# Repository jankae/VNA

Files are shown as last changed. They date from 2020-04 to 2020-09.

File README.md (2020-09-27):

# 1MHz - 6GHz VNA

**There is a [new and improved version](https://github.com/jankae/VNA2) of this project under development**

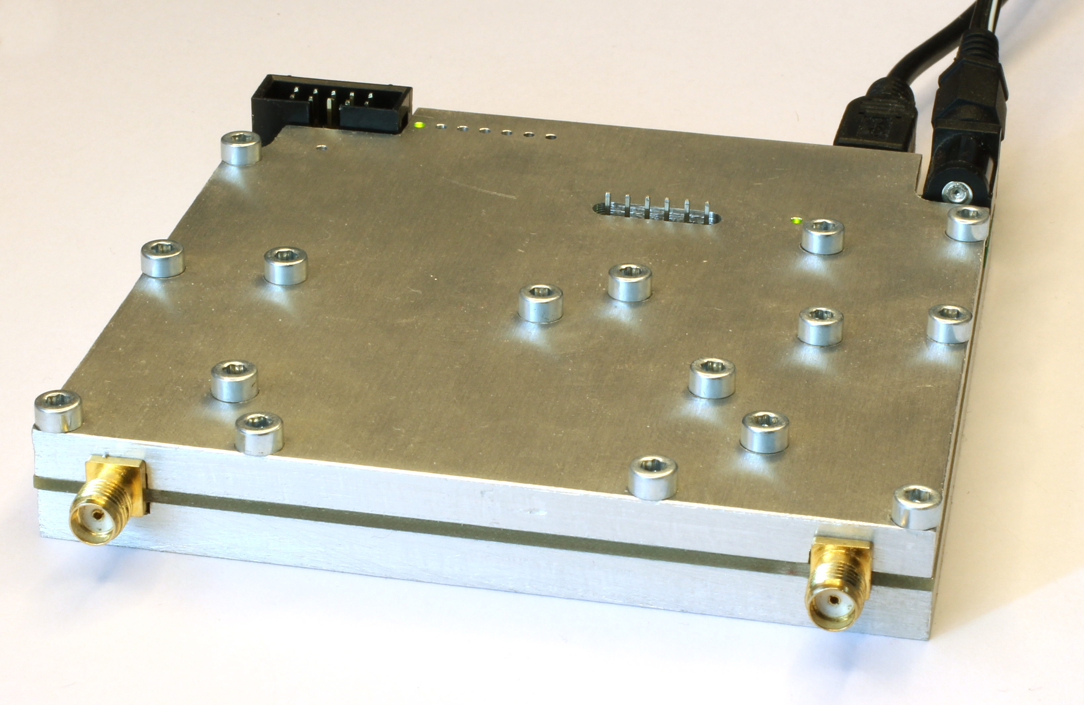
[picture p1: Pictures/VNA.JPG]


## Motivation
A VNA can be very helpful for RF experiments so I decided to build one for my next project. I already own a [pocketVNA](https://pocketvna.com/), however I found some issues with it and didn't use it very often:
* High thermal drift: you have to leave it running for 30-45 minutes before using it
* Low sweep speed: Especially with averaging enabled, a sweep can take a few minutes
* Ports are not 50 Ohm terminated, see also discussion [here](https://www.eevblog.com/forum/rf-microwave/pocketvna-any-idea-what-its-like/msg1220143/#msg1220143)

There already are some other DIY VNA projects online, especially [these](https://hforsten.com/cheap-homemade-30-mhz-6-ghz-vector-network-analyzer.html) [two](http://www.yl3akb.lv/content/vna_v2/vna_v2.php) served as inspiration. Especially the first link also explains some general concepts of a VNA, what it is used for, how it works and some compromises when choosing a hardware architecture.

## Design goals
* 1MHz to 6GHz usable frequency range. Both limits are essentially set by the specs of affordable RF ICs.
* Reasonable fast sweep speed
* No display, instead the data is send via USB to a PC. Generally, I prefer standalone devices but it seemed not worth the effort here. To be usable, the display would need to be reasonable large and high resolution, also GUI development is faster/easier on a PC than on a µC.
* BOM cost reduction is *not* the primary goal. A project like this takes several month and its a one-off device, slightly higher than absolutely necessary part costs are not an issue.
* Learn more about the challenges in RF designs.

## How does it work?


* The main clock source is an Si5351C, providing all the required clocks for the different blocks. It also serves as the stimulus source for frequencies below 25MHz. Its own reference clock is either a 26MHz crystal or an external 10MHz signal.
* The stimulus source for frequencies above 25MHz is a MAX2871. Its output signal is slightly filtered to reduce the amount of harmonics.
* The stimulus signal power can be adjusted between approximately -42 and -10dbm with a digital attenuator (F1958).
* After the amplifier(TRF37A73) the signal is split and the weaker part of it fed into the reference receiver.
* The stronger part of the signal can be routed to either port. In each signal path, two RF switches are used in series to achieve higher isolation between the ports.
* Instead of directional couplers, resistive return-loss-bridges are used (easier to implement for wide bandwidth).
* Both ports have completely separated receive paths. This increases BOM cost but allows measuring two parameters at once (S11 and S21 or S22 and S12). It also avoid potential isolation issues that could arise if the receive paths would merge into a single mixer/ADC.
* Each receiver consists of two down-convert mixers. The 1.IF sits at 60MHz, the 2.IF 250kHz.
* The ADCs are sampling the final IF with 16bit@1MHz.
* The acquisition and control of the PLLs, switches, attenuator etc. is handled by a Spartan 6 FPGA. This allows for nearly instant switching of the measurement frequency, only limited by the settling time of the PLLs.

## PCB Layout
The signal path can also be followed on the PCB (the attuator is replaced by a wire bridge in this picture because I damaged the IC during soldering):
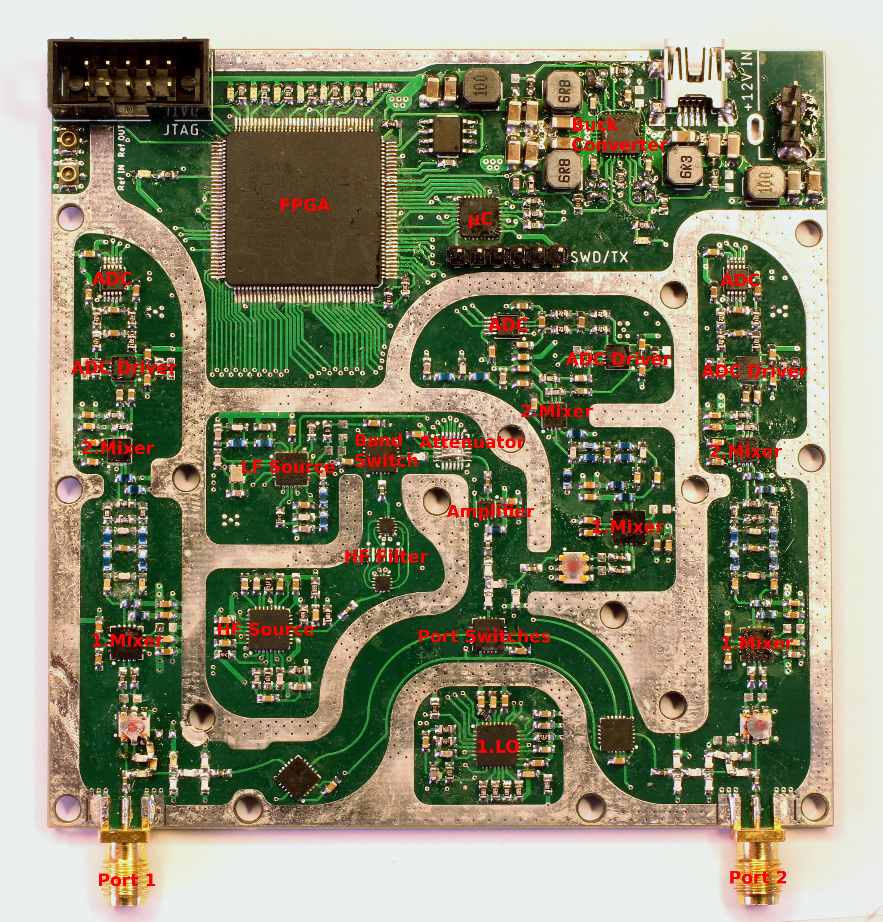
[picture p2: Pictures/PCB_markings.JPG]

* I limited myself to 10x10cm, because larger 4-Layer PCBs are getting a bit more expensive at the typical manufacturers. This was a mistake because it meant that certain sections had to move closer together. Especially the distance between the HF Source and the 1.Mixer of Port 1 is not sufficient, resulting in less than optimal isolation.
* The individual sections are divided by strips of exposed GND. The aluminium case touches all the exposed copper and further improves shielding. I expected the shielding to be better than it turned out, this is another reason why I put sections close to each other that really should be some distance apart.
* For some reason I didn't check the final design carefully enough before ordering and didn't have enough GND vias in quite a few areas. This probably degrades overall performance but I am not going to reorder (and solder!) a new PCB.

### Some hardware-related points worth noting
* There is a lot of local voltage regulation to prevent coupling of supply noise between the sections. In total there are 14 different supply rails (although most of them are at 3.3V or 5V).
* The triple Buck converter for stepping down the main 12V input rail to 6V/3V3 and 1V8 has a synchronisation feature. The synchronization pin was connected to the FPGA in order to sync the converter to the ADC sampling rate and prevent switching noise from being measured. I ended up having to cut that trace because the Spartan 6 switches its pins to pullups while being configured from the ISE IDE. This caused the buck converter to stop and the board to lose power. Note that the HSWAPEN pin only affects the pullups when configuring from the *Flash* not from the IDE. See also [this](https://forums.xilinx.com/t5/Spartan-Family-FPGAs-Archived/Spartan-6-pull-ups-during-SPI-indirect-programming-using/td-p/201743) issue. The missing synchronisation ended up not being a problem as the buck converter frequency is far enough away from the final IF.
* Due to 16bit resolution at 1MSPS, the ADCs need a fast SPI interface. Initially I used a 100MHz SPI clock and this worked well for the port 1 and the reference ADC but didn't work with the port 2 ADC (it is farther away from the FPGA thus the traces were longer). Decreasing the SPI clock to about 70MHz solved the issue while still being fast enough for the ADCs.
* The LTC5510 mixers and MAX2871 PLLs get warm (overall power consumption is about 6W, most of it dissipated in these ICs), they reached up to 70°C with an ambient temperature of 25°C. I changed the aluminium shielding design to extend down to these ICs and also serve as a heatsink. This reduced the maximum temperature by about 20°C.

## The shielding
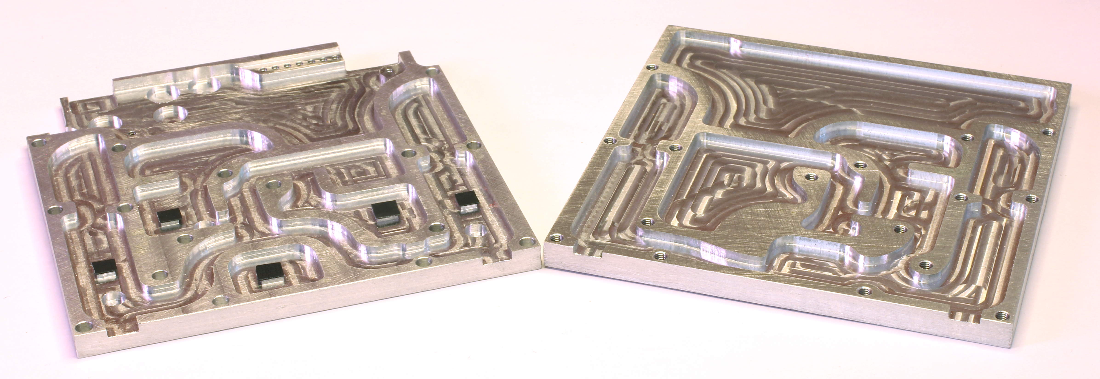
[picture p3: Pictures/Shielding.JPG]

The shielding serves multiple purposes:
* Providing RF isolation between different sections
* Improving EMI/EMC
* Serving as a case for the device, preventing shorts on the PCB when used on the bench
* Cooling (the black rectangles on the left aluminium part are adhesive cooling pads and touch the top of some ICs)
* It was CNC-machined out of 6mm aluminium. Being able to use a CNC mill, I wasn't restricted to right angles and optimised the shielding to allow for a smaller board.
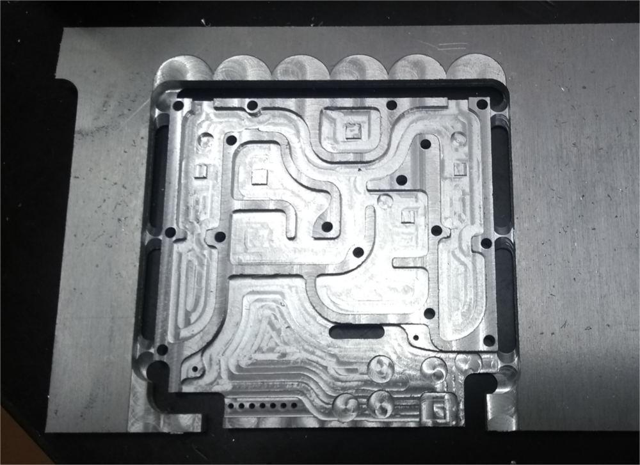
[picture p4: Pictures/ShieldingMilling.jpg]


## PC Software
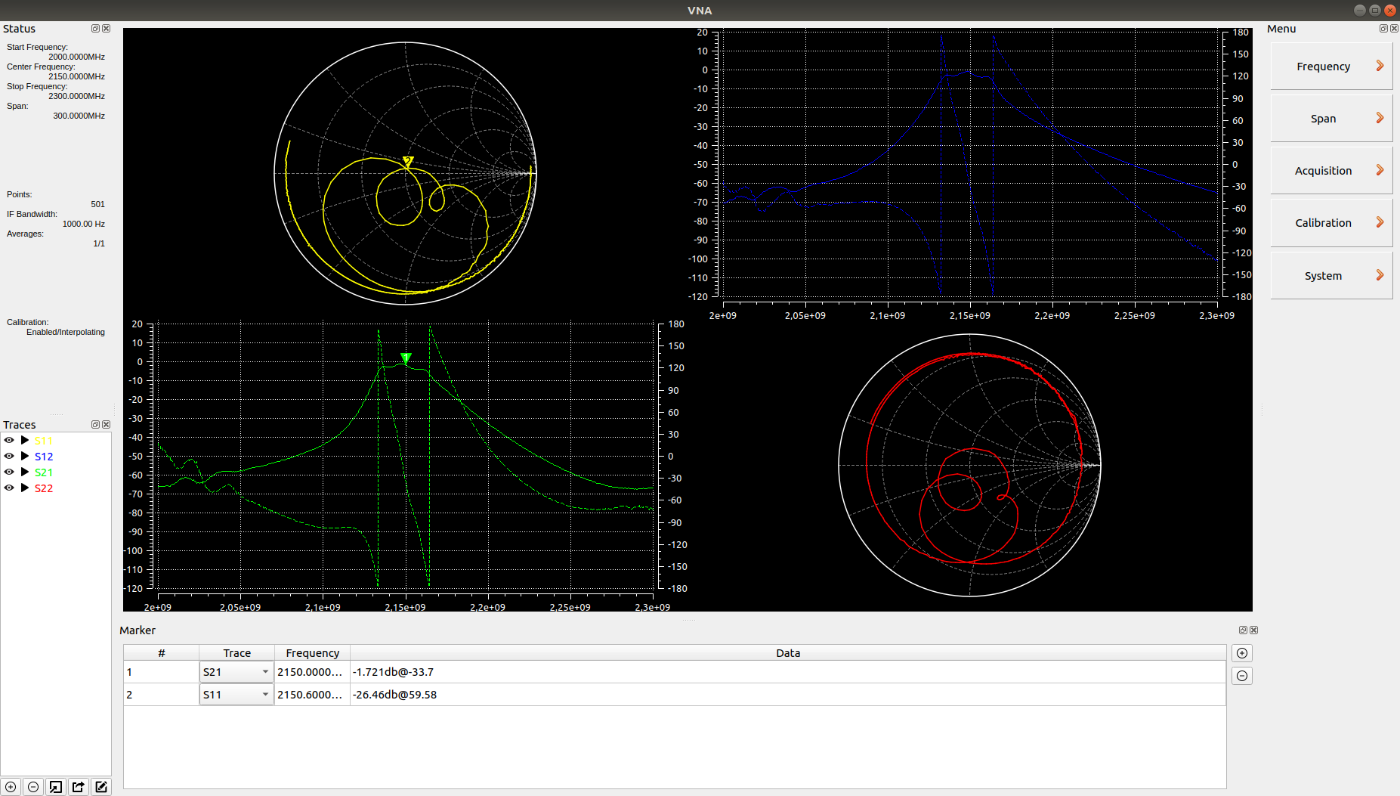
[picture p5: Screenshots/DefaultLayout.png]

* Written in Qt. This was my first PC software with a GUI and it took a while (and many lines of code that were rewritten a lot) to understand the concepts. While certainly not optimal, the result is absolutely usable for me.
* Flexible display of measurements in charts (Smithchart/Bodeplot). Each chart can be assigned a number of traces (e.i. plot S22 and S11 in one smithchart). The charts can be resized, moved, deleted or split into more charts.
* Import/export of touchstone files up to 4 ports. This allows saving measurements and also comparing the current measurement with others.
* Rudimentary marker system to read S-parameters at any frequency.
* Full control over start/center/stop frequencies, span, IF bandwidth, number of points, stimulus power level, ...
* SOLT calibration with fully customizable calibration kit (either from coefficients or touchstone measurements):
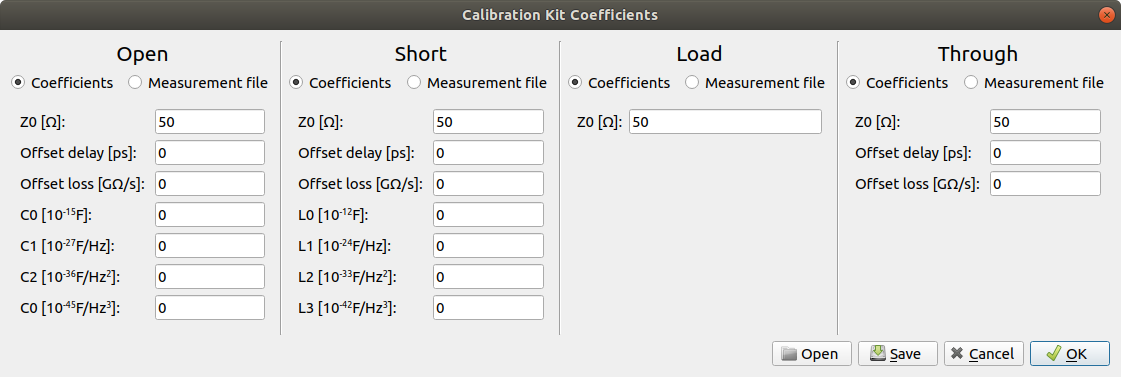
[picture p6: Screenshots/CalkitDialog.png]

* Manually control of the hardware components (helpful for hardware debugging or using the device as a simple signal source):
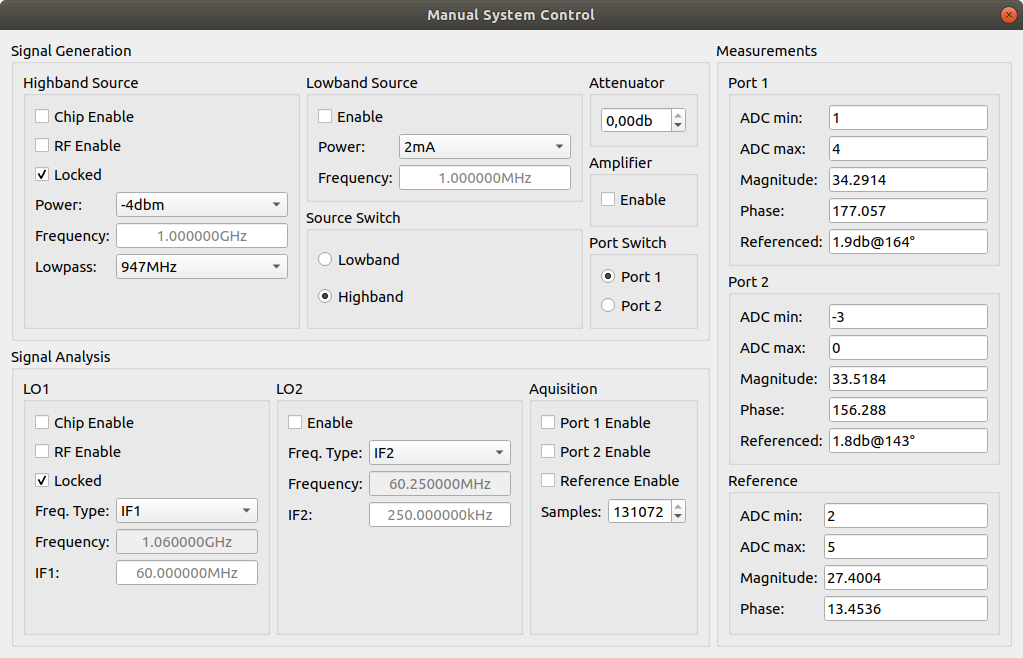
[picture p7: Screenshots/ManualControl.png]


## How well does it work?
I am really not that sure, as I have no RF equipment to compare it to. A VNA can only be as good as the calibration kit and the only calibration kit I have is the on that came with the pocketVNA, which does not have any calibration coefficients. Why is that a problem? No calibration kit is perfect and the coefficients allow the VNA to take the imperfections into account. Without the coefficients these imperfections will be propagated to the measurements. As calibration kits with coefficients easily cost more than this whole project (at least the ones I could find) this situation will probably not change soon.

That being said, here are a few measurements:
* Isolation between ports with (green) and without (red) shielding (1MHz to 6GHz, 501 points, 100Hz IF bandwidth, both ports terminated into 50 Ohm):
  * S12:
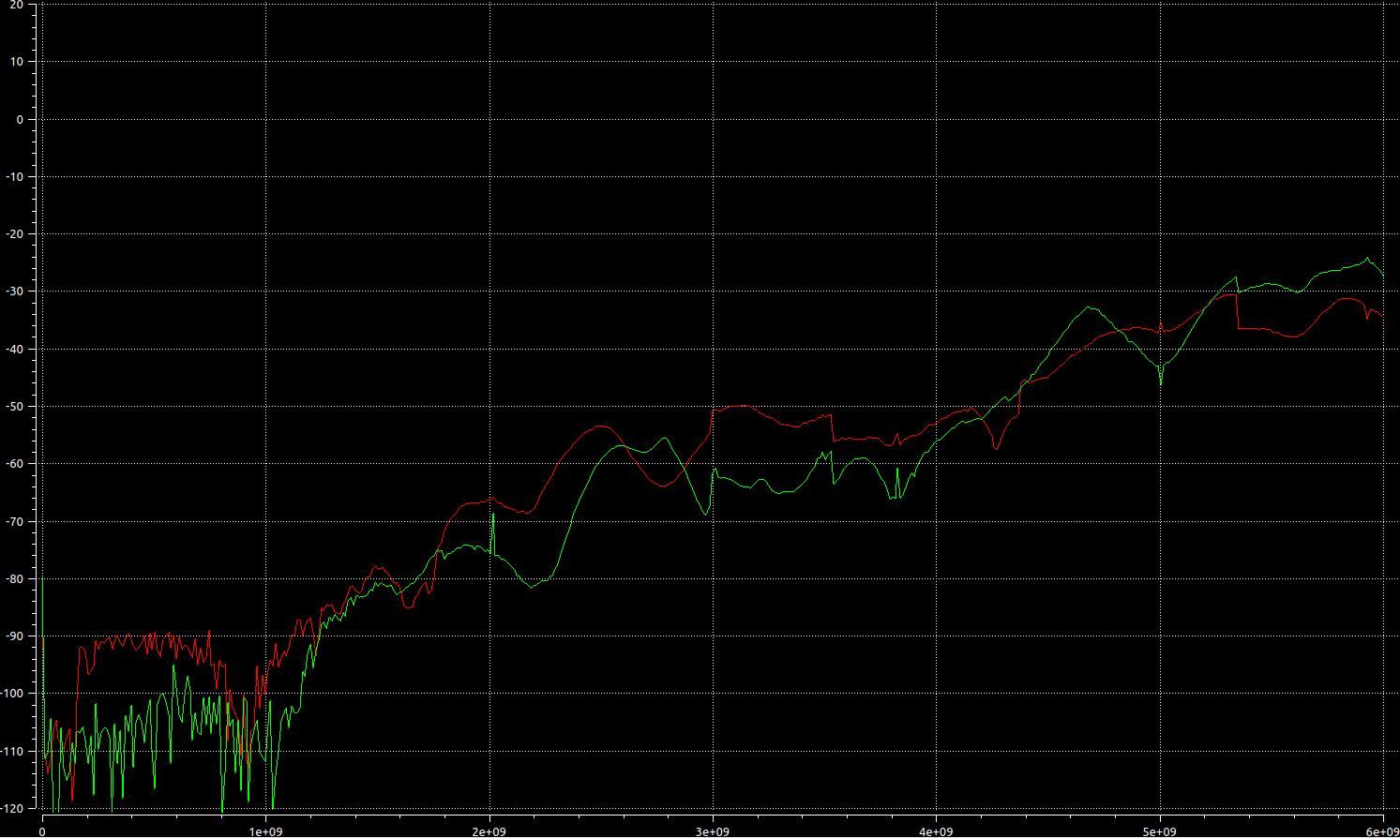
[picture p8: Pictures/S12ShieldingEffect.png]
  
  * S21:
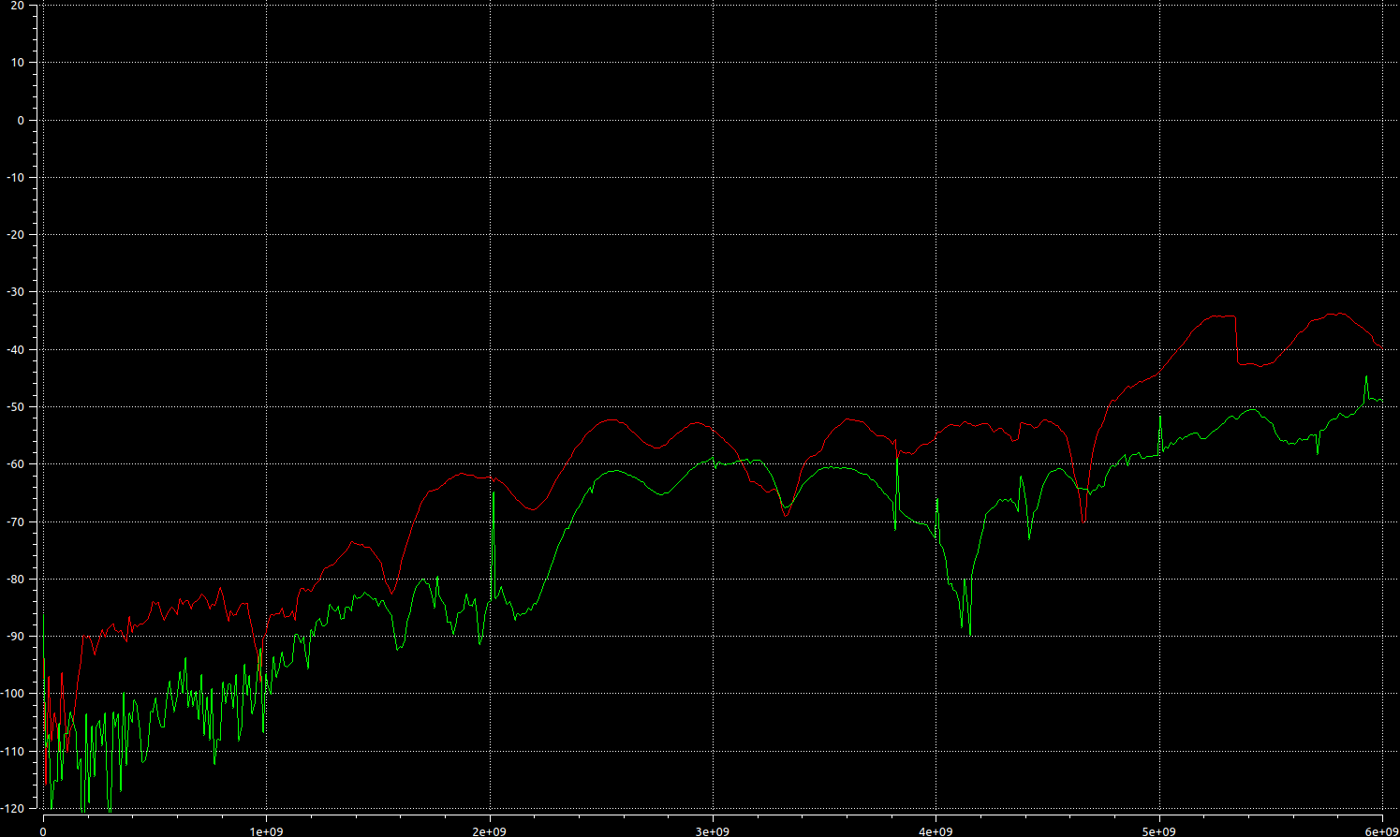
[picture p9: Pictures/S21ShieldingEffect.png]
  
  * Below about 1GHz the noise floor is the actual noise floor of the ADC. Above 1GHz more and more signal leaks into the other port. This leakage is a bit worse at port 1 (S12) because the HF source is placed close to the port 1 mixers. The shielding improves the isolation somewhat but not to the extend I had hoped. Interestingly there are some peaks in the isolation sweep when the shielding is used. My best guess is that they are caused by the cavities in the shielding acting as waveguides. I am hoping to improve the shielding by adding RF absorbers to some parts of the aluminium.
* The cavity bandpass filter from [this](https://github.com/jankae/SpectrumAnalyzer) project (1.9GHz to 2.3GHz, 501 points, 1kHz IF bandwidth):
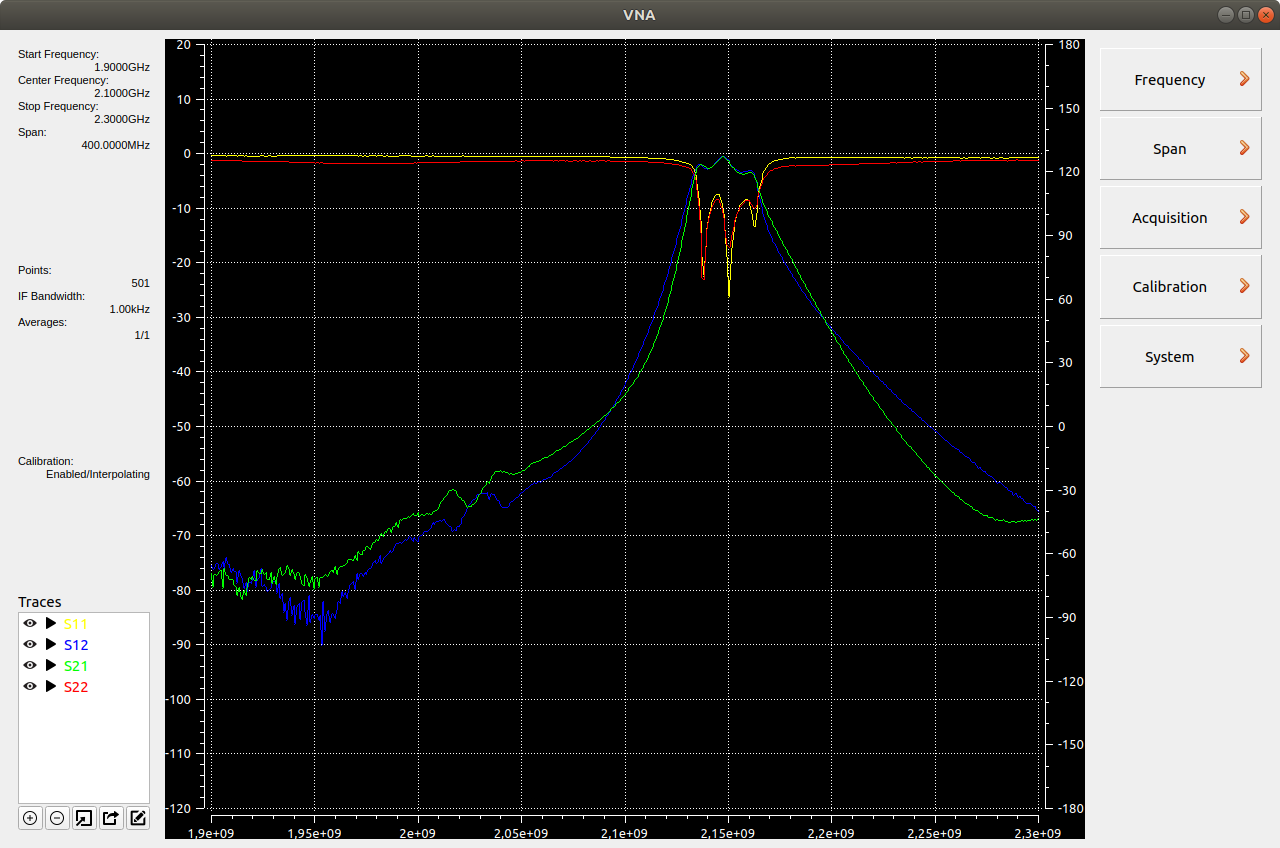
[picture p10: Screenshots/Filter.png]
 
* A WLAN antenna that seems to be somewhat reasonable matched between 2.3GHz and 2.6GHz:
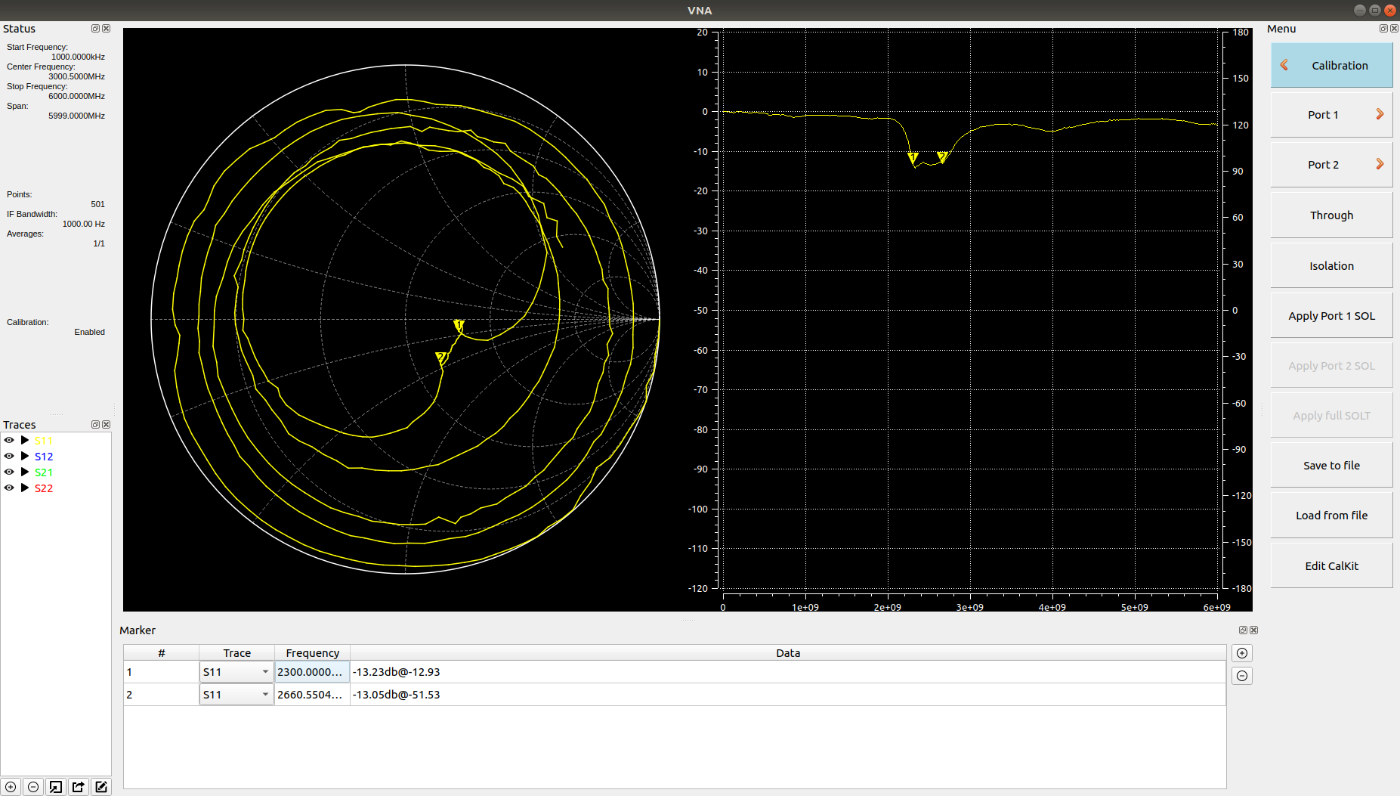
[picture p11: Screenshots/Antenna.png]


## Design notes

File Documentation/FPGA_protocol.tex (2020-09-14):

\documentclass{article}
\usepackage
[
        a4paper,% other options: a3paper, a5paper, etc
        left=2cm,
        right=2cm,
        top=2cm,
        bottom=2cm,
        % use vmargin=2cm to make vertical margins equal to 2cm.
        % us  hmargin=3cm to make horizontal margins equal to 3cm.
        % use margin=3cm to make all margins  equal to 3cm.
]
{geometry}
\usepackage{tikz}
\usepackage{siunitx} 

\pgfdeclarelayer{background}
\pgfdeclarelayer{foreground}
\pgfsetlayers{background,main,foreground}

\newcommand{\bitrect}[2]{
  \begin{pgfonlayer}{foreground}
    \draw [thick] (0,0) rectangle (#1,1);
    \pgfmathsetmacro\result{#1-1}
    \foreach \x in {1,...,\result}
      \draw [thick] (\x,1) -- (\x, 0.8);
  \end{pgfonlayer}
%  \node [below left, align=right] at (0,0) {Type \\ Reset};
  \bitlabels{#1}{#2}
}
\newcommand{\rwbits}[3]{
  \draw [thick] (#1,0) rectangle ++(#2,1) node[pos=0.5]{#3};
  \pgfmathsetmacro\start{#1+0.5}
  \pgfmathsetmacro\finish{#1+#2-0.5}
%  \foreach \x in {\start,...,\finish}
%    \node [below, align=center] at (\x, 0) {R/W \\ 0};
}
\newcommand{\robits}[3]{
  \begin{pgfonlayer}{background}
    \draw [thick, fill=lightgray] (#1,0) rectangle ++(#2,1) node[pos=0.5]{#3};
  \end{pgfonlayer}
  \pgfmathsetmacro\start{#1+0.5}
  \pgfmathsetmacro\finish{#1+#2-0.5}
%  \foreach \x in {\start,...,\finish}
%    \node [below, align=center] at (\x, 0) {RO \\ 0};
}
\newcommand{\bitlabels}[2]{
  \foreach \bit in {1,...,#1}{
     \pgfmathsetmacro\result{#2}
     \node [above] at (\bit-0.5, 1) {\pgfmathprintnumber{\result}};
   }
}

\begin{document}

\section{Digital Interface}
\begin{center}
\begin{tabular}{ c|c|c }
Pin & Direction & Function\\
 \hline
SCK & in & SCK for SPI communication/SCK for PLL communication\\
MOSI & in & MOSI for SPI communication/MOSI for PLL communication\\
MISO & out & MISO for SPI communication/MUX for PLL communication\\
NSS & in & Chip Select for SPI communication/LE for PLL communication\\
INTR & out & Active high interrupt indicator\\
RESET & in & FPGA reset\\
AUX1 & in & Selector for direct communication with Source PLL\\
AUX2 & in & Selector for direct communication with LO PLL\\
AUX3 & in & Active low sweep enable. Has to be high when changing settings\\
\end{tabular}
\end{center}
Depending on the voltage on AUX1/AUX2 the SPI port controls either the FPGA or one of the MAX2871 PLLs:
\begin{center}
\begin{tabular}{ c|c|c }
AUX1 & AUX2 & Function\\
 \hline
low & low & SPI communication with FPGA\\
high & low & Direct feedthrough of SCK, MOSI, MISO and NSS to Source PLL\\
low & high & Direct feedthrough of SCK, MOSI, MISO and NSS to LO PLL\\
high & high & Invalid\\
\end{tabular}
\end{center}
When communicating with a PLL, the MUX output of the MAX2871 is forwarded to MISO and the NSS signal is forwarded to the LE pin. As the LE pin should stay low until after a valid register has been shifted in (see MAX2871 datasheet), set NSS low before switching to PLL communication mode.

\section{SPI Protocol}
Each SPI transfer starts with pulling NSS low and ends with NSS returning to high level. SPI communication is done in words of 16\,bits. The first word after NSS is pulled low is the command word and determines the amount and meaning of the following words.
The word received while transmitting the command word is the interrupt status register:
\begin{center}
\begin{tikzpicture}
\bitrect{16}{16-\bit}
\robits{0}{11}{reserved}
\rwbits{11}{1}{SH}
\rwbits{12}{1}{OR}
\rwbits{13}{1}{ND}
\rwbits{14}{1}{SU}
\rwbits{15}{1}{LU}
\end{tikzpicture}
\end{center}
\begin{itemize}
\item \textbf{SH:} Sweep halted due to halt bit set. Sweep will be resumed once the resume command is issued.
\item \textbf{OR:} Data overrun occured (only cleared by resetting the FPGA)
\item \textbf{ND:} New data available
\item \textbf{SU:} Source unlocked
\item \textbf{LU:} LO unlocked
\end{itemize}
\subsection{Writing a register}
Writing a register requires the transfer of two words: First the control word selecting the destination address and a second word containing the new register value:
\begin{center}
\begin{tikzpicture}
\bitrect{16}{16-\bit}
\rwbits{0}{1}{1}
\rwbits{1}{1}{0}
\rwbits{2}{1}{0}
\robits{3}{9}{reserved}
\rwbits{12}{4}{Register Address}
\end{tikzpicture}
\begin{tikzpicture}
\bitrect{16}{16-\bit}
\rwbits{0}{16}{Register Value}
\end{tikzpicture}
\end{center}
\subsection{Writing SweepConfig}
Initiate the sweep config transfer by sending the command word:
\begin{center}
\begin{tikzpicture}
\bitrect{16}{16-\bit}
\rwbits{0}{1}{0}
\rwbits{1}{1}{0}
\rwbits{2}{1}{0}
\rwbits{3}{13}{Sweep point}
\end{tikzpicture}
\end{center}
The maximum number of points per sweep is 4501, thus the highest valid value for "Sweep point" is 4500. After the control word, send the six words of the sweep config (see section~\ref{sweepconfig}) while keeping NSS low. The sweep config is transmitted MSB first.

\subsection{Reading a sampling result}
Whenever the ND bit in the interrupt status register is set, new sampling data is available and can be read via SPI. It has to be read before the next sampling data arrives otherwise the old data will be overwritten.

Initiate the reading of sampling data by sending the command word:
\begin{center}
\begin{tikzpicture}
\bitrect{16}{16-\bit}
\rwbits{0}{1}{1}
\rwbits{1}{1}{1}
\rwbits{2}{1}{0}
\robits{3}{13}{reserved}
\end{tikzpicture}
\end{center}
Afterwards, read 18 words before setting NSS high. These 18 words will contain the sampling result (see section~\ref{result}), transmitted with the least significant word first.

\subsection{Resuming a halted sweep}
When the halt bit is set in the SweepConfig, the FPGA will configure the Source and LO as requested but will not start the settling timer (and subsequently the sampling process) until this resume command is issued. The halted sweep is indicated by the sweep halted bit in the status register.
\begin{center}
\begin{tikzpicture}
\bitrect{16}{16-\bit}
\rwbits{0}{1}{0}
\rwbits{1}{1}{0}
\rwbits{2}{1}{1}
\robits{3}{13}{reserved}
\end{tikzpicture}
\end{center}

\subsection{Reading ADC limits}
The FPGA keeps track of the highest and lowest sample of each ADC to detect saturation and verify signal levels.

Initiate the reading of ADC limit data by sending the command word:
\begin{center}
\begin{tikzpicture}
\bitrect{16}{16-\bit}
\rwbits{0}{1}{1}
\rwbits{1}{1}{1}
\rwbits{2}{1}{1}
\robits{3}{13}{reserved}
\end{tikzpicture}
\end{center}
Afterwards, read 6 words before setting NSS high. These 6 words will contain the sampling result:

\begin{center}
\begin{tikzpicture}
\bitrect{16}{96-\bit}
\rwbits{0}{16}{Port 1 minimum}
\end{tikzpicture}
\begin{tikzpicture}
\bitrect{16}{80-\bit}
\rwbits{0}{16}{Port 1 maximum}
\end{tikzpicture}
\begin{tikzpicture}
\bitrect{16}{64-\bit}
\rwbits{0}{16}{Port 2 minimum}
\end{tikzpicture}
\begin{tikzpicture}
\bitrect{16}{48-\bit}
\rwbits{0}{16}{Port 2 maximum}
\end{tikzpicture}
\begin{tikzpicture}
\bitrect{16}{32-\bit}
\rwbits{0}{16}{Reference minimum}
\end{tikzpicture}
\begin{tikzpicture}
\bitrect{16}{16-\bit}
\rwbits{0}{16}{Reference maximum}
\end{tikzpicture}
\end{center}

\subsection{Resetting the ADC limit}
Issuing this command result in all minimum values set to 32767 and all maximum values set to -32768.
\begin{center}
\begin{tikzpicture}
\bitrect{16}{16-\bit}
\rwbits{0}{1}{0}
\rwbits{1}{1}{1}
\rwbits{2}{1}{1}
\robits{3}{13}{reserved}
\end{tikzpicture}
\end{center}

\section{Registers}
\subsection{Interrupt Mask Register: 0x00}
\begin{center}
\begin{tikzpicture}
\bitrect{16}{16-\bit}
\robits{0}{11}{reserved}
\rwbits{11}{1}{SHIE}
\rwbits{12}{1}{ORIE}
\rwbits{13}{1}{NDIE}
\rwbits{14}{1}{SUIE}
\rwbits{15}{1}{LUIE}
\end{tikzpicture}
\end{center}
\begin{itemize}
\item \textbf{SHIE:} Sweep halted interrupt enable
\item \textbf{ORIE:} Data overrun interrupt enable 
\item \textbf{NDIE:} New data interrupt enable
\item \textbf{SUIE:} Source unlocked interrupt enable
\item \textbf{LUIE:} LO unlocked interrupt enable 
\end{itemize}

\subsection{Sweep Points Register: 0x01}
\begin{center}
\begin{tikzpicture}
\bitrect{16}{16-\bit}
\rwbits{0}{16}{Number of points per sweep - 1}
\end{tikzpicture}
\end{center}
The register contains the number of points per sweep negative one, e.g. set to 11b if the sweep contains four points.

\subsection{Samples Per Point Register: 0x02}
\begin{center}
\begin{tikzpicture}
\bitrect{16}{16-\bit}
\robits{0}{6}{reserved}
\rwbits{6}{10}{SPP[9:0]}
\end{tikzpicture}
\end{center}
\begin{itemize}
\item \textbf{SPP[9:0]:} The register contains the number of samples per point in increments of 128 samples (e.g. SPP=0b0000001000=0x08 uses 1024 samples per point). The value of this register is only used if SweepConfig[92:90] is set to 000. Otherwise it is overwritten for the sweep point with one of seven preselected values.
\end{itemize}

\subsection{System Control Register: 0x03}
\begin{center}
\begin{tikzpicture}
\footnotesize
\bitrect{16}{16-\bit}
\rwbits{0}{1}{P1EN}
\rwbits{1}{1}{P2EN}
\rwbits{2}{1}{REN}
\rwbits{3}{1}{AMEN}
\rwbits{4}{1}{SOEN}
\rwbits{5}{1}{LOEN}
\rwbits{6}{1}{RLED}
\rwbits{7}{1}{LED6}
\rwbits{8}{1}{LED7}
\rwbits{9}{2}{Window[1:0]}
\rwbits{11}{1}{SCEN}
\rwbits{12}{1}{LCEN}
\rwbits{13}{1}{EXP2}
\rwbits{14}{1}{EXP1}
\robits{15}{1}{rsvd}
\end{tikzpicture}
\end{center}
\begin{itemize}
\item \textbf{P1EN:} Port 1 Mixers/Amplifier enable
\item \textbf{P2EN:} Port 2 Mixers/Amplifier enable
\item \textbf{REN:} Reference Mixers/Amplifier enable
\item \textbf{AMEN:} Source amplifier enable
\item \textbf{SOEN:} Source enable
\item \textbf{LOEN:} LO enable
\item \textbf{RLED:} External frequency LED control
\item \textbf{LED6:}{User LED 6 control}
\item \textbf{LED7:}{User LED 7 control}
\item \textbf{Window[1:0]:}{Type of window to be used in calculation of real/imag of the sampling result}
\begin{center}
\begin{tabular}{ c|c }
Setting & Window type\\
 \hline
00 & Rectangular (no window)\\
01 & Kaiser\\
10 & Hann\\
11 & Flat Top\\
\end{tabular}
\end{center}
\item \textbf{EXP1:}{Excite Port1 during sweep}
\item \textbf{EXP2:}{Excite Port2 during sweep}
\item \textbf{SCEN:}{Source chip enable}
\item \textbf{LCEN:}{LO chip enable}
\end{itemize}

\subsection{MAX2871 Default Values Registers: 0x08-0x0F}
See datasheet of MAX2871 for bit descriptions. Bits for the fields N, FRAC, M, VCO and DIV\_A are "don't care" as they will be overwritten by the SweepConfig setting.
\begin{center}
\begin{tikzpicture}
\bitrect{16}{16-\bit}
\rwbits{0}{16}{MAX2871 Register 0[15:0]}
\end{tikzpicture}
\begin{tikzpicture}
\bitrect{16}{16-\bit}
\rwbits{0}{16}{MAX2871 Register 0[31:16]}
\end{tikzpicture}
\begin{tikzpicture}
\bitrect{16}{16-\bit}
\rwbits{0}{16}{MAX2871 Register 1[15:0]}
\end{tikzpicture}
\begin{tikzpicture}
\bitrect{16}{16-\bit}
\rwbits{0}{16}{MAX2871 Register 1[31:16]}
\end{tikzpicture}
\begin{tikzpicture}
\bitrect{16}{16-\bit}
\rwbits{0}{16}{MAX2871 Register 3[15:0]}
\end{tikzpicture}
\begin{tikzpicture}
\bitrect{16}{16-\bit}
\rwbits{0}{16}{MAX2871 Register 3[31:16]}
\end{tikzpicture}
\begin{tikzpicture}
\bitrect{16}{16-\bit}
\rwbits{0}{16}{MAX2871 Register 4[15:0]}
\end{tikzpicture}
\begin{tikzpicture}
\bitrect{16}{16-\bit}
\rwbits{0}{16}{MAX2871 Register 4[31:16]}
\end{tikzpicture}
\end{center}

\section{SweepConfig}
\label{sweepconfig}
The SweepConfig contains data for the source and LO1 PLL as well as the attenuator and source filter. Each point in the sweep, needs a valid SweepConfig before the sweep is started.

\begin{center}
\begin{tikzpicture}
\bitrect{16}{96-\bit}
\rwbits{0}{1}{HS}
\rwbits{1}{2}{SettlingTime}
\rwbits{3}{3}{Samples}
\rwbits{6}{2}{SourceFilter}
\rwbits{8}{8}{LO M[11:4]}
\end{tikzpicture}
\begin{tikzpicture}
\bitrect{16}{80-\bit}
\rwbits{0}{4}{LO M[3:0]}
\rwbits{4}{12}{LO FRAC[11:0]}
\end{tikzpicture}
\begin{tikzpicture}
\bitrect{16}{64-\bit}
\rwbits{0}{3}{LO DIV\_A[2:0]}
\rwbits{3}{6}{LO VCO[5:0]}
\rwbits{9}{7}{LO N[6:0]}
\end{tikzpicture}
\begin{tikzpicture}
\bitrect{16}{48-\bit}
\rwbits{0}{1}{BS}
\rwbits{1}{7}{Attenuator[6:0]}
\rwbits{8}{8}{Source M[11:4]}
\end{tikzpicture}
\begin{tikzpicture}
\bitrect{16}{32-\bit}
\rwbits{0}{4}{Source M[3:0]}
\rwbits{4}{12}{Source FRAC[11:0]}
\end{tikzpicture}
\begin{tikzpicture}
\bitrect{16}{16-\bit}
\rwbits{0}{3}{Source DIV\_A[2:0]}
\rwbits{3}{6}{Source VCO[5:0]}
\rwbits{9}{7}{Source N[6:0]}
\end{tikzpicture}
\end{center}
\begin{itemize}
\item \textbf{HS: Halt sweep.} If set, settling and sampling of this sweep point will be postponed until the sweep resume command is issued.
\item \textbf{SettlingTime:} Amount of time between locking of PLLs and beginning of ADC sampling
\begin{center}
\begin{tabular}{ c|c }
Setting & Time\\
 \hline
00 & \SI{20}{\micro\second}\\
01 & \SI{60}{\micro\second}\\
10 & \SI{180}{\micro\second}\\
11 & \SI{540}{\micro\second}\\
\end{tabular}
\end{center}
\item \textbf{Samples:} Number of ADC samples to take
\begin{center}
\begin{tabular}{ c|c|c }
Setting & Samples & Equivalent IF bandwidth\\
 \hline
000 & Defined by SPP register & \SI{914}{\kilo\hertz}/SPP\\
001 & 128 & \SI{10}{\kilo\hertz}\\
010 & 384 & \SI{3}{\kilo\hertz}\\
011 & 896 & \SI{1}{\kilo\hertz}\\
100 & 3072 & \SI{300}{\hertz}\\
101 & 9088 & \SI{100}{\hertz}\\
110 & 30464 & \SI{30}{\hertz}\\
111 & 91392 & \SI{10}{\hertz}\\
\end{tabular}
\end{center}
\item \textbf{SourceFilter:} Low pass filter selection for source signal
\begin{center}
\begin{tabular}{ c|c }
Setting & Selected Band\\
 \hline
00 & \SIrange{0}{900}{\mega\hertz}\\
01 & \SIrange{900}{1800}{\mega\hertz}\\
10 & \SIrange{1800}{3500}{\mega\hertz}\\
11 & \SIrange{3500}{6000}{\mega\hertz}\\
\end{tabular}
\end{center}
\item \textbf{BS: Band select.} Set to 0 for highband, set to 1 for lowband.
\item \textbf{Attenuator:} Attenuation of source signal in \SI{0.25}{\decibel}.
\end{itemize}

\section{Sampling Result}
\label{result}
Each point in the sweep generates two sampling results. The first one contains the measurement when the source was routed to Port 1, the second sampling result was taken when the source was routed to Port 2. The sampling result does not indicate which point in the sweep it belongs to, that information is implicitly given by the order of transmitted sampling results.
\begin{center}
\begin{tikzpicture}
\bitrect{16}{288-\bit}
\rwbits{0}{16}{Port 1 I[47:32]}
\end{tikzpicture}
\begin{tikzpicture}
\bitrect{16}{272-\bit}
\rwbits{0}{16}{Port 1 I[31:16]}
\end{tikzpicture}
\begin{tikzpicture}
\bitrect{16}{256-\bit}
\rwbits{0}{16}{Port 1 I[15:0]}
\end{tikzpicture}

\begin{tikzpicture}
\bitrect{16}{240-\bit}
\rwbits{0}{16}{Port 1 Q[47:32]}
\end{tikzpicture}
\begin{tikzpicture}
\bitrect{16}{224-\bit}
\rwbits{0}{16}{Port 1 Q[31:16]}
\end{tikzpicture}
\begin{tikzpicture}
\bitrect{16}{208-\bit}
\rwbits{0}{16}{Port 1 Q[15:0]}
\end{tikzpicture}

\begin{tikzpicture}
\bitrect{16}{192-\bit}
\rwbits{0}{16}{Port 2 I[47:32]}
\end{tikzpicture}
\begin{tikzpicture}
\bitrect{16}{176-\bit}
\rwbits{0}{16}{Port 2 I[31:16]}
\end{tikzpicture}
\begin{tikzpicture}
\bitrect{16}{160-\bit}
\rwbits{0}{16}{Port 2 I[15:0]}
\end{tikzpicture}

\begin{tikzpicture}
\bitrect{16}{144-\bit}
\rwbits{0}{16}{Port 2 Q[47:32]}
\end{tikzpicture}
\begin{tikzpicture}
\bitrect{16}{128-\bit}
\rwbits{0}{16}{Port 2 Q[31:16]}
\end{tikzpicture}
\begin{tikzpicture}
\bitrect{16}{112-\bit}
\rwbits{0}{16}{Port 2 Q[15:0]}
\end{tikzpicture}

\begin{tikzpicture}
\bitrect{16}{96-\bit}
\rwbits{0}{16}{Reference Signal I[47:32]}
\end{tikzpicture}
\begin{tikzpicture}
\bitrect{16}{80-\bit}
\rwbits{0}{16}{Reference Signal I[31:16]}
\end{tikzpicture}
\begin{tikzpicture}
\bitrect{16}{64-\bit}
\rwbits{0}{16}{Reference Signal I[15:0]}
\end{tikzpicture}

\begin{tikzpicture}
\bitrect{16}{48-\bit}
\rwbits{0}{16}{Reference Signal Q[47:32]}
\end{tikzpicture}
\begin{tikzpicture}
\bitrect{16}{32-\bit}
\rwbits{0}{16}{Reference Signal Q[31:16]}
\end{tikzpicture}
\begin{tikzpicture}
\bitrect{16}{16-\bit}
\rwbits{0}{16}{Reference Signal Q[15:0]}
\end{tikzpicture}
\end{center}

\end{document}

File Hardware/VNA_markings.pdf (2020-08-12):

## JTAG

# 1MHz-6GHz VNA

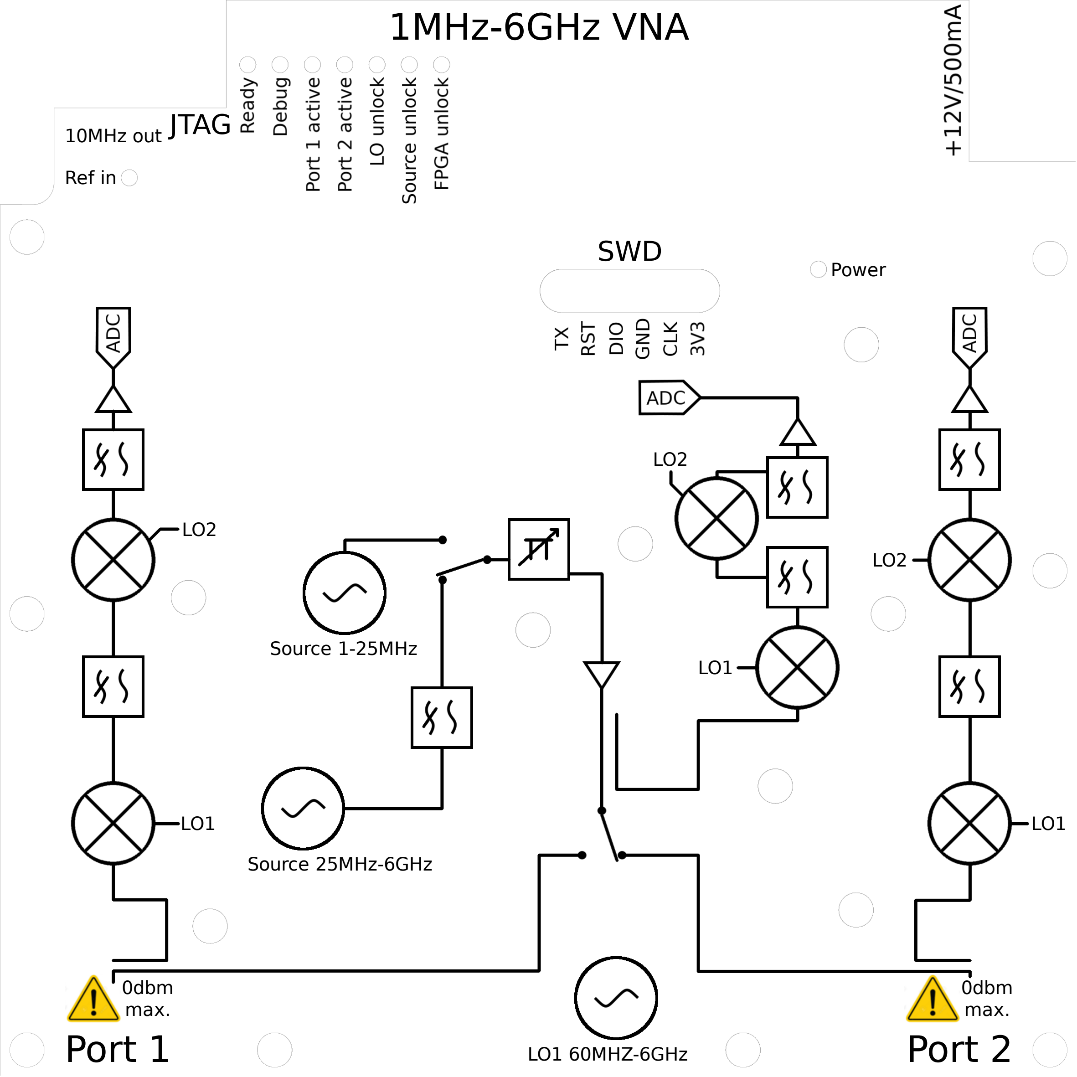
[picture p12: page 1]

0dbm
max.

0dbm
max.

10MHz out

Ref in

Power

Port 1 | Port 2

1

## SWD

LO1 60MHZ-6GHz

Source 25MHz-6GHz

Source 1-25MHz

LO1

LO2

LO1

LO1

LO2

LO2

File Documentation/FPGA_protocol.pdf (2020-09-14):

## 1 Digital Interface

Pin | Direction | Function
SCK | in | SCK for SPI communication/SCK for PLL communication
MOSI | in | MOSI for SPI communication/MOSI for PLL communication
MISO | out | MISO for SPI communication/MUX for PLL communication
NSS | in | Chip Select for SPI communication/LE for PLL communication
INTR | out | Active high interrupt indicator
RESET | in | FPGA reset
AUX1 | in | Selector for direct communication with Source PLL
AUX2 | in | Selector for direct communication with LO PLL
AUX3 | in | Active low sweep enable. Has to be high when changing settings

Depending on the voltage on AUX1/AUX2 the SPI port controls either the FPGA or one of the MAX2871 PLLs:

AUX1 | AUX2 | Function
low | low | SPI communication with FPGA
high | low | Direct feedthrough of SCK, MOSI, MISO and NSS to Source PLL
low | high | Direct feedthrough of SCK, MOSI, MISO and NSS to LO PLL
high | high | Invalid

When communicating with a PLL, the MUX output of the MAX2871 is forwarded to MISO and the NSS signal is forwarded to the LE pin. As the LE pin should stay low until after a valid register has been shifted in (see MAX2871 datasheet), set NSS low before switching to PLL communication mode.

## 2 SPI Protocol

Each SPI transfer starts with pulling NSS low and ends with NSS returning to high level. SPI communication is done in words of 16 bits. The first word after NSS is pulled low is the command word and determines the amount and meaning of the following words. The word received while transmitting the command word is the interrupt status register:

reserved

15 | 14 | 13 | 12 | 11 | 10 | 9 | 8 | 7 | 6 | 5 | 4 | 3 | 2 | 1 | 0
| | | | | | | | | | | SH | OR | ND | SU | LU
- SH: Sweep halted due to halt bit set. Sweep will be resumed once the resume command is issued.
- OR: Data overrun occured (only cleared by resetting the FPGA)
- ND: New data available
- SU: Source unlocked
- LU: LO unlocked

### 2.1 Writing a register

Writing a register requires the transfer of two words: First the control word selecting the destination address and a second word containing the new register value:

reserved

15 | 14 | 13 | 12 | 11 | 10 | 9 | 8 | 7 | 6 | 5 | 4 | 3 | 2 | 1 | 0
1 | 0 | 0 | Register Address
15 | 14 | 13 | 12 | 11 | 10 | 9 | 8 | 7 | 6 | 5 | 4 | 3 | 2 | 1 | 0

Register Value

### 2.2 Writing SweepConfig

Initiate the sweep config transfer by sending the command word:

15 | 14 | 13 | 12 | 11 | 10 | 9 | 8 | 7 | 6 | 5 | 4 | 3 | 2 | 1 | 0
0 | 0 | 0 | Sweep point

The maximum number of points per sweep is 4501, thus the highest valid value for ”Sweep point” is 4500. After the control word, send the six words of the sweep config (see section 4) while keeping NSS low. The sweep config is transmitted MSB first.

### 2.3 Reading a sampling result

Whenever the ND bit in the interrupt status register is set, new sampling data is available and can be read via SPI. It has to be read before the next sampling data arrives otherwise the old data will be overwritten. Initiate the reading of sampling data by sending the command word:

reserved

15 | 14 | 13 | 12 | 11 | 10 | 9 | 8 | 7 | 6 | 5 | 4 | 3 | 2 | 1 | 0
1 | 1 | 0

Afterwards, read 18 words before setting NSS high. These 18 words will contain the sampling result (see section 5), transmitted with the least significant word first.

### 2.4 Resuming a halted sweep

When the halt bit is set in the SweepConfig, the FPGA will configure the Source and LO as requested but will not start the settling timer (and subsequently the sampling process) until this resume command is issued. The halted sweep is indicated by the sweep halted bit in the status register.

reserved

15 | 14 | 13 | 12 | 11 | 10 | 9 | 8 | 7 | 6 | 5 | 4 | 3 | 2 | 1 | 0
0 | 0 | 1

### 2.5 Reading ADC limits

The FPGA keeps track of the highest and lowest sample of each ADC to detect saturation and verify signal levels.
Initiate the reading of ADC limit data by sending the command word:

reserved

15 | 14 | 13 | 12 | 11 | 10 | 9 | 8 | 7 | 6 | 5 | 4 | 3 | 2 | 1 | 0
1 | 1 | 1

Afterwards, read 6 words before setting NSS high. These 6 words will contain the sampling result:

95 | 94 | 93 | 92 | 91 | 90 | 89 | 88 | 87 | 86 | 85 | 84 | 83 | 82 | 81 | 80

Port 1 minimum

79 | 78 | 77 | 76 | 75 | 74 | 73 | 72 | 71 | 70 | 69 | 68 | 67 | 66 | 65 | 64

Port 1 maximum

63 | 62 | 61 | 60 | 59 | 58 | 57 | 56 | 55 | 54 | 53 | 52 | 51 | 50 | 49 | 48

Port 2 minimum

47 | 46 | 45 | 44 | 43 | 42 | 41 | 40 | 39 | 38 | 37 | 36 | 35 | 34 | 33 | 32

Port 2 maximum

31 | 30 | 29 | 28 | 27 | 26 | 25 | 24 | 23 | 22 | 21 | 20 | 19 | 18 | 17 | 16

Reference minimum

15 | 14 | 13 | 12 | 11 | 10 | 9 | 8 | 7 | 6 | 5 | 4 | 3 | 2 | 1 | 0

Reference maximum

### 2.6 Resetting the ADC limit

Issuing this command result in all minimum values set to 32767 and all maximum values set to -32768.

reserved

15 | 14 | 13 | 12 | 11 | 10 | 9 | 8 | 7 | 6 | 5 | 4 | 3 | 2 | 1 | 0
0 | 1 | 1

## 3 Registers

### 3.1 Interrupt Mask Register: 0x00

reserved

15 | 14 | 13 | 12 | 11 | 10 | 9 | 8 | 7 | 6 | 5 | 4 | 3 | 2 | 1 | 0
| | | | | | | | | | | SHIE | ORIE | NDIE | SUIE | LUIE
- SHIE: Sweep halted interrupt enable
- ORIE: Data overrun interrupt enable
- NDIE: New data interrupt enable
- SUIE: Source unlocked interrupt enable
- LUIE: LO unlocked interrupt enable

### 3.2 Sweep Points Register: 0x01

15 | 14 | 13 | 12 | 11 | 10 | 9 | 8 | 7 | 6 | 5 | 4 | 3 | 2 | 1 | 0

Number of points per sweep - 1

The register contains the number of points per sweep negative one, e.g. set to 11b if the sweep contains four points.

### 3.3 Samples Per Point Register: 0x02

reserved

15 | 14 | 13 | 12 | 11 | 10 | 9 | 8 | 7 | 6 | 5 | 4 | 3 | 2 | 1 | 0

SPP[9:0]

- SPP[9:0]: The register contains the number of samples per point in increments of 128 samples (e.g. SPP=0b0000001000=0x08 uses 1024 samples per point). The value of this register is only used if Sweep-Config[92:90] is set to 000. Otherwise it is overwritten for the sweep point with one of seven preselected values.

### 3.4 System Control Register: 0x03

rsvd

15 | 14 | 13 | 12 | 11 | 10 | 9 | 8 | 7 | 6 | 5 | 4 | 3 | 2 | 1 | 0
P1EN | P2EN | REN | AMEN | SOEN | LOEN | RLED | LED6 | LED7 | Window[1:0] | SCEN | LCEN | EXP2 | EXP1

- P1EN: Port 1 Mixers/Amplifier enable
- P2EN: Port 2 Mixers/Amplifier enable
- REN: Reference Mixers/Amplifier enable
- AMEN: Source amplifier enable
- SOEN: Source enable
- LOEN: LO enable
- RLED: External frequency LED control
- LED6:User LED 6 control
- LED7:User LED 7 control
- Window[1:0]:Type of window to be used in calculation of real/imag of the sampling result
Setting | Window type
00 | Rectangular (no window)
| | | | | | 01 | | | Kaiser
| | | | | | 10 | | | Hann
11 | Flat Top
- EXP1:Excite Port1 during sweep
- EXP2:Excite Port2 during sweep
- SCEN:Source chip enable
- LCEN:LO chip enable

### 3.5 MAX2871 Default Values Registers: 0x08-0x0F

See datasheet of MAX2871 for bit descriptions. Bits for the fields N, FRAC, M, VCO and DIV A are ”don’t care” as they will be overwritten by the SweepConfig setting.

15 | 14 | 13 | 12 | 11 | 10 | 9 | 8 | 7 | 6 | 5 | 4 | 3 | 2 | 1 | 0

MAX2871 Register 0[15:0]

15 | 14 | 13 | 12 | 11 | 10 | 9 | 8 | 7 | 6 | 5 | 4 | 3 | 2 | 1 | 0

MAX2871 Register 0[31:16]

15 | 14 | 13 | 12 | 11 | 10 | 9 | 8 | 7 | 6 | 5 | 4 | 3 | 2 | 1 | 0

MAX2871 Register 1[15:0]

15 | 14 | 13 | 12 | 11 | 10 | 9 | 8 | 7 | 6 | 5 | 4 | 3 | 2 | 1 | 0

MAX2871 Register 1[31:16]

15 | 14 | 13 | 12 | 11 | 10 | 9 | 8 | 7 | 6 | 5 | 4 | 3 | 2 | 1 | 0

MAX2871 Register 3[15:0]

15 | 14 | 13 | 12 | 11 | 10 | 9 | 8 | 7 | 6 | 5 | 4 | 3 | 2 | 1 | 0

MAX2871 Register 3[31:16]

15 | 14 | 13 | 12 | 11 | 10 | 9 | 8 | 7 | 6 | 5 | 4 | 3 | 2 | 1 | 0

MAX2871 Register 4[15:0]

15 | 14 | 13 | 12 | 11 | 10 | 9 | 8 | 7 | 6 | 5 | 4 | 3 | 2 | 1 | 0

MAX2871 Register 4[31:16]

## 4 SweepConfig

The SweepConfig contains data for the source and LO1 PLL as well as the attenuator and source filter. Each point in the sweep, needs a valid SweepConfig before the sweep is started.

95 | 94 | 93 | 92 | 91 | 90 | 89 | 88 | 87 | 86 | 85 | 84 | 83 | 82 | 81 | 80
HS SettlingTime | Samples | SourceFilter | LO M[11:4]
79 | 78 | 77 | 76 | 75 | 74 | 73 | 72 | 71 | 70 | 69 | 68 | 67 | 66 | 65 | 64
LO M[3:0] | LO FRAC[11:0]
63 | 62 | 61 | 60 | 59 | 58 | 57 | 56 | 55 | 54 | 53 | 52 | 51 | 50 | 49 | 48
LO DIV A[2:0] | LO VCO[5:0] | LO N[6:0]
47 | 46 | 45 | 44 | 43 | 42 | 41 | 40 | 39 | 38 | 37 | 36 | 35 | 34 | 33 | 32
BS | Attenuator[6:0] | Source M[11:4]
31 | 30 | 29 | 28 | 27 | 26 | 25 | 24 | 23 | 22 | 21 | 20 | 19 | 18 | 17 | 16
Source M[3:0] | Source FRAC[11:0]
15 | 14 | 13 | 12 | 11 | 10 | 9 | 8 | 7 | 6 | 5 | 4 | 3 | 2 | 1 | 0
Source DIV A[2:0] | Source VCO[5:0] | Source N[6:0]
- HS: Halt sweep. If set, settling and sampling of this sweep point will be postponed until the sweep resume command is issued.
- SettlingTime: Amount of time between locking of PLLs and beginning of ADC sampling
Setting | Time
00 | 20 µs
01 | 60 µs
10 | 180 µs
11 | 540 µs
- Samples: Number of ADC samples to take
Setting | Samples | Equivalent IF bandwidth
000 | Defined by SPP register | 914 kHz/SPP
001 | 128 | 10 kHz
010 | 384 | 3 kHz
011 | 896 | 1 kHz
100 | 3072 | 300 Hz
101 | 9088 | 100 Hz
110 | 30464 | 30 Hz
111 | 91392 | 10 Hz
- SourceFilter: Low pass filter selection for source signal
Setting | Selected Band
00 | 0 MHz to 900 MHz
01 | 900 MHz to 1800 MHz
10 | 1800 MHz to 3500 MHz
11 | 3500 MHz to 6000 MHz
- BS: Band select. Set to 0 for highband, set to 1 for lowband.
- Attenuator: Attenuation of source signal in 0.25 dB.

## 5 Sampling Result

Each point in the sweep generates two sampling results. The first one contains the measurement when the source was routed to Port 1, the second sampling result was taken when the source was routed to Port 2. The sampling result does not indicate which point in the sweep it belongs to, that information is implicitly given by the order of transmitted sampling results.

287 | 286 | 285 | 284 | 283 | 282 | 281 | 280 | 279 | 278 | 277 | 276 | 275 | 274 | 273 | 272

Port 1 I[47:32]

271 | 270 | 269 | 268 | 267 | 266 | 265 | 264 | 263 | 262 | 261 | 260 | 259 | 258 | 257 | 256

Port 1 I[31:16]

255 | 254 | 253 | 252 | 251 | 250 | 249 | 248 | 247 | 246 | 245 | 244 | 243 | 242 | 241 | 240

Port 1 I[15:0]

239 | 238 | 237 | 236 | 235 | 234 | 233 | 232 | 231 | 230 | 229 | 228 | 227 | 226 | 225 | 224

Port 1 Q[47:32]

223 | 222 | 221 | 220 | 219 | 218 | 217 | 216 | 215 | 214 | 213 | 212 | 211 | 210 | 209 | 208

Port 1 Q[31:16]

207 | 206 | 205 | 204 | 203 | 202 | 201 | 200 | 199 | 198 | 197 | 196 | 195 | 194 | 193 | 192

Port 1 Q[15:0]

191 | 190 | 189 | 188 | 187 | 186 | 185 | 184 | 183 | 182 | 181 | 180 | 179 | 178 | 177 | 176

Port 2 I[47:32]

175 | 174 | 173 | 172 | 171 | 170 | 169 | 168 | 167 | 166 | 165 | 164 | 163 | 162 | 161 | 160

Port 2 I[31:16]

159 | 158 | 157 | 156 | 155 | 154 | 153 | 152 | 151 | 150 | 149 | 148 | 147 | 146 | 145 | 144

Port 2 I[15:0]

143 | 142 | 141 | 140 | 139 | 138 | 137 | 136 | 135 | 134 | 133 | 132 | 131 | 130 | 129 | 128

Port 2 Q[47:32]

127 | 126 | 125 | 124 | 123 | 122 | 121 | 120 | 119 | 118 | 117 | 116 | 115 | 114 | 113 | 112

Port 2 Q[31:16]

111 | 110 | 109 | 108 | 107 | 106 | 105 | 104 | 103 | 102 | 101 | 100 | 99 | 98 | 97 | 96

Port 2 Q[15:0]

95 | 94 | 93 | 92 | 91 | 90 | 89 | 88 | 87 | 86 | 85 | 84 | 83 | 82 | 81 | 80

Reference Signal I[47:32]

79 | 78 | 77 | 76 | 75 | 74 | 73 | 72 | 71 | 70 | 69 | 68 | 67 | 66 | 65 | 64

Reference Signal I[31:16]

63 | 62 | 61 | 60 | 59 | 58 | 57 | 56 | 55 | 54 | 53 | 52 | 51 | 50 | 49 | 48

Reference Signal I[15:0]

47 | 46 | 45 | 44 | 43 | 42 | 41 | 40 | 39 | 38 | 37 | 36 | 35 | 34 | 33 | 32

Reference Signal Q[47:32]

31 | 30 | 29 | 28 | 27 | 26 | 25 | 24 | 23 | 22 | 21 | 20 | 19 | 18 | 17 | 16

Reference Signal Q[31:16]

15 | 14 | 13 | 12 | 11 | 10 | 9 | 8 | 7 | 6 | 5 | 4 | 3 | 2 | 1 | 0

Reference Signal Q[15:0]

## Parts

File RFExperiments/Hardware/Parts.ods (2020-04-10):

LT5560-Board
Qty | Value | Device | Package | Parts
1 |  | PINHD-1X10/90 | 1X10/90 | JP1 | 61304011021 (https://www.mouser.de/ProductDetail/Wurth-Elektronik/61304011021)
1 | 0 | R-EU_R0603 | R0603 | R2
6 | 100n | C-EUC0603 | C0603 | C3, C4, C5, C8, C9, C19
2 | 10k | R-EU_R0603 | R0603 | R11, R12
2 | 10u | C-EUC1206 | C1206 | C16, C17 | EMK316BJ106MD-T (https://www.mouser.de/ProductDetail/Taiyo-Yuden/EMK316BJ106MD-T)
2 | 120n | INDUCTOR0603 | R0603 | L1, L3 | LQW18ASR12J00D (https://www.mouser.de/ProductDetail/Murata-Electronics/LQW18ASR12J00D)
3 | 1u | C-EUC0603 | C0603 | C6, C7, C18
4 | 200 | R-EU_R0603 | R0603 | R5, R6, R7, R8
2 | 33 | R-EU_R0603 | R0603 | R9, R10
2 | 470 | R-EU_R0603 | R0603 | R13, R14
3 | 4n7 | C-EUC0603 | C0603 | C13, C14, C15
1 | 650n | INDUCTOR0603 | R0603 | L2 | LQW18CNR65J00D (https://www.mouser.de/ProductDetail/Murata-Electronics/LQW18CNR65J00D)
2 | 82p | C-EUC0603 | C0603 | C1, C2 | C0603C820J5GAC (https://www.mouser.de/ProductDetail/KEMET/C0603C820J5GAC?qs=sGAEpiMZZMs0AnBnWHyRQAOlcDrFW2iEvCjGM3GVib0%3D)
2 | BSS123 | BSS123 | SOT23 | Q1, Q2 | BSS123LT1G (https://www.mouser.de/ProductDetail/ON-Semiconductor/BSS123LT1G)
3 | DNP | C-EUC0603 | C0603 | C10, C11, C12
3 | DNP | R-EU_R0603 | R0603 | R1, R3, R4
1 | Ferrite | INDUCTOR0603 | R0603 | L4
2 | Green | LED_ESML0603 | LED_SML0603 | LED1, LED2
1 | IN | SMA_CONNECTOR | J502-ND-142-0711-821/826 | X1
1 | LO | SMA_CONNECTOR | J502-ND-142-0711-821/826 | X2
1 | LT5560 | LT5560 | SON50P300X300X80-9T165X238 | IC1 | LT5560EDD#PBF (https://www.mouser.de/ProductDetail/Analog-Devices-Linear-Technology/LT5560EDDPBF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)
1 | LTC6362 | LTC6362 | SON50P300X300X80-9T165X238 | IC2 | LTC6362IDD#PBF (https://www.mouser.de/ProductDetail/Analog-Devices-Linear-Technology/LTC6362IDDPBF)
1 | VREG-TS1117CW-5V | VREG-TS1117CW-5V | SOT223 | IC3 | LD1117S50TR (https://www.mouser.de/ProductDetail/STMicroelectronics/LD1117S50TR)
MAX2871-Board
Qty | Value | Device | Package | Parts
1 |  | PINHD-1X10/90 | 1X10/90 | JP1 | 61304011021 (https://www.mouser.de/ProductDetail/Wurth-Elektronik/61304011021)
1 | 100 | R-EU_R0603 | R0603 | R2
5 | 100n | C-EUC0603 | C0603 | C7, C14, C15, C18, C19
1 | 10k | R-EU_R0603 | R0603 | R16
4 | 10n | C-EUC0603 | C0603 | C17, C20, C21, C22
2 | 10u | C-EUC1206 | C1206 | C12, C13 | EMK316BJ106MD-T (https://www.mouser.de/ProductDetail/Taiyo-Yuden/EMK316BJ106MD-T)
1 | 120 | R-EU_R0603 | R0603 | R3
1 | 180p | C-EUC0603 | C0603 | C5
1 | 1k | R-EU_R0603 | R0603 | R1
7 | 1u | C-EUC0603 | C0603 | C1, C2, C3, C8, C9, C10, C11
2 | 220 | R-EU_R0603 | R0603 | R9, R10
1 | 2n | C-EUC0603 | C0603 | C4
1 | 33n | C-EUC0603 | C0603 | C6
1 | 470 | R-EU_R0603 | R0603 | R11
5 | 49R9 | R-EU_R0603 | R0603 | R5, R6, R7, R8, R12
1 | 5k1 | R-EU_R0603 | R0603 | R4
1 | AP2114H | AP2114H | SOT230P700X180-4 | IC1 | AP2114H-3.3TRG1 (https://www.mouser.de/ProductDetail/Diodes-Incorporated/AP2114H-33TRG1)
2 | Ferrite | INDUCTOR0603 | R0603 | L1, L2
2 | Green | LED_ESML0603 | LED_SML0603 | LED1, LED3
1 | MAX2871 | MAX2871 | QFN50P500X500X80-33T310 | IC2 | MAX2871ETJ+ (https://www.mouser.de/ProductDetail/Maxim-Integrated/MAX2871ETJ%2B)
2 | NCP702-3.3 | NCP702 | SOT95P240X110-5 | IC4, IC5 | NCP702SN33T1G (https://www.mouser.de/ProductDetail/ON-Semiconductor/NCP702SN33T1G?qs=sGAEpiMZZMvrYgwxMvI%2FG%2FOkQPXxkto%2F)
1 | Red | LED_ESML0603 | LED_SML0603 | LED2
5 | SMA_CONNECTOR | SMA_CONNECTOR | J502-ND-142-0711-821/826 | X1, X2, X3, X4, X5
LTC5510-Board
Qty | Value | Device | Package | Parts
1 |  | C-EUC0603 | C0603 | C5
1 |  | PINHD-1X6/90 | 1X06/90 | JP1 | 61304011021 (https://www.mouser.de/ProductDetail/Wurth-Elektronik/61304011021)
5 | 100n | C-EUC0603 | C0603 | C6, C7, C12, C13, C14
2 | 10k | R-EU_R0603 | R0603 | R9, R10
1 | 10n | C-EUC0603 | C0603 | C8
2 | 10u | C-EUC1206 | C1206 | C15, C16 | EMK316BJ106MD-T (https://www.mouser.de/ProductDetail/Taiyo-Yuden/EMK316BJ106MD-T)
1 | 18 | R-EU_R0603 | R0603 | R3 | CR0603-FX-18R0ELF (https://www.mouser.de/ProductDetail/Bourns/CR0603-FX-18R0ELF)
6 | 1u | C-EUC0603 | C0603 | C1, C2, C3, C4, C9, C17
3 | 330n | INDUCTOR0603 | R0603 | L1, L2, L3 | LQW18ASR33G00D (https://www.mouser.de/ProductDetail/Murata-Electronics/LQW18ASR33G00D)
2 | 39p | C-EUC0603 | C0603 | C10, C11 | C0603C390J5GAC (https://www.mouser.de/ProductDetail/KEMET/C0603C390J5GAC)
2 | 470 | R-EU_R0603 | R0603 | R12, R13
3 | 49R9 | R-EU_R0603 | R0603 | R6, R7, R8
1 | 51k | R-EU_R0603 | R0603 | R14
4 | 620 | R-EU_R0603 | R0603 | R1, R2, R4, R5 | RC0603FR-07620RL (https://www.mouser.de/ProductDetail/Yageo/RC0603FR-07620RL)
2 | BSS123 | BSS123 | SOT23 | Q1, Q2 | BSS123LT1G (https://www.mouser.de/ProductDetail/ON-Semiconductor/BSS123LT1G)
1 | DNP | R-EU_R0603 | R0603 | R11
1 | Ferrite | INDUCTOR0603 | R0603 | L4
2 | Green | LED_ESML0603 | LED_SML0603 | LED1, LED2
1 | IF OUT | SMA_CONNECTOR | J502-ND-142-0711-821/826 | X4
1 | LO | SMA_CONNECTOR | J502-ND-142-0711-821/826 | X3
1 | LTC5510 | LTC5510 | QFN65P400X400X75-17T215N | IC1 | LTC5510IUF#PBF (https://www.mouser.de/ProductDetail/Analog-Devices-Linear-Technology/LTC5510IUFPBF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)
1 | MABA011082 | MABA011082 | MACOM_BALUN | T1 | MABA-011082 (https://www.mouser.de/ProductDetail/MACOM/MABA-011082)
1 | RLB DUT/RF IN | SMA_CONNECTOR | J502-ND-142-0711-821/826 | X2
1 | RLB Feed | SMA_CONNECTOR | J502-ND-142-0711-821/826 | X1
1 | VREG-TS1117CW-5V | VREG-TS1117CW-5V | SOT223 | IC2 | LD1117S50TR (https://www.mouser.de/ProductDetail/STMicroelectronics/LD1117S50TR)
Si5351-Board
Qty | Value | Device | Package | Parts
9 |  | C-EUC0603 | C0603 | C1, C2, C3, C4, C5, C6, C7, C8, C13
1 |  | PINHD-1X6/90 | 1X06/90 | JP1 | 61304011021 (https://www.mouser.de/ProductDetail/Wurth-Elektronik/61304011021)
4 | 100n | C-EUC0603 | C0603 | C9, C10, C11, C12
4 | 10k | R-EU_R0603 | R0603 | R1, R2, R3, R4
3 | 1u | C-EUC0603 | C0603 | C16, C17, C18
2 | 4p | C-EUC0603 | C0603 | C14, C15
1 | CLK0 | SMA_CONNECTOR | J502-ND-142-0711-821/826 | X1
1 | CLK1 | SMA_CONNECTOR | J502-ND-142-0711-821/826 | X2
1 | CLK2 | SMA_CONNECTOR | J502-ND-142-0711-821/826 | X3
1 | CLK3 | SMA_CONNECTOR | J502-ND-142-0711-821/826 | X4
1 | CLK4 | SMA_CONNECTOR | J502-ND-142-0711-821/826 | X5
1 | CLK5 | SMA_CONNECTOR | J502-ND-142-0711-821/826 | X6
1 | CLK6 | SMA_CONNECTOR | J502-ND-142-0711-821/826 | X7
1 | CLK7 | SMA_CONNECTOR | J502-ND-142-0711-821/826 | X8
1 | FA-128 26MHz | FA-128 | FA-128 | Q1 | FA-128 26.0000MF10Z-W5 (https://www.mouser.de/ProductDetail/Epson-Timing/FA-128-260000MF10Z-W5)
1 | Ferrite | INDUCTOR0603 | R0603 | L1
1 | NCP702-3.3 | NCP702 | SOT95P240X110-5 | IC4 | NCP702SN33T1G (https://www.mouser.de/ProductDetail/ON-Semiconductor/NCP702SN33T1G?qs=sGAEpiMZZMvrYgwxMvI%2FG%2FOkQPXxkto%2F)
1 | REF IN | SMA_CONNECTOR | J502-ND-142-0711-821/826 | X9
1 | SI5351C | SI5351C | QFN50P400X400X90-21T270N | IC1 | SI5351C-B-GM (https://www.mouser.de/ProductDetail/Silicon-Labs/SI5351C-B-GM)

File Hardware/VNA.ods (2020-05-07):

Qty | Value | Device | Package | Parts | Description | Mouser Link | Comment
9 |  | LEDCHIPLED_0603 | CHIPLED_0603 | LED1, LED2, LED3, LED4, LED5, LED6, LED7, LED8, LED9 | LED | 150060VS75000 (https://www.mouser.de/ProductDetail/Wurth-Elektronik/150060VS75000)
1 |  | ML10 | ML10 | JTAG | HARTING
1 |  | PINHD-1X6 | 1X06 | JP1 | PIN HEADER
1 | 0 | R-EU_R0603 | R0603 | R68 | RESISTOR, European symbol
76 | 100n | C-EUC0603 | C0603 | C1, C2, C3, C4, C6, C7, C12, C13, C15, C18, C22, C23, C26, C29, C30, C33, C34, C35, C36, C38, C39, C43, C44, C45, C48, C49, C52, C54, C59, C64, C66, C67, C68, C70, C71, C75, C76, C77, C80, C81, C84, C86, C91, C96, C104, C105, C110, C120, C127, C128, C129, C138, C143, C144, C145, C148, C149, C150, C151, C152, C153, C154, C155, C156, C157, C191, C192, C203, C204, C205, C206, C207, C208, C209, C210, C211 | CAPACITOR, European symbol |  | Broadband: | 530L104KT16T (https://www.mouser.de/ProductDetail/American-Technical-Ceramics-ATC/530L104KT16T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)
22 | 10k | R-EU_R0603 | R0603 | R49, R56, R64, R80, R83, R86, R90, R92, R93, R94, R95, R97, R98, R99, R100, R101, R102, R103, R104, R111, R112, R113 | RESISTOR, European symbol | CR0603-FX-1002ELF (https://www.mouser.de/ProductDetail/Bourns/CR0603-FX-1002ELF)
17 | 10n | C-EUC0603 | C0603 | C8, C10, C11, C40, C42, C55, C65, C72, C74, C87, C107, C121, C130, C131, C132, C146, C147 | CAPACITOR, European symbol
4 | 10u | C-EUC1206 | C1206 | C125, C126, C141, C142 | CAPACITOR, European symbol
2 | 10u | SRN5040 | SRN5040 | L51, L55 |  | SRN5040TA-100M (https://www.mouser.de/ProductDetail/Bourns/SRN5040TA-100M)
3 | 10u/25V | C-EUC1206 | C1206 | C173, C177, C185 | CAPACITOR, European symbol | C1206C106M3PAC (https://www.mouser.de/ProductDetail/KEMET/C1206C106M3PAC)
6 | 120n | INDUCTOR0603 | R0603 | L32, L33, L34, L35, L36, L37 |  | LQW18ASR12G00D (https://www.mouser.de/ProductDetail/Murata-Electronics/LQW18ASR12G00D) | 4 vorhanden
4 | 120p | C-EUC0603 | C0603 | C14, C56, C88, C182 | CAPACITOR, European symbol | C0603C121J5GAC (https://www.mouser.de/ProductDetail/KEMET/C0603C121J5GAC?qs=sGAEpiMZZMs0AnBnWHyRQFqPnX0Olvco907YLWID1oI%3D)
3 | 150p | C-EUC0603 | C0603 | C31, C57, C89 | CAPACITOR, European symbol | CC0603KRX7R8BB151 (https://www.mouser.de/ProductDetail/Yageo/CC0603KRX7R8BB151)
1 | 16k | R-EU_R0603 | R0603 | R85 | RESISTOR, European symbol | RC0603FR-1016KL (https://www.mouser.de/ProductDetail/Yageo/RC0603FR-1016KL)
2 | 18 | R-EU_R0603 | R0603 | R3, R12 | RESISTOR, European symbol
2 | 180p | C-EUC0603 | C0603 | C117, C135 | CAPACITOR, European symbol
8 | 18p | C-EUC0603 | C0603 | C97, C99, C100, C102, C103, C112, C118, C136 | CAPACITOR, European symbol
1 | 1k5 | R-EU_R0603 | R0603 | R89 | RESISTOR, European symbol
2 | 1k8 | R-EU_R0603 | R0603 | R50, R58 | RESISTOR, European symbol | RC0603FR-101K8L (https://www.mouser.de/ProductDetail/Yageo/RC0603FR-101K8L)
1 | 1n | C-EUC0603 | C0603 | C187 | CAPACITOR, European symbol
34 | 1u | C-EUC0603 | C0603 | C9, C20, C21, C28, C41, C46, C47, C63, C73, C78, C79, C95, C106, C114, C115, C116, C122, C123, C124, C133, C134, C139, C140, C158, C160, C162, C164, C165, C166, C167, C168, C193, C194, C195 | CAPACITOR, European symbol
4 | 20 | R-EU_R0603 | R0603 | R34, R35, R38, R39 | RESISTOR, European symbol | RC0603FR-1020RL (https://www.mouser.de/ProductDetail/Yageo/RC0603FR-1020RL)
8 | 200 | R-EU_R0603 | R0603 | R15, R16, R27, R28, R43, R44, R45, R46 | RESISTOR, European symbol
1 | 20k | R-EU_R0603 | R0603 | R87 | RESISTOR, European symbol | RC0603FR-1020KL (https://www.mouser.de/ProductDetail/Yageo/RC0603FR-1020KL)
4 | 22 | R-EU_R0603 | R0603 | R76, R88, R91, R96 | RESISTOR, European symbol
9 | 22n | C-EUC0603 | C0603 | C16, C17, C19, C60, C61, C62, C92, C93, C94 | CAPACITOR, European symbol
10 | 22u | C-EUC1206 | C1206 | C169, C170, C171, C172, C174, C180, C181, C184, C189, C190 | CAPACITOR, European symbol | C1206C226M9PACTU (https://www.mouser.de/ProductDetail/KEMET/C1206C226M9PACTU?qs=sGAEpiMZZMs0AnBnWHyRQI9zuYIiQALCndQHkMf8vck%3D)
2 | 2R7 | R-EU_R0603 | R0603 | R69, R70 | RESISTOR, European symbol | RK73H1JTTD2R70F (https://www.mouser.de/ProductDetail/KOA-Speer/RK73H1JTTD2R70F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)
1 | 30k | R-EU_R0603 | R0603 | R82 | RESISTOR, European symbol | RC0603FR-0730KL (https://www.mouser.de/ProductDetail/Yageo/RC0603FR-0730KL)
6 | 33 | R-EU_R0603 | R0603 | R19, R20, R31, R32, R47, R48 | RESISTOR, European symbol
11 | 330 | R-EU_R0603 | R0603 | R14, R26, R42, R52, R60, R105, R106, R107, R108, R109, R110 | RESISTOR, European symbol
13 | 330n | INDUCTOR0603 | R0603 | L1, L2, L3, L6, L11, L12, L17, L18, L21, L22, L27, L28, L44 |  | LQW18ASR33G00D (https://www.mouser.de/ProductDetail/Murata-Electronics/LQW18ASR33G00D)
6 | 33n | INDUCTOR0603 | R0603 | L9, L10, L15, L16, L25, L26
3 | 33p | C-EUC0603 | C0603 | C32, C58, C90 | CAPACITOR, European symbol
2 | 3n3 | C-EUC0603 | C0603 | C119, C137 | CAPACITOR, European symbol | CC0603KRX7R8BB332 (https://www.mouser.de/ProductDetail/Yageo/CC0603KRX7R8BB332)
1 | 406 | R-EU_R0603 | R0603 | R71 | RESISTOR, European symbol | RC0603FR-07402RL (https://www.mouser.de/ProductDetail/Yageo/RC0603FR-07402RL) | 402 Ohm
1 | 45k3 | R-EU_R0603 | R0603 | R84 | RESISTOR, European symbol | CR0603-FX-4532ELF (https://www.mouser.de/ProductDetail/Bourns/CR0603-FX-4532ELF)
3 | 47n | C-EUC0603 | C0603 | C175, C178, C186 | CAPACITOR, European symbol | CC0603KRX7R8BB473 (https://www.mouser.de/ProductDetail/Yageo/CC0603KRX7R8BB473?qs=sGAEpiMZZMs0AnBnWHyRQMMzfhmH8IQXruTxom8pgKg%3D)
14 | 49R9 | R-EU_R0603 | R0603 | R6, R7, R8, R22, R23, R24, R54, R55, R57, R62, R63, R65, R66, R67 | RESISTOR, European symbol
3 | 4n7 | C-EUC0603 | C0603 | C27, C53, C85 | CAPACITOR, European symbol
2 | 4p | C-EUC0603 | C0603 | C108, C109 | CAPACITOR, European symbol
4 | 4u7 | C-EUC0603 | C0603 | C113, C159, C161, C163 | CAPACITOR, European symbol | JMK107C6475KA-T (https://www.mouser.de/ProductDetail/Taiyo-Yuden/JMK107C6475KA-T)
6 | 4u7 | INDUCTOR0603 | R0603 | L4, L5, L19, L20, L29, L30 |  | AIML-0603-4R7K-T (https://www.mouser.de/ProductDetail/ABRACON/AIML-0603-4R7K-T)
1 | 510p | C-EUC0603 | C0603 | C176 | CAPACITOR, European symbol |  | replace by similar value (330pF?)
1 | 51k | R-EU_R0603 | R0603 | R78 | RESISTOR, European symbol
5 | 56 | R-EU_R0603 | R0603 | R33, R36, R37, R40, R72 | RESISTOR, European symbol | RC0603FR-1356RL (https://www.mouser.de/ProductDetail/Yageo/RC0603FR-1356RL?qs=sGAEpiMZZMvdGkrng054t8AJgcdMkx7xh8NAcCicktw%3D)
3 | 56p | C-EUC0603 | C0603 | C98, C101, C111 | CAPACITOR, European symbol | C0603C560J5GAC (https://www.mouser.de/ProductDetail/KEMET/C0603C560J5GAC)
2 | 5k1 | R-EU_R0603 | R0603 | R53, R61 | RESISTOR, European symbol
12 | 620 | R-EU_R0603 | R0603 | R1, R2, R4, R5, R9, R10, R13, R17, R18, R21, R29, R30 | RESISTOR, European symbol
6 | 68n | INDUCTOR0603 | R0603 | L7, L8, L13, L14, L23, L24
1 | 6SLX9TQG144 | 6SLX9TQG144 | TQ144 | U2 | Xilinx FPGA: 6SLX9TQG144
3 | 6u8 | SRN5040 | SRN5040 | L52, L53, L54 |  | SRN5040-6R8M (https://www.mouser.de/ProductDetail/Bourns/SRN5040-6R8M)
2 | 82 | R-EU_R0603 | R0603 | R51, R59 | RESISTOR, European symbol
1 | 82k | R-EU_R0603 | R0603 | R79 | RESISTOR, European symbol | RC0603FR-1382KL (https://www.mouser.de/ProductDetail/Yageo/RC0603FR-1382KL)
1 | 8p2 | C-EUC0603 | C0603 | C188 | CAPACITOR, European symbol
1 | 91k | R-EU_R0603 | R0603 | R81 | RESISTOR, European symbol | AC0603FR-1091KL (https://www.mouser.de/ProductDetail/Yageo/AC0603FR-1091KL)
2 | AP2114H | AP2114H | SOT230P700X180-4 | IC17, IC21 |  | AP2114H-3.3TRG1 (https://www.mouser.de/ProductDetail/Diodes-Incorporated/AP2114H-33TRG1)
1 | DCJ0202 | DCJ0202 | DCJ0202 | J3 | DC POWER JACK
11 | DNP | C-EUC0603 | C0603 | C5, C24, C25, C37, C50, C51, C69, C82, C83, C179, C183 | CAPACITOR, European symbol
4 | DNP | R-EU_R0603 | R0603 | R11, R25, R41, R77 | RESISTOR, European symbol
1 | F1958 | F1958 | QFN50P400X400X75-25T270 | IC23 |  | F1958NBGK (https://www.mouser.de/ProductDetail/Renesas-IDT/F1958NBGK)
4 | F2912 | F2912 | QFN50P400X400X75-21T206 | IC22, IC25, IC26, IC27 |  | F2912NCGI8 (https://www.mouser.de/ProductDetail/Renesas-IDT/F2912NCGI8?qs=sGAEpiMZZMvfFCidbTccA4a6tdrxnMZCV3OYjVyfpkA%3D)
1 | FA-128 26MHz | FA-128 | FA-128 | Q1 | MHz RANGE CRYSTAL UNIT | FA-128 26.0000MF10Z-W5 (https://www.mouser.de/ProductDetail/Epson-Timing/FA-128-260000MF10Z-W5)
13 | Ferrite | INDUCTOR0603 | R0603 | L31, L38, L39, L40, L41, L42, L43, L45, L46, L47, L48, L49, L50
4 | LDL212PU50R | LDL212PU50R | SON95P300X300X100-7T170X240N | IC28, IC29, IC30, IC31 |  | LDL212PU50R (https://www.mouser.de/ProductDetail/STMicroelectronics/LDL212PU50R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)
1 | LP0603A0947ANTR | LP0603A | FILTRDFN160X84X70-4N | LP1 |  | LP0603A0947ANTR (https://www.mouser.de/ProductDetail/AVX/LP0603A0947ANTR)
1 | LP0603A1880ANTR | LP0603A | FILTRDFN160X84X70-4N | LP2 |  | LP0603A1880ANTR (https://www.mouser.de/ProductDetail/AVX/LP0603A1880ANTR)
1 | LP0603N3500ANTR | LP0603A | FILTRDFN160X84X70-4N | LP3 |  | 581-LP0603N3500ANTR (https://www.mouser.de/ProductDetail/581-LP0603N3500ANTR)
3 | LT5560 | LT5560 | SON50P300X300X80-9T165X238 | IC2, IC6, IC10 |  | LT5560EDD#PBF (https://www.mouser.de/ProductDetail/Analog-Devices-Linear-Technology/LT5560EDDPBF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)
3 | LTC5510 | LTC5510 | QFN65P400X400X75-17T215N | IC1, IC5, IC9 |  | LTC5510IUF#PBF (https://www.mouser.de/ProductDetail/Analog-Devices-Linear-Technology/LTC5510IUFPBF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)
3 | LTC6362 | LTC6362 | SON50P300X300X80-9T165X238 | IC3, IC7, IC11 |  | LTC6362IDD#PBF (https://www.mouser.de/ProductDetail/Analog-Devices-Linear-Technology/LTC6362IDDPBF)
3 | MABA011082 | MABA011082 | MACOM_BALUN | T1, T2, T3 |  | 937-MABA-011082 (https://www.mouser.de/ProductDetail/937-MABA-011082)
2 | MAX2871 | MAX2871 | QFN50P500X500X80-33T310 | IC14, IC19 |  | MAX2871ETJ+ (https://www.mouser.de/ProductDetail/Maxim-Integrated/MAX2871ETJ%2B)
3 | MCP33131D-10-E/MS | MCP33131D-10-E/MS | SOP50P490X110-10N | IC4, IC8, IC12 |  | MCP33131D-10-E/MS (https://www.mouser.de/ProductDetail/Microchip-Technology/MCP33131D-10-E-MS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)
1 | MINI-USB-SCHIELD-32005-301 | MINI-USB-SCHIELD-32005-301 | 32005-301 | X4 | MINI USB-B Conector | UX60-MB-5ST (https://www.mouser.de/ProductDetail/Hirose-Connector/UX60-MB-5ST)
3 | NCP702-1.8 | NCP702 | SOT95P240X110-5 | IC34, IC35, IC36 |  | NCP702SN18T1G (https://www.mouser.de/ProductDetail/ON-Semiconductor/NCP702SN18T1G?qs=sGAEpiMZZMvrYgwxMvI%2FG8elVbATwr5l) | 1 vorhanden
2 | NCP702-3.3 | NCP702 | SOT95P240X110-5 | IC15, IC20
2 | RFSW6042 | RFSW6042 | QFN40P180X180X55-13T76N | IC16, IC18 |  | RFSW6042TR7 (https://www.mouser.de/ProductDetail/Qorvo/RFSW6042TR7)
2 | RLB DUT/RF IN | SMA_CONNECTOR | J502-ND-142-0711-821/826 | X1, X2
1 | SI5351C | SI5351C | QFN50P400X400X90-21T270N | IC13 |  | SI5351C-B-GM (https://www.mouser.de/ProductDetail/Silicon-Labs/SI5351C-B-GM)
1 | STM32L432KC | STM32L432KC | QFN50P500X500X100-33T345N | IC33 |  | STM32L432KCU6 (https://www.mouser.de/ProductDetail/STMicroelectronics/STM32L432KCU6)
3 | TBD | R-EU_R0603 | R0603 | R73, R74, R75 | RESISTOR, European symbol
19 | TPB1,27 | TPB1,27 | B1,27 | TP1, TP2, TP3, TP4, TP5, TP6, TP7, TP8, TP9, TP10, TP11, TP12, TP13, TP14, TP15, TP16, TP17, TP18, TP19 | Test pad
1 | TPS65265 | TPS65265 | QFN50P500X500X100-33T345N | IC32 |  | TPS65265RHBR (https://www.mouser.de/ProductDetail/Texas-Instruments/TPS65265RHBR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)
1 | TRF37A73 | TRF37A73 | SON50P200X200X80-9T90X160N | IC24 |  | TRF37A73IDSGR (https://www.mouser.de/ProductDetail/Texas-Instruments/TRF37A73IDSGR)
2 | U.FL-R-SMT | U.FL-R-SMT | U.FL_SMT | J1, J2 | U.FL-R-SMT Antenna Connector
1 | W25Q16BVSN | W25Q16BVSN | SO08 | U4 | EEPROM | W25Q16JVSNIQ (https://www.mouser.de/ProductDetail/Winbond/W25Q16JVSNIQ)

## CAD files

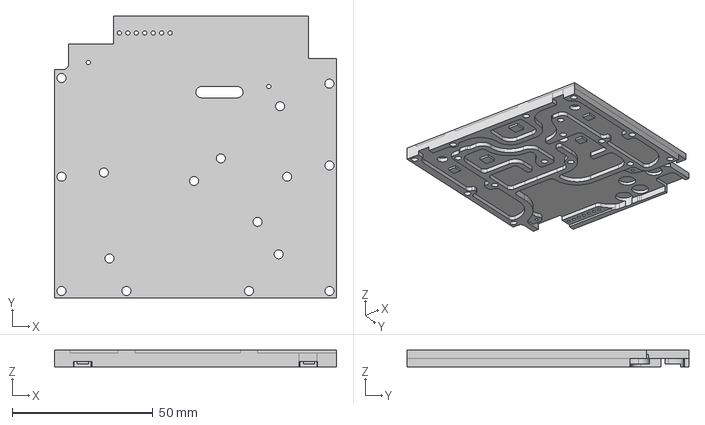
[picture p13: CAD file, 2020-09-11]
Hardware/TopCover.step
100.0 x 100.0 x 6.00 mm

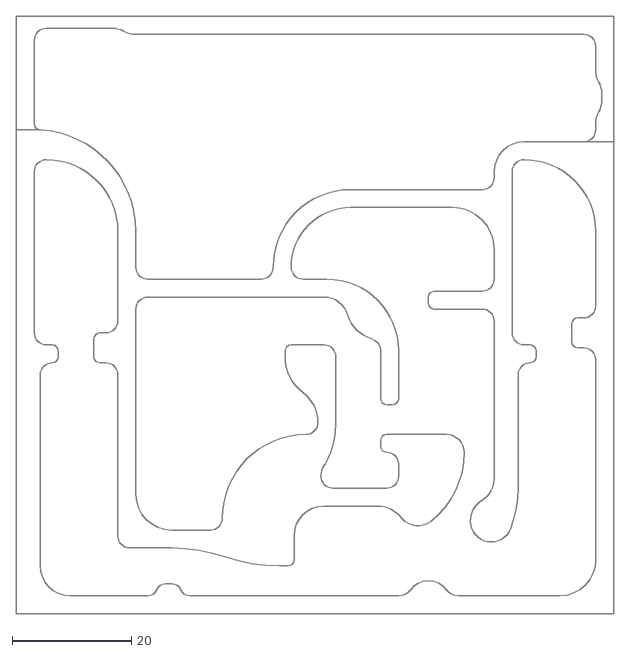
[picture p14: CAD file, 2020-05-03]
Hardware/VNA_bottom.dxf
100.0 x 100.0

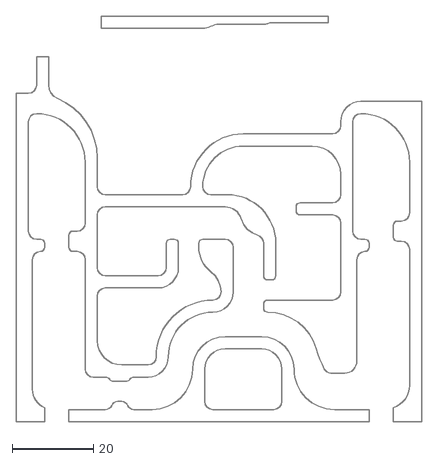
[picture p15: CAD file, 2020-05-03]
Hardware/VNA_top.dxf
100.0 x 100.0

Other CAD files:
Hardware/BottomCover.step

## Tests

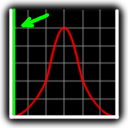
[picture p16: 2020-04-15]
RFExperiments/Software/Application/.png

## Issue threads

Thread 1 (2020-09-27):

VNA build

nbgsmk, 2020-09-27:
Hello my friend!
I just stumbled onto your VNA project. It is great!
After investigating various cheap VNAs on aliexpress and sucn places, I am thinking of building a VNA for myself, from your repository. I hope that would be ok for you? :-)

Among many designs I found online, this is the one I believe to deliver the most. It exceeds anything I may need, by a great degree. And I see from the documents that you really know what you are speaking about. Great work!
So, if you have the time, I would like to ask for some details:
- Somehow I missed the exact Spartan fpga used. Which is it?
- How much did the final build cost you, approximately, without the shielding and milling?
- Because of high frequencies, are there special requests for the pcb material?
- The STM32 part is developed in StmCubeIDE?

Finally, do you have any suggestions or improvements in mind?

PS. I may get access to some RF measurement equipment so, if I am able to finish the build, I would be glad to try and do some tests or comparisons, and share my findings.

Thanks!
Zoran Kostic

jankae, 2020-09-27:
Thanks for taking an interest in the project. First of all: I am working on a new version which you can find [here](https://github.com/jankae/VNA2)
* The FPGA is a Spartan6 (6SLX9TQG144)
* Total BOM cost was about 250€ (new version is slightly cheaper)
* Special pcb material would be better but I couldn't find an affordable manufacturer. The prototype PCB is normal FR4 (JLC7628 stackup)
* I used CubeMX + SW4STM32 for development but I believe the StmCubeIDE is essentially these two tools bundled in one IDE

nbgsmk, 2020-09-28:
Great, let's close this question and continue in the other project.

Closed 2020-09-28.

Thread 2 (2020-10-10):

KiCad

Franck78, 2020-10-10:
Hello,

not an issue.

I just wanted to let you know that I use your Eagle design to test some of KiCad function (someday you will probably find links).

It is 'github' that suggested me your project. Clicked on it, red it, remembered a little vhdl, notted Eagle

If you are a dev (of course you are) with RF skills, I think KiCad can use some gears from you ;)

Franck

jankae, 2020-10-19:
Hi, sorry for the late reply, somehow I missed the notification. There is actually a second [improved version](https://github.com/jankae/VNA2) of this project and someone is already attempting to [migrate it to KiCad](https://github.com/jankae/VNA2/issues/1).
Personally, I have never given KiCad a serious try, maybe it is time for that now :)

Franck78, 2020-10-19:
This version is complicated enough to test the Eagle->Kicad converter.
It does a decent job
* schematics ok
* pcb looks ok but some work  to do I think

I you try KiCad v5, it has the eagle converter. But now they are full on debugging v6, so no backports fix. As I said, they probably better appreciate a RF developer able to add some functionality ;)

v5.1.7 is stable and OK for prod. You must accept that when you put a resistor on the schematic, you will choose latter the footprint for it ( eg smd, tht, big 15 watts etc etc. Same for all components. It's the "footprint association" step.

you already got some image of converted board/schematic. Here VNA-1
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

bvernoux, 2020-10-21:
If you are interested I'm not far to release the schematic/board files for KiCad 5.1.7-1 especially with hint how to extract the KiCad Mask from STEP file for the shielding

Franck78, 2020-10-21:
Just FYI

VNA-1 have some graphics lines that are stacked 3 times. An example is R94, with the courtyard defined thee times. Perhaps all this is corrected in v2. I thought it was a bug in the KiCad converter ;)

If interested
https://gitlab.com/kicad/code/kicad/-/issues/6094

jankae, 2020-10-22:
Hm, Eagle seems to behave weird with the stacked courtyard. When I open the footprint I can only see one. As mentioned on the KiCad issue this could actually be a bug/workaround in Eagle. I didn't create the resistor footprints myself, I believe they are from a default Eagle library, so this problem is most likely also present in v2

Closed 2020-10-19.

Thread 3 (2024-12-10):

Noise reduction in the VNA output signal

amosepehr, 2024-12-10:
Hello
Thanks for your design, I wanted a guide. I would appreciate it if you could help me.
I need a VNA that has minimal noise effects on the output signal. Is it possible to increase the input signal amplitude to +10 dBm in your design instead of -25 dBm? And measure this +25 dBm at the output? If you have a solution to this challenge, please help me.
With best regards.

jankae, 2024-12-10:
Hi, I am a bit lost here. When you say output, do you mean the output of the VNA or the output of the DUT (which would be the input of the VNA)?
I also can not follow your dBm numbers:

>  increase the input signal amplitude to +10 dBm

Do you mean the signal level as generated by the VNA? No, you can not go as high as +10 dBm.

>  instead of -25 dBm?

No clue what you mean. My design has no power level which is limited to -25 dBm.

> And measure this +25 dBm at the output?

And now it is +25 dBm instead of -25 dBm? Where is that coming from? And no, you can not measure +25 dBm with the LibreVNA. Linear measurements are possible up to about 0 dBm, if you go above that, you will no longer be able to make accurate measurements. And if you go way above that, you will damage the input stage of the LibreVNA. Do not apply +25 dBm directly to either port!

I think you will need to explain a bit more about your measurement setup here, otherwise I can not help you. Unless you are talking about an actual redesign of the VNA, the answer will be most likely "use an external amplifier and de-embed it".

jankae, 2024-12-10:
Also: I just noticed that this is not the repository of the LibreVNA. This repository contains an old prototype of which only a single unit was ever assembled. See [here ](https://github.com/jankae/LibreVNA)for the LibreVNA repository.
I'll go ahead and close this because there will be no further development here. Feel free to open a new issue in the LibreVNA repository.

Closed 2024-12-10.

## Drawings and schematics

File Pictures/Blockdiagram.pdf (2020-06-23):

### Port 1

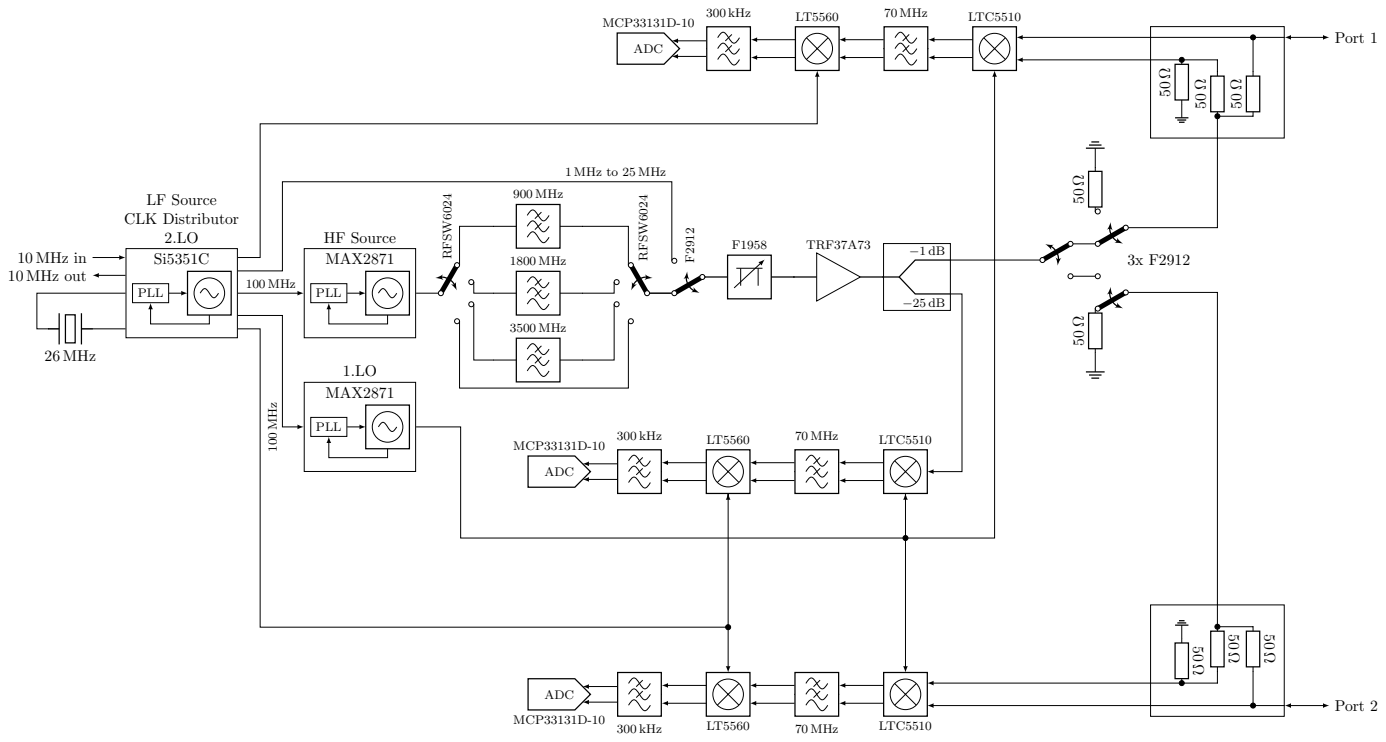
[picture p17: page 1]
PLL; LF Source CLK Distributor 2.LO; 10 MHz in 10 MHz out; 26 MHz; MAX2871; HF Source; 100 MHz; RFSW6024; 900 MHz; 1800 MHz; 3500 MHz; TRF37A73; LTC5510 70 MHz LT5560 300 kHz; ADC; MCP33131D-10; Port 2; 300 kHz; 70 MHz; LTC5510

1 MHz to 25 MHz

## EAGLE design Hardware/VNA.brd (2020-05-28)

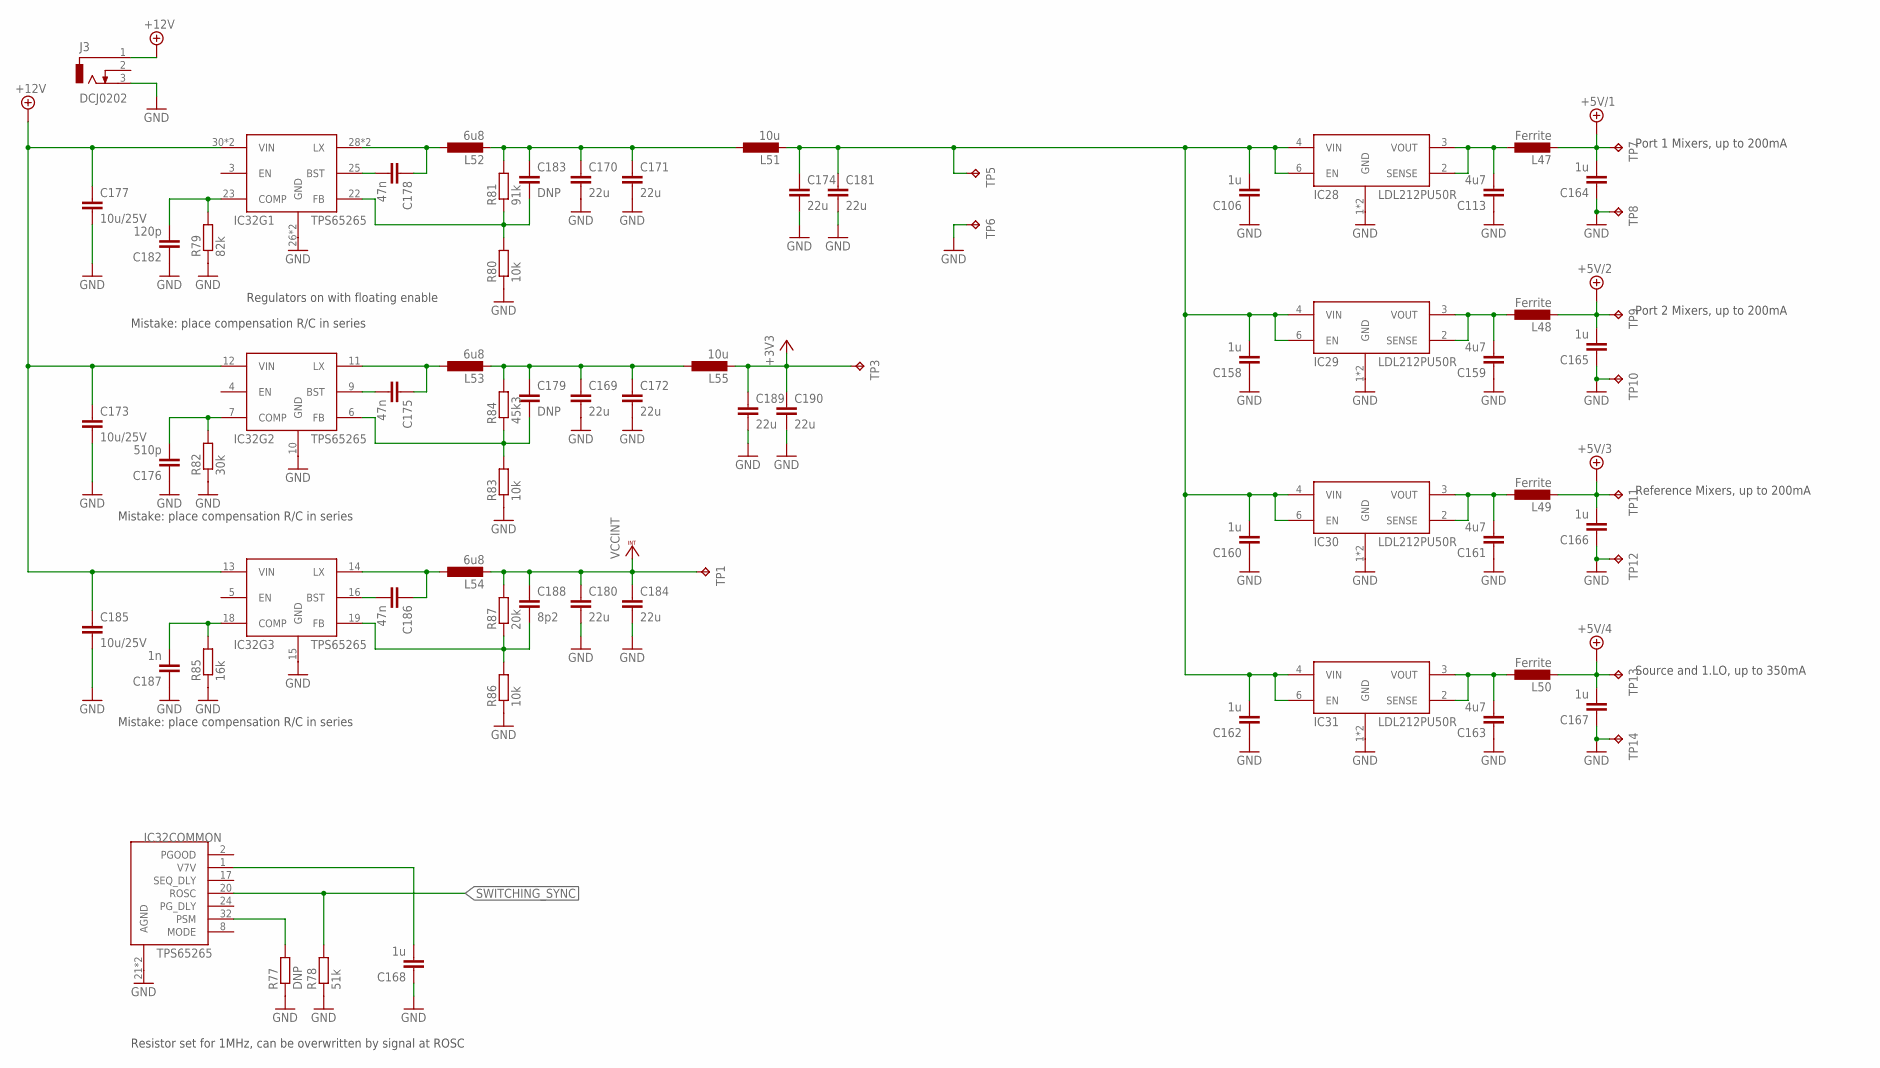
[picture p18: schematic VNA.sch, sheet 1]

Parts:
C106, C158, C160, C162, C164, C165, C166, C167, C168: 1u; C0603
C113, C159, C161, C163: 4u7; C0603
C169, C170, C171, C172, C174, C180, C181, C184, C189, C190: 22u; C1206
C173, C177, C185: 10u/25V; C1206
C175, C178, C186: 47n; C0603
C176: 510p; C0603
C179, C183: DNP; C0603
C182: 120p; C0603
C187: 1n; C0603
C188: 8p2; C0603
IC28, IC29, IC30, IC31: LDL212PU50R; SON95P300X300X100-7T170X240N
IC32: TPS65265; QFN50P500X500X100-33T345N
J3: DCJ0202
L47, L48, L49, L50: Ferrite; R0603
L51, L55: 10u; SRN5040
L52, L53, L54: 6u8; SRN5040
R77: DNP; R0603
R78: 51k; R0603
R79: 82k; R0603
R80, R83, R86: 10k; R0603
R81: 91k; R0603
R82: 30k; R0603
R84: 45k3; R0603
R85: 16k; R0603
R87: 20k; R0603
TP1, TP3, TP5, TP6, TP7, TP8, TP9, TP10, TP11, TP12, TP13, TP14: TPB1,27; B1,27

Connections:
+3V3: C189.1, C190.1, L55.P$2 (2), TP3.TP; also elsewhere on the board
+5V/1: C164.2, L47.2, TP7.TP; also elsewhere on the board
+5V/2: C165.2, L48.2, TP9.TP; also elsewhere on the board
+5V/3: C166.2, L49.2, TP11.TP; also elsewhere on the board
+5V/4: C167.2, L50.2, TP13.TP; also elsewhere on the board
+12V: C173.1, C177.1, C185.1, IC32.12 (VIN), IC32.13 (VIN), IC32.30 (VIN), IC32.31 (VIN), J3.1
GND: C106.1, C113.1, C158.1, C159.1, C160.1, C161.1, C162.1, C163.1, C164.1, C165.1, C166.1, C167.1, C168.1, C169.2, C170.2, C171.2, C172.2, C173.2, C174.2, C176.1, C177.2, C180.2, C181.2, C182.1, C184.2, C185.2, C187.1, C189.2, C190.2, IC28.1 (GND), IC28.7 (GND), IC29.1 (GND), IC29.7 (GND), IC30.1 (GND), IC30.7 (GND), IC31.1 (GND), IC31.7 (GND), IC32.10 (GND), IC32.15 (GND), IC32.21 (AGND), IC32.26 (GND), IC32.27 (GND), IC32.33 (AGND), J3.3, R77.1, R78.1, R79.1, R80.1, R82.1, R83.1, R85.1, R86.1, TP6.TP, TP8.TP, TP10.TP, TP12.TP, TP14.TP; also elsewhere on the board
unnamed: C113.2, IC28.2 (SENSE), IC28.3 (VOUT), L47.1
unnamed: C159.2, IC29.2 (SENSE), IC29.3 (VOUT), L48.1
unnamed: C168.2, IC32.1 (V7V)
unnamed: C106.2, C158.2, C160.2, C162.2, C174.1, C181.1, IC28.4 (VIN), IC28.6 (EN), IC29.4 (VIN), IC29.6 (EN), IC30.4 (VIN), IC30.6 (EN), IC31.4 (VIN), IC31.6 (EN), L51.P$2 (2), TP5.TP
unnamed: C161.2, IC30.2 (SENSE), IC30.3 (VOUT), L49.1
unnamed: C163.2, IC31.2 (SENSE), IC31.3 (VOUT), L50.1
unnamed: IC32.32 (PSM), R77.2
unnamed: C178.2, IC32.25 (BST)
unnamed: C178.1, IC32.28 (LX), IC32.29 (LX), L52.P$1 (1)
unnamed: C175.2, IC32.9 (BST)
unnamed: C175.1, IC32.11 (LX), L53.P$1 (1)
unnamed: C176.2, IC32.7 (COMP), R82.2
unnamed: C182.2, IC32.23 (COMP), R79.2
unnamed: C183.2, IC32.22 (FB), R80.2, R81.1
unnamed: C170.1, C171.1, C183.1, L51.P$1 (1), L52.P$2 (2), R81.2
unnamed: C179.2, IC32.6 (FB), R83.2, R84.1
unnamed: C169.1, C172.1, C179.1, L53.P$2 (2), L55.P$1 (1), R84.2
unnamed: C186.2, IC32.16 (BST)
unnamed: C186.1, IC32.14 (LX), L54.P$1 (1)
unnamed: C187.2, IC32.18 (COMP), R85.2
unnamed: C188.2, IC32.19 (FB), R86.2, R87.1
SWITCHING_SYNC: IC32.20 (ROSC), R78.2; also elsewhere on the board
VCCINT: C180.1, C184.1, C188.1, L54.P$2 (2), R87.2, TP1.TP; also elsewhere on the board

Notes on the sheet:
Port 1 Mixers, up to 200mA
Port 2 Mixers, up to 200mA
Reference Mixers, up to 200mA
Source and 1.LO, up to 350mA
Resistor set for 1MHz, can be overwritten by signal at ROSC
Regulators on with floating enable
Mistake: place compensation R/C in series

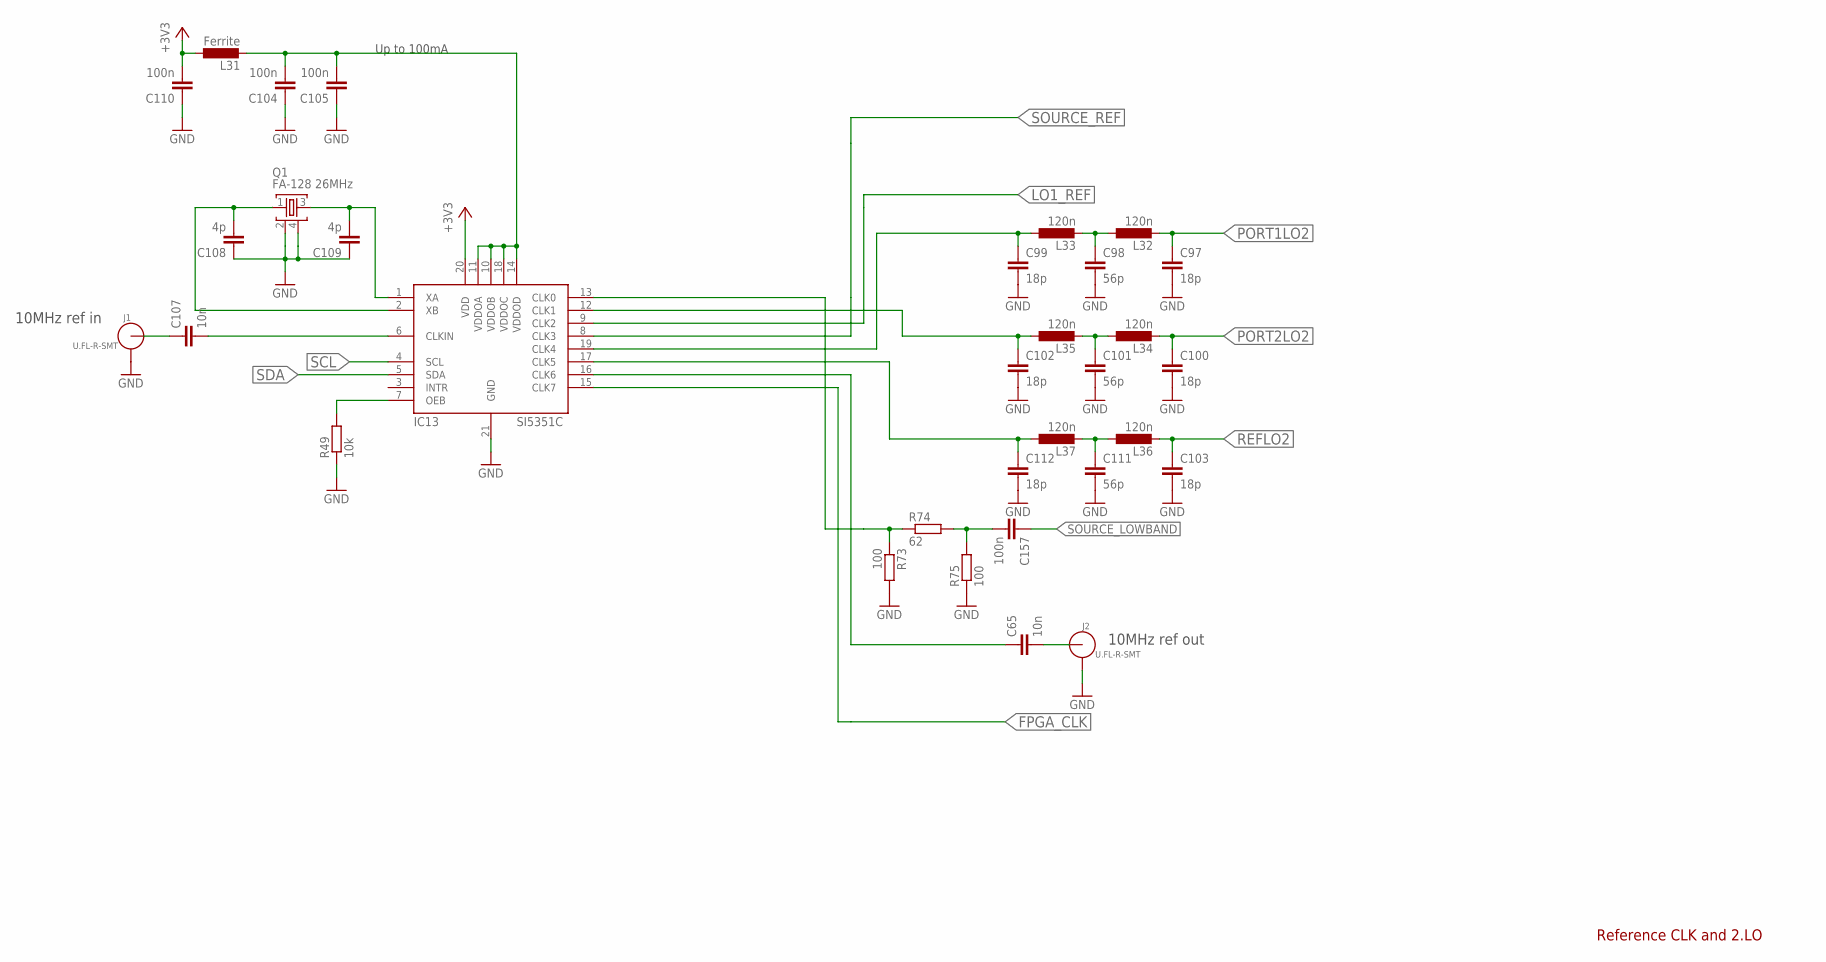
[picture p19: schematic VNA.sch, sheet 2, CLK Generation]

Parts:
C65, C107: 10n; C0603
C97, C99, C100, C102, C103, C112: 18p; C0603
C98, C101, C111: 56p; C0603
C104, C105, C110, C157: 100n; C0603
C108, C109: 4p; C0603
IC13: SI5351C; QFN50P400X400X90-21T270N
J1, J2: U.FL-R-SMT; U.FL_SMT
L31: Ferrite; R0603
L32, L33, L34, L35, L36, L37: 120n; R0603
Q1: FA-128 26MHz; FA-128
R49: 10k; R0603
R73, R75: 100; R0603
R74: 62; R0603

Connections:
+3V3: C110.2, IC13.20 (VDD), L31.1; also elsewhere on the board
FPGA_CLK: IC13.15 (CLK7); also elsewhere on the board
GND: C97.2, C98.2, C99.2, C100.2, C101.2, C102.2, C103.2, C104.1, C105.1, C108.1, C109.1, C110.1, C111.2, C112.2, IC13.21 (GND), J1.GND1, J1.GND2, J2.GND1, J2.GND2, Q1.2, Q1.4, R49.1, R73.2, R75.1; also elsewhere on the board
LO1_REF: IC13.9 (CLK2); also elsewhere on the board
unnamed: C65.2, J2.SIG (ANT)
unnamed: C98.1, L32.1, L33.2
unnamed: C101.1, L34.1, L35.2
unnamed: C102.1, IC13.12 (CLK1), L35.1
unnamed: C111.1, L36.1, L37.2
unnamed: C99.1, IC13.19 (CLK4), L33.1
unnamed: C65.1, IC13.16 (CLK6)
unnamed: C107.1, J1.SIG (ANT)
unnamed: C107.2, IC13.6 (CLKIN)
unnamed: C104.2, C105.2, IC13.10 (VDDOB), IC13.11 (VDDOA), IC13.14 (VDDOD), IC13.18 (VDDOC), L31.2
unnamed: IC13.7 (OEB), R49.2
unnamed: C109.2, IC13.1 (XA), Q1.3
unnamed: C108.2, IC13.2 (XB), Q1.1
unnamed: IC13.13 (CLK0), R73.1, R74.1
unnamed: C157.2, R74.2, R75.2
unnamed: C112.1, IC13.17 (CLK5), L37.1
PORT1LO2: C97.1, L32.2; also elsewhere on the board
PORT2LO2: C100.1, L34.2; also elsewhere on the board
REFLO2: C103.1, L36.2; also elsewhere on the board
SCL: IC13.4 (SCL); also elsewhere on the board
SDA: IC13.5 (SDA); also elsewhere on the board
SOURCE_LOWBAND: C157.1; also elsewhere on the board
SOURCE_REF: IC13.8 (CLK3); also elsewhere on the board

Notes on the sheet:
Reference CLK and 2.LO
10MHz ref in
10MHz ref out
Up to 100mA

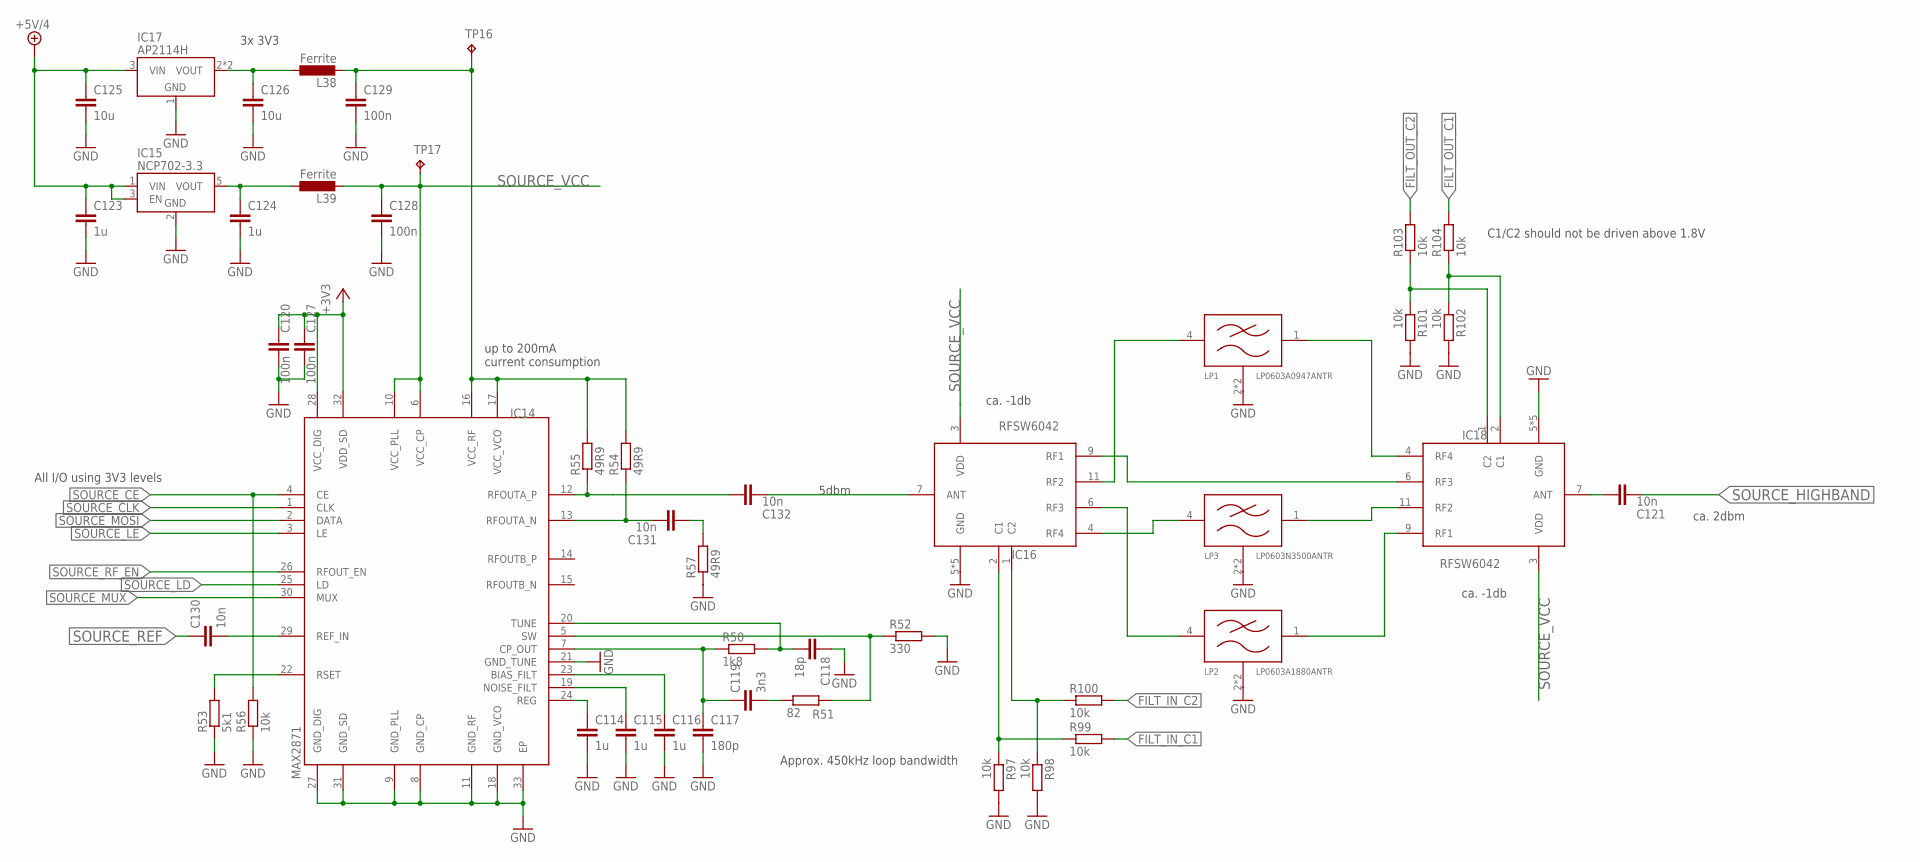
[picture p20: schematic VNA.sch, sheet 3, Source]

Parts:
C114, C115, C116, C123, C124: 1u; C0603
C117: 180p; C0603
C118: 18p; C0603
C119: 3n3; C0603
C120, C127, C128, C129: 100n; C0603
C121, C130, C131, C132: 10n; C0603
C125, C126: 10u; C1206
IC14: MAX2871; QFN50P500X500X80-33T310
IC15: NCP702-3.3; SOT95P240X110-5
IC16, IC18: RFSW6042; QFN40P180X180X55-13T76N
IC17: AP2114H; SOT230P700X180-4
L38, L39: Ferrite; R0603
LP1: LP0603A0947ANTR; FILTRDFN160X84X70-4N
LP2: LP0603A1880ANTR; FILTRDFN160X84X70-4N
LP3: LP0603N3500ANTR; FILTRDFN160X84X70-4N
R50: 1k8; R0603
R51: 82; R0603
R52: 330; R0603
R53: 5k1; R0603
R54, R55, R57: 49R9; R0603
R56, R97, R98, R99, R100, R101, R102, R103, R104: 10k; R0603
TP16, TP17: TPB1,27; B1,27

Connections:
+3V3: C120.1, C127.1, IC14.28 (VCC_DIG), IC14.32 (VDD_SD); also elsewhere on the board
+5V/4: C123.1, C125.1, IC15.1 (VIN), IC15.3 (EN), IC17.3 (VIN); also elsewhere on the board
FILT_IN_C1: R99.2; also elsewhere on the board
FILT_IN_C2: R100.2; also elsewhere on the board
FILT_OUT_C1: R104.2; also elsewhere on the board
FILT_OUT_C2: R103.2; also elsewhere on the board
GND: C114.2, C115.2, C116.2, C117.2, C118.1, C120.2, C123.2, C124.2, C125.2, C126.2, C127.2, C128.2, C129.2, IC14.8 (GND_CP), IC14.9 (GND_PLL), IC14.11 (GND_RF), IC14.18 (GND_VCO), IC14.21 (GND_TUNE), IC14.27 (GND_DIG), IC14.31 (GND_SD), IC14.33 (EP), IC15.2 (GND), IC16.5 (GND), IC16.8 (GND), IC16.10 (GND), IC16.12 (GND), IC16.13 (GND), IC17.1 (GND), IC18.5 (GND), IC18.8 (GND), IC18.10 (GND), IC18.12 (GND), IC18.13 (GND), LP1.2 (GND), LP1.3 (GND), LP2.2 (GND), LP2.3 (GND), LP3.2 (GND), LP3.3 (GND), R52.2, R53.1, R56.1, R57.1, R97.2, R98.2, R101.2, R102.2; also elsewhere on the board
unnamed: C118.2, IC14.20 (TUNE), R50.2
unnamed: C117.1, C119.1, IC14.7 (CP_OUT), R50.1
unnamed: C114.1, IC14.24 (REG)
unnamed: C115.1, IC14.19 (NOISE_FILT)
unnamed: C116.1, IC14.23 (BIAS_FILT)
unnamed: C119.2, R51.1
unnamed: IC14.5 (SW), R51.2, R52.1
unnamed: IC14.22 (RSET), R53.2
unnamed: C129.1, IC14.16 (VCC_RF), IC14.17 (VCC_VCO), L38.2, R54.2, R55.2, TP16.TP
unnamed: C130.2, IC14.29 (REF_IN)
unnamed: C132.1, IC14.12 (RFOUTA_P), R55.1
unnamed: C131.2, IC14.13 (RFOUTA_N), R54.1
unnamed: C131.1, R57.2
unnamed: C132.2, IC16.7 (ANT)
unnamed: IC16.9 (RF1), IC18.6 (RF3)
unnamed: IC16.11 (RF2), LP1.4 (IN)
unnamed: IC18.4 (RF4), LP1.1 (OUT)
unnamed: IC18.11 (RF2), LP3.1 (OUT)
unnamed: IC18.9 (RF1), LP2.1 (OUT)
unnamed: IC16.6 (RF3), LP2.4 (IN)
unnamed: IC16.4 (RF4), LP3.4 (IN)
unnamed: C126.1, IC17.2 (VOUT), IC17.4 (VOUT), L38.1
unnamed: C124.1, IC15.5 (VOUT), L39.1
unnamed: C121.1, IC18.7 (ANT)
unnamed: IC16.2 (C1), R97.1, R99.1
unnamed: IC16.1 (C2), R98.1, R100.1
unnamed: IC18.1 (C2), R101.1, R103.1
unnamed: IC18.2 (C1), R102.1, R104.1
SOURCE_CE: IC14.4 (CE), R56.2; also elsewhere on the board
SOURCE_CLK: IC14.1 (CLK); also elsewhere on the board
SOURCE_HIGHBAND: C121.2; also elsewhere on the board
SOURCE_LD: IC14.25 (LD); also elsewhere on the board
SOURCE_LE: IC14.3 (LE); also elsewhere on the board
SOURCE_MOSI: IC14.2 (DATA); also elsewhere on the board
SOURCE_MUX: IC14.30 (MUX); also elsewhere on the board
SOURCE_REF: C130.1; also elsewhere on the board
SOURCE_RF_EN: IC14.26 (RFOUT_EN); also elsewhere on the board
SOURCE_VCC: C128.1, IC14.6 (VCC_CP), IC14.10 (VCC_PLL), IC16.3 (VDD), IC18.3 (VDD), L39.2, TP17.TP

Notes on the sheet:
up to 200mA current consumption
All I/O using 3V3 levels
3x 3V3
Approx. 450kHz loop bandwidth
5dbm
ca. -1db
ca. 2dbm
C1/C2 should not be driven above 1.8V

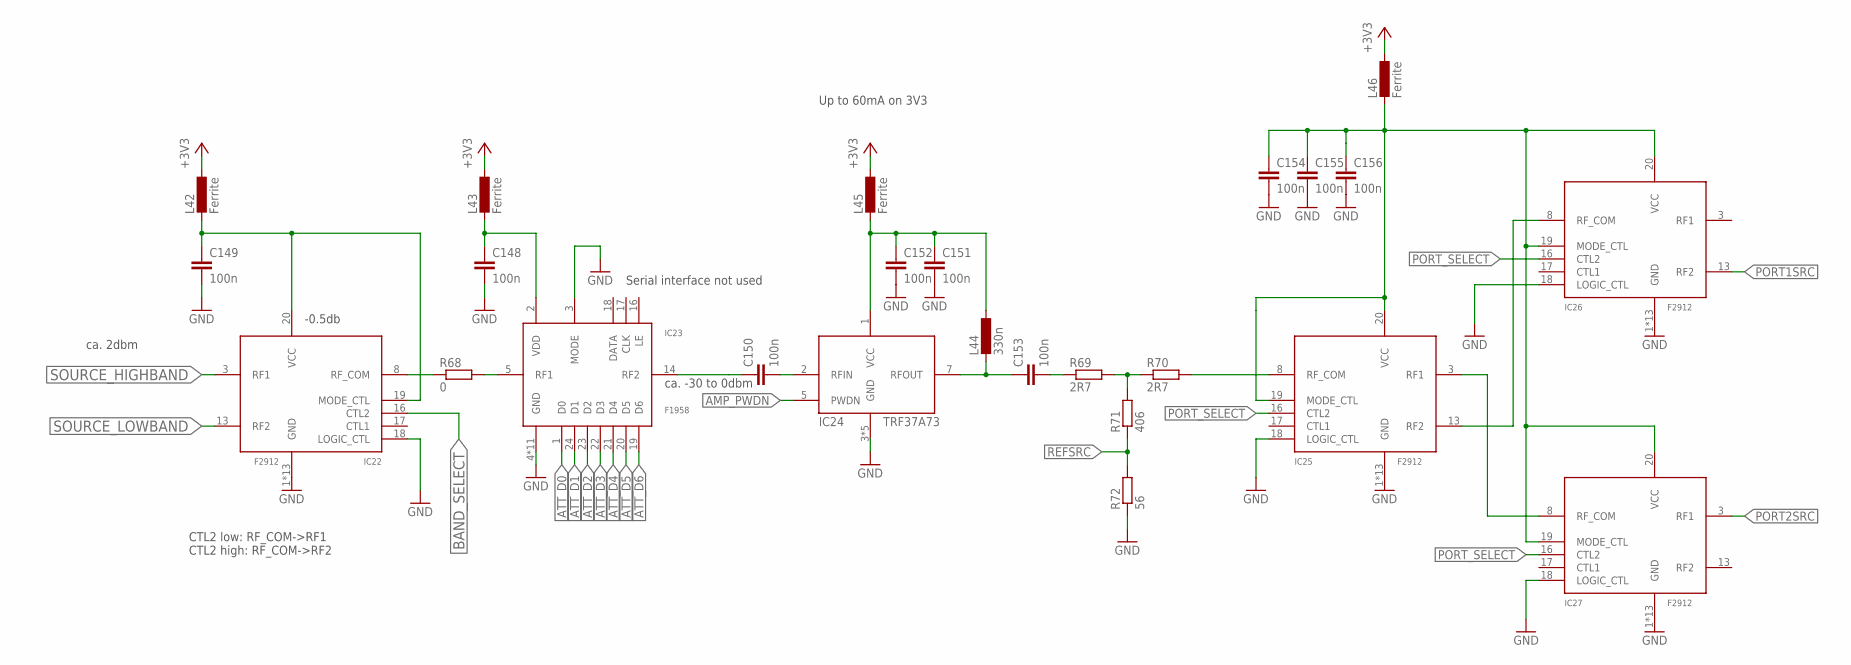
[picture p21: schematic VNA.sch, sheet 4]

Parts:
C148, C149, C150, C151, C152, C153, C154, C155, C156: 100n; C0603
IC22, IC25, IC26, IC27: F2912; QFN50P400X400X75-21T206
IC23: F1958; QFN50P400X400X75-25T270
IC24: TRF37A73; SON50P200X200X80-9T90X160N
L42, L43, L45, L46: Ferrite; R0603
L44: 330n; R0603
R68: 0; R0603
R69, R70: 2R7; R0603
R71: 406; R0603
R72: 56; R0603

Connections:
+3V3: L42.1, L43.1, L45.1, L46.1; also elsewhere on the board
AMP_PWDN: IC24.5 (PWDN); also elsewhere on the board
ATT_D0: IC23.1 (D0); also elsewhere on the board
ATT_D1: IC23.24 (D1); also elsewhere on the board
ATT_D2: IC23.23 (D2); also elsewhere on the board
ATT_D3: IC23.22 (D3); also elsewhere on the board
ATT_D4: IC23.21 (D4); also elsewhere on the board
ATT_D5: IC23.20 (D5); also elsewhere on the board
ATT_D6: IC23.19 (D6); also elsewhere on the board
BAND_SELECT: IC22.16 (CTL2); also elsewhere on the board
GND: C148.2, C149.2, C151.2, C152.2, C154.2, C155.2, C156.2, IC22.1 (GND), IC22.2 (GND), IC22.4 (GND), IC22.5 (GND), IC22.6 (GND), IC22.7 (GND), IC22.9 (GND), IC22.10 (GND), IC22.11 (GND), IC22.12 (GND), IC22.14 (GND), IC22.15 (GND), IC22.18 (LOGIC_CTL), IC22.21 (GND), IC23.3 (MODE), IC23.4 (GND), IC23.6 (GND), IC23.7 (GND), IC23.8 (GND), IC23.9 (GND), IC23.10 (GND), IC23.11 (GND), IC23.12 (GND), IC23.13 (GND), IC23.15 (GND), IC23.25 (GND), IC24.3 (GND), IC24.4 (GND), IC24.6 (GND), IC24.8 (GND), IC24.9 (GND), IC25.1 (GND), IC25.2 (GND), IC25.4 (GND), IC25.5 (GND), IC25.6 (GND), IC25.7 (GND), IC25.9 (GND), IC25.10 (GND), IC25.11 (GND), IC25.12 (GND), IC25.14 (GND), IC25.15 (GND), IC25.18 (LOGIC_CTL), IC25.21 (GND), IC26.1 (GND), IC26.2 (GND), IC26.4 (GND), IC26.5 (GND), IC26.6 (GND), IC26.7 (GND), IC26.9 (GND), IC26.10 (GND), IC26.11 (GND), IC26.12 (GND), IC26.14 (GND), IC26.15 (GND), IC26.18 (LOGIC_CTL), IC26.21 (GND), IC27.1 (GND), IC27.2 (GND), IC27.4 (GND), IC27.5 (GND), IC27.6 (GND), IC27.7 (GND), IC27.9 (GND), IC27.10 (GND), IC27.11 (GND), IC27.12 (GND), IC27.14 (GND), IC27.15 (GND), IC27.18 (LOGIC_CTL), IC27.21 (GND), R72.1; also elsewhere on the board
unnamed: C149.1, IC22.19 (MODE_CTL), IC22.20 (VCC), L42.2
unnamed: IC22.8 (RF_COM), R68.1
unnamed: C148.1, IC23.2 (VDD), L43.2
unnamed: C150.1, IC23.14 (RF2)
unnamed: C150.2, IC24.2 (RFIN)
unnamed: C153.1, IC24.7 (RFOUT), L44.2
unnamed: C153.2, R69.1
unnamed: IC25.8 (RF_COM), R70.2
unnamed: C151.1, C152.1, IC24.1 (VCC), L44.1, L45.2
unnamed: R69.2, R70.1, R71.2
unnamed: IC25.13 (RF2), IC26.8 (RF_COM)
unnamed: IC25.3 (RF1), IC27.8 (RF_COM)
unnamed: C154.1, C155.1, C156.1, IC25.19 (MODE_CTL), IC25.20 (VCC), IC26.19 (MODE_CTL), IC26.20 (VCC), IC27.19 (MODE_CTL), IC27.20 (VCC), L46.2
unnamed: IC23.5 (RF1), R68.2
PORT1SRC: IC26.13 (RF2); also elsewhere on the board
PORT2SRC: IC27.3 (RF1); also elsewhere on the board
PORT_SELECT: IC25.16 (CTL2), IC26.16 (CTL2), IC27.16 (CTL2); also elsewhere on the board
REFSRC: R71.1, R72.2; also elsewhere on the board
SOURCE_HIGHBAND: IC22.3 (RF1); also elsewhere on the board
SOURCE_LOWBAND: IC22.13 (RF2); also elsewhere on the board

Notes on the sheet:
CTL2 low: RF_COM->RF1 CTL2 high: RF_COM->RF2
Serial interface not used
ca. 2dbm
-0.5db
ca. -30 to 0dbm
Up to 60mA on 3V3

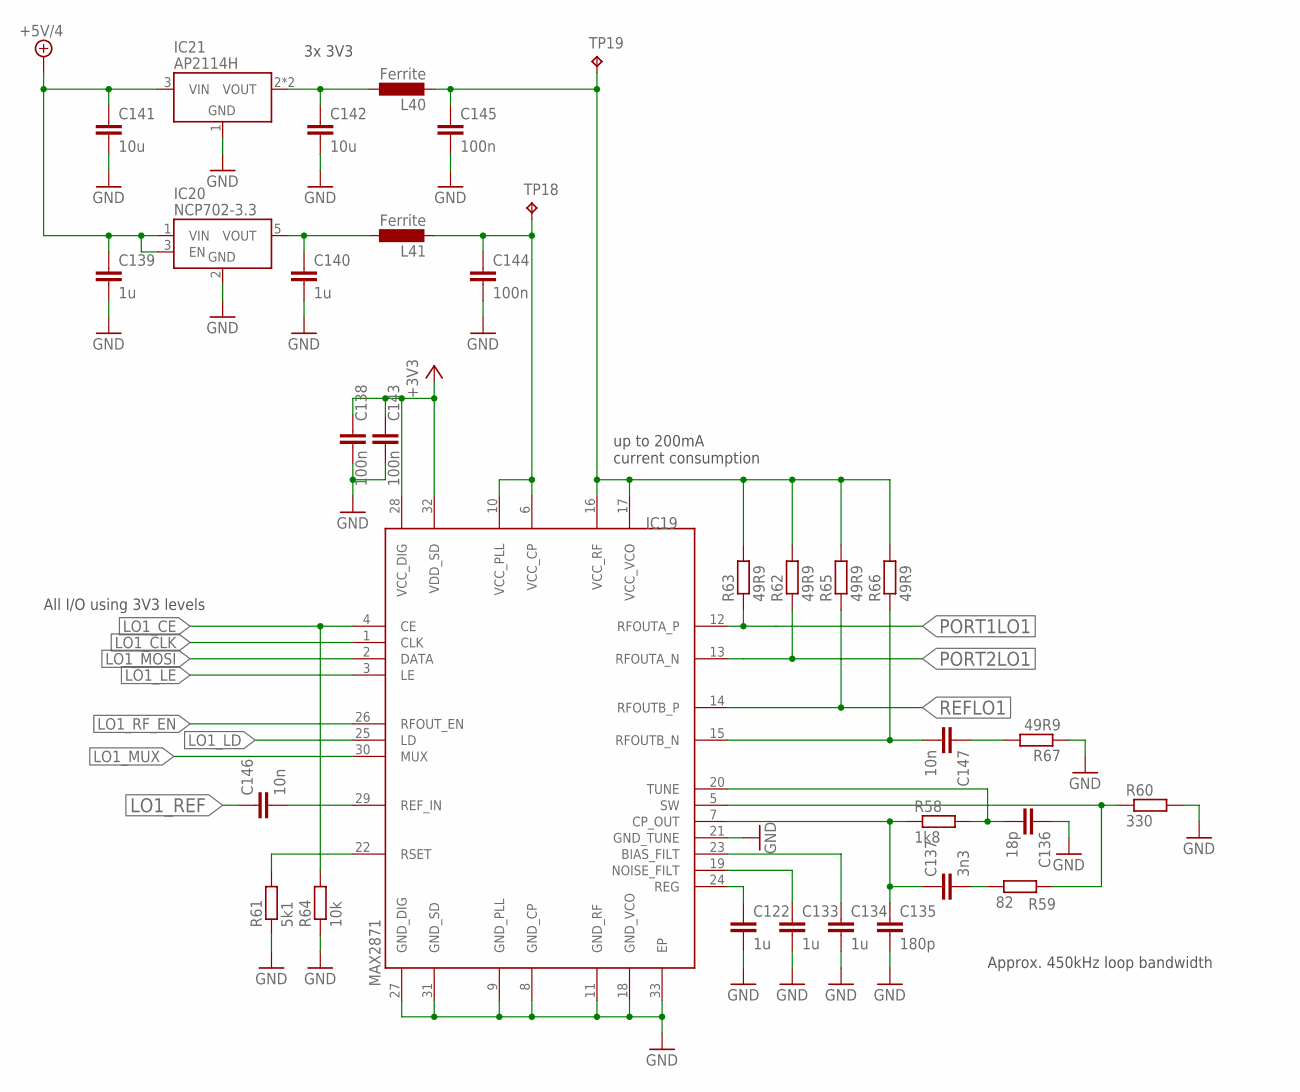
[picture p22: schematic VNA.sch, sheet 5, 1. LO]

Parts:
C122, C133, C134, C139, C140: 1u; C0603
C135: 180p; C0603
C136: 18p; C0603
C137: 3n3; C0603
C138, C143, C144, C145: 100n; C0603
C141, C142: 10u; C1206
C146, C147: 10n; C0603
IC19: MAX2871; QFN50P500X500X80-33T310
IC20: NCP702-3.3; SOT95P240X110-5
IC21: AP2114H; SOT230P700X180-4
L40, L41: Ferrite; R0603
R58: 1k8; R0603
R59: 82; R0603
R60: 330; R0603
R61: 5k1; R0603
R62, R63, R65, R66, R67: 49R9; R0603
R64: 10k; R0603
TP18, TP19: TPB1,27; B1,27

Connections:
+3V3: C138.1, C143.1, IC19.28 (VCC_DIG), IC19.32 (VDD_SD); also elsewhere on the board
+5V/4: C139.1, C141.1, IC20.1 (VIN), IC20.3 (EN), IC21.3 (VIN); also elsewhere on the board
GND: C122.2, C133.2, C134.2, C135.2, C136.1, C138.2, C139.2, C140.2, C141.2, C142.2, C143.2, C144.2, C145.2, IC19.8 (GND_CP), IC19.9 (GND_PLL), IC19.11 (GND_RF), IC19.18 (GND_VCO), IC19.21 (GND_TUNE), IC19.27 (GND_DIG), IC19.31 (GND_SD), IC19.33 (EP), IC20.2 (GND), IC21.1 (GND), R60.2, R61.1, R64.1, R67.1; also elsewhere on the board
LO1_CE: IC19.4 (CE), R64.2; also elsewhere on the board
LO1_CLK: IC19.1 (CLK); also elsewhere on the board
LO1_LD: IC19.25 (LD); also elsewhere on the board
LO1_LE: IC19.3 (LE); also elsewhere on the board
LO1_MOSI: IC19.2 (DATA); also elsewhere on the board
LO1_MUX: IC19.30 (MUX); also elsewhere on the board
LO1_REF: C146.1; also elsewhere on the board
LO1_RF_EN: IC19.26 (RFOUT_EN); also elsewhere on the board
unnamed: C144.1, IC19.6 (VCC_CP), IC19.10 (VCC_PLL), L41.2, TP18.TP
unnamed: C136.2, IC19.20 (TUNE), R58.2
unnamed: C135.1, C137.1, IC19.7 (CP_OUT), R58.1
unnamed: C122.1, IC19.24 (REG)
unnamed: C133.1, IC19.19 (NOISE_FILT)
unnamed: C134.1, IC19.23 (BIAS_FILT)
unnamed: C137.2, R59.1
unnamed: IC19.5 (SW), R59.2, R60.1
unnamed: IC19.22 (RSET), R61.2
unnamed: C145.1, IC19.16 (VCC_RF), IC19.17 (VCC_VCO), L40.2, R62.2, R63.2, R65.2, R66.2, TP19.TP
unnamed: C146.2, IC19.29 (REF_IN)
unnamed: C147.1, R67.2
unnamed: C142.1, IC21.2 (VOUT), IC21.4 (VOUT), L40.1
unnamed: C140.1, IC20.5 (VOUT), L41.1
unnamed: C147.2, IC19.15 (RFOUTB_N), R66.1
PORT1LO1: IC19.12 (RFOUTA_P), R63.1; also elsewhere on the board
PORT2LO1: IC19.13 (RFOUTA_N), R62.1; also elsewhere on the board
REFLO1: IC19.14 (RFOUTB_P), R65.1; also elsewhere on the board

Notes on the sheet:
up to 200mA current consumption
All I/O using 3V3 levels
3x 3V3
Approx. 450kHz loop bandwidth

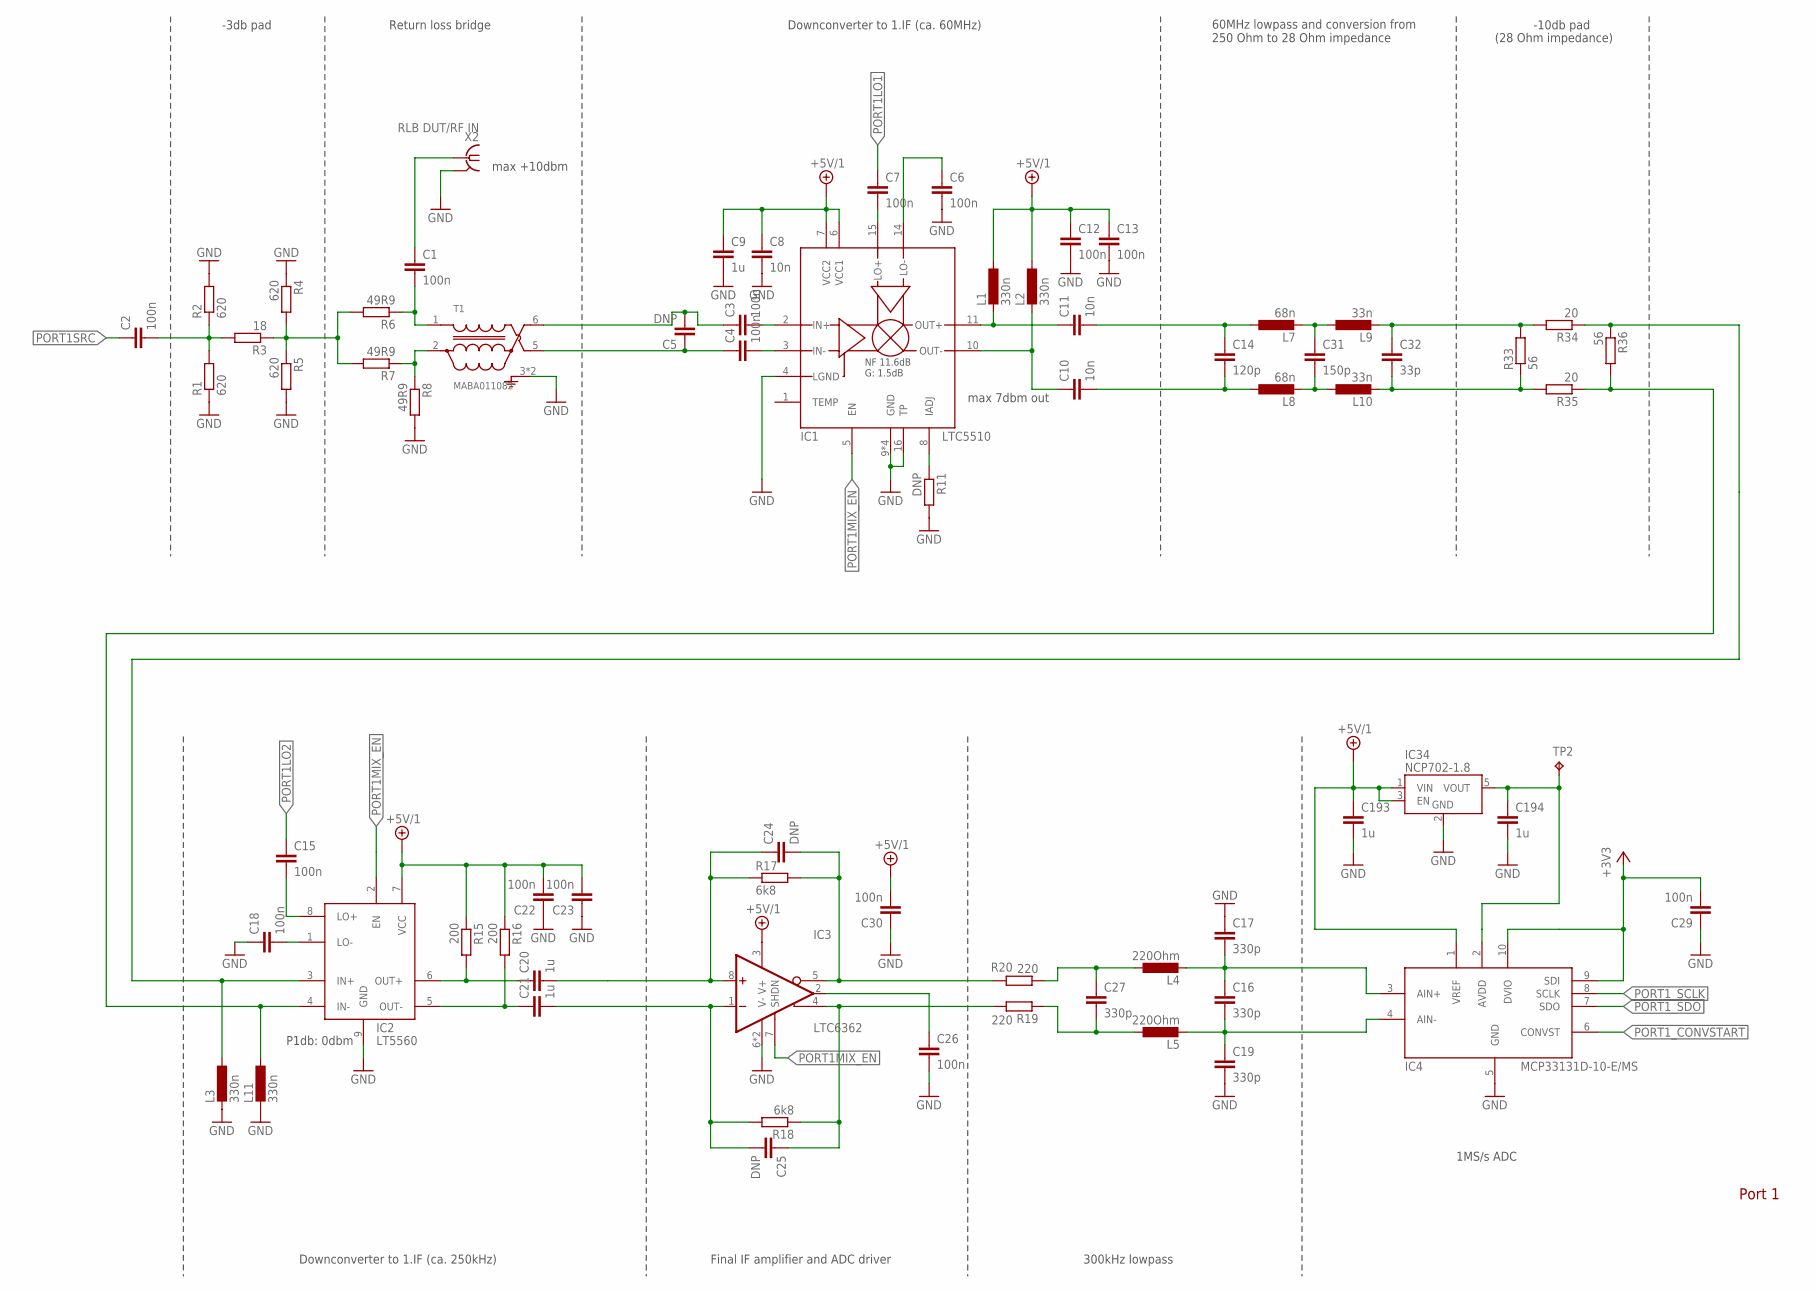
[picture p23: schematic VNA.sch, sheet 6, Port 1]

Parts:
C1, C2, C3, C4, C6, C7, C12, C13, C15, C18, C22, C23, C26, C29, C30: 100n; C0603
C5, C24, C25: DNP; C0603
C8, C10, C11: 10n; C0603
C9, C20, C21, C193, C194: 1u; C0603
C14: 120p; C0603
C16, C17, C19, C27: 330p; C0603
C31: 150p; C0603
C32: 33p; C0603
IC1: LTC5510; QFN65P400X400X75-17T215N
IC2: LT5560; SON50P300X300X80-9T165X238
IC3: LTC6362; SON50P300X300X80-9T165X238
IC4: MCP33131D-10-E/MS; SOP50P490X110-10N
IC34: NCP702-1.8; SOT95P240X110-5
L1, L2, L3, L11: 330n; R0603
L4, L5: 220Ohm; R0603
L7, L8: 68n; R0603
L9, L10: 33n; R0603
R1, R2, R4, R5: 620; R0603
R3: 18; R0603
R6, R7, R8: 49R9; R0603
R11: DNP; R0603
R15, R16: 200; R0603
R17, R18: 6k8; R0603
R19, R20: 220; R0603
R33, R36: 56; R0603
R34, R35: 20; R0603
T1: MABA011082; MACOM_BALUN
TP2: TPB1,27; B1,27
X2: RLB DUT/RF IN; J502-ND-142-0711-821/826

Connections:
+3V3: C29.2, IC4.9 (SDI), IC4.10 (DVIO); also elsewhere on the board
+5V/1: C8.1, C9.1, C12.1, C13.1, C22.2, C23.2, C30.2, C193.1, IC1.6 (VCC1), IC1.7 (VCC2), IC2.7 (VCC), IC3.3 (V+), IC4.1 (VREF), IC34.1 (VIN), IC34.3 (EN), L1.1, L2.1, R15.1, R16.1; also elsewhere on the board
GND: C6.2, C8.2, C9.2, C12.2, C13.2, C17.1, C18.1, C19.2, C22.1, C23.1, C26.2, C29.1, C30.1, C193.2, C194.2, IC1.4 (LGND), IC1.9 (GND), IC1.12 (GND), IC1.13 (GND), IC1.16 (TP), IC1.17 (GND), IC2.9 (GND), IC3.6 (V-), IC3.9 (V-), IC4.5 (GND), IC34.2 (GND), L3.2, L11.2, R1.1, R2.2, R4.1, R5.2, R8.2, R11.2, T1.3 (GND), T1.4 (GND), X2.G@1 (2), X2.G@2 (2), X2.G@3 (2), X2.G@4 (2); also elsewhere on the board
unnamed: C2.2, R1.2, R2.1, R3.2
unnamed: R3.1, R4.2, R5.1, R6.2, R7.2
unnamed: C11.2, C14.1, L7.1
unnamed: C1.2, R6.1, T1.1 (PIN1)
unnamed: R7.1, R8.1, T1.2 (PIN2)
unnamed: C1.1, X2.1
unnamed: C3.2, IC1.2 (IN+)
unnamed: C4.2, IC1.3 (IN-)
unnamed: C4.1, C5.1, T1.5 (PIN5)
unnamed: C3.1, C5.2, T1.6 (PIN6)
unnamed: C6.1, IC1.14 (LO-)
unnamed: C7.2, IC1.15 (LO+)
unnamed: C16.1, C17.2, IC4.3 (AIN+), L4.2
unnamed: C11.1, IC1.11 (OUT+), L1.2
unnamed: C10.1, IC1.10 (OUT-), L2.2
unnamed: C10.2, C14.2, L8.1
unnamed: C31.2, L8.2, L10.1
unnamed: C15.2, IC2.8 (LO+)
unnamed: IC1.8 (IADJ), R11.1
unnamed: C16.2, C19.1, IC4.4 (AIN-), L5.2
unnamed: C18.2, IC2.1 (LO-)
unnamed: C20.1, IC2.6 (OUT+), R15.2
unnamed: C21.1, IC2.5 (OUT-), R16.2
unnamed: C25.1, IC3.4 (+OUT), R18.1, R19.2
unnamed: C24.2, IC3.5 (-OUT), R17.2, R20.2
unnamed: C31.1, L7.2, L9.1
unnamed: IC2.3 (IN+), L3.1, R34.1, R36.1
unnamed: C32.1, L9.2, R33.2, R34.2
unnamed: C32.2, L10.2, R33.1, R35.2
unnamed: IC2.4 (IN-), L11.1, R35.1, R36.2
unnamed: C21.2, C25.2, IC3.1 (-IN), R18.2
unnamed: C20.2, C24.1, IC3.8 (+IN), R17.1
unnamed: C194.1, IC4.2 (AVDD), IC34.5 (VOUT), TP2.TP
OUT+: C27.1, L4.1, R20.1
OUT-: C27.2, L5.1, R19.1
OUT_CM: C26.1, IC3.2 (VOCM)
PORT1LO1: C7.1; also elsewhere on the board
PORT1LO2: C15.1; also elsewhere on the board
PORT1MIX_EN: IC1.5 (EN), IC2.2 (EN), IC3.7 (SHDN); also elsewhere on the board
PORT1SRC: C2.1; also elsewhere on the board
PORT1_CONVSTART: IC4.6 (CONVST); also elsewhere on the board
PORT1_SCLK: IC4.8 (SCLK); also elsewhere on the board
PORT1_SDO: IC4.7 (SDO); also elsewhere on the board

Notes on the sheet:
max +10dbm
max 7dbm out
P1db: 0dbm
-3db pad
Return loss bridge
Downconverter to 1.IF (ca. 60MHz)
60MHz lowpass and conversion from 250 Ohm to 28 Ohm impedance
-10db pad
(28 Ohm impedance)
Downconverter to 1.IF (ca. 250kHz)
Final IF amplifier and ADC driver
300kHz lowpass
1MS/s ADC
Port 1

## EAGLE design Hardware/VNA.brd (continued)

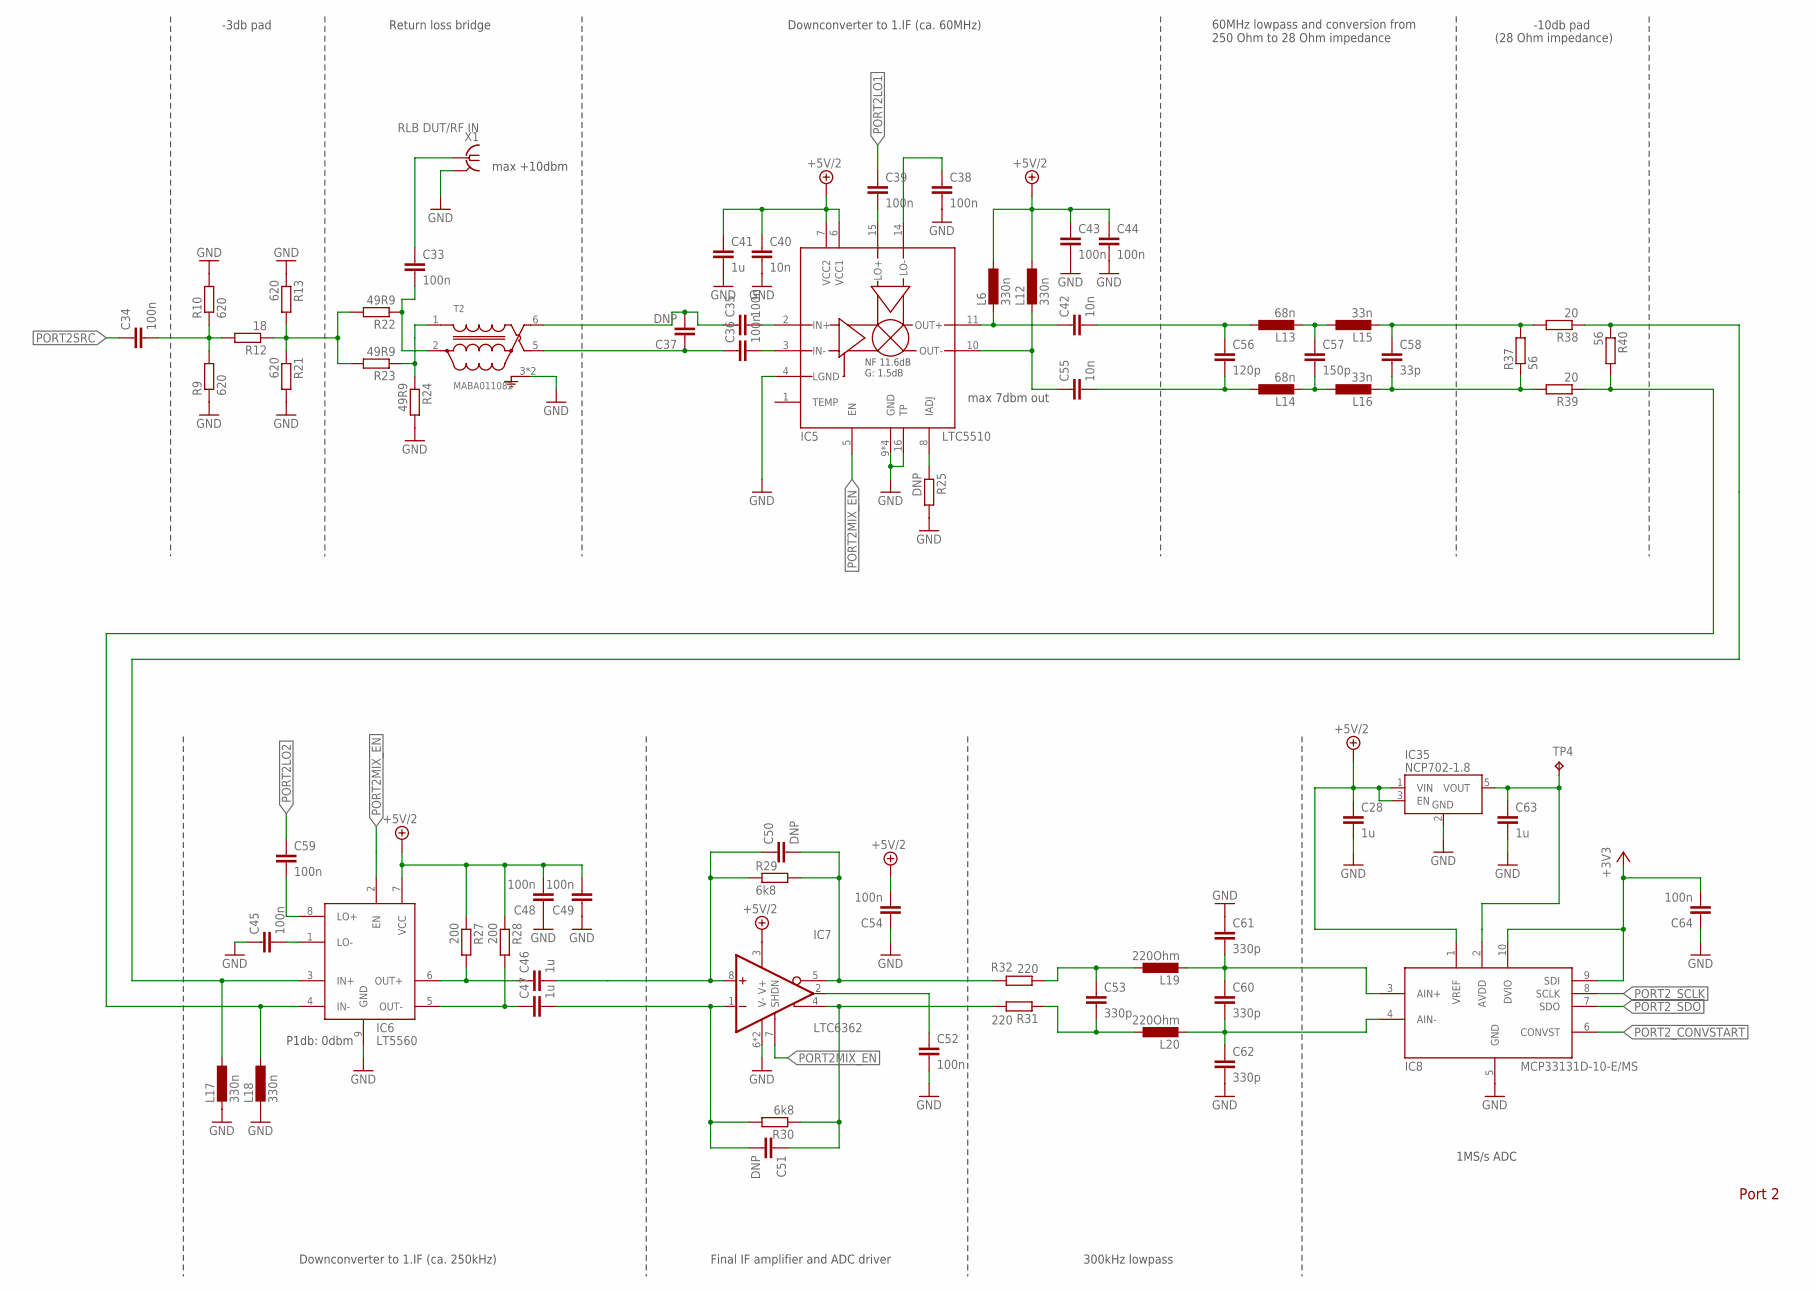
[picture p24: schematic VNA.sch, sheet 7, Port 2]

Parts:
C28, C41, C46, C47, C63: 1u; C0603
C33, C34, C35, C36, C38, C39, C43, C44, C45, C48, C49, C52, C54, C59, C64: 100n; C0603
C37, C50, C51: DNP; C0603
C40, C42, C55: 10n; C0603
C53, C60, C61, C62: 330p; C0603
C56: 120p; C0603
C57: 150p; C0603
C58: 33p; C0603
IC5: LTC5510; QFN65P400X400X75-17T215N
IC6: LT5560; SON50P300X300X80-9T165X238
IC7: LTC6362; SON50P300X300X80-9T165X238
IC8: MCP33131D-10-E/MS; SOP50P490X110-10N
IC35: NCP702-1.8; SOT95P240X110-5
L6, L12, L17, L18: 330n; R0603
L13, L14: 68n; R0603
L15, L16: 33n; R0603
L19, L20: 220Ohm; R0603
R9, R10, R13, R21: 620; R0603
R12: 18; R0603
R22, R23, R24: 49R9; R0603
R25: DNP; R0603
R27, R28: 200; R0603
R29, R30: 6k8; R0603
R31, R32: 220; R0603
R37, R40: 56; R0603
R38, R39: 20; R0603
T2: MABA011082; MACOM_BALUN
TP4: TPB1,27; B1,27
X1: RLB DUT/RF IN; J502-ND-142-0711-821/826

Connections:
+3V3: C64.2, IC8.9 (SDI), IC8.10 (DVIO); also elsewhere on the board
+5V/2: C28.1, C40.1, C41.1, C43.1, C44.1, C48.2, C49.2, C54.2, IC5.6 (VCC1), IC5.7 (VCC2), IC6.7 (VCC), IC7.3 (V+), IC8.1 (VREF), IC35.1 (VIN), IC35.3 (EN), L6.1, L12.1, R27.1, R28.1; also elsewhere on the board
GND: C28.2, C38.2, C40.2, C41.2, C43.2, C44.2, C45.1, C48.1, C49.1, C52.2, C54.1, C61.1, C62.2, C63.2, C64.1, IC5.4 (LGND), IC5.9 (GND), IC5.12 (GND), IC5.13 (GND), IC5.16 (TP), IC5.17 (GND), IC6.9 (GND), IC7.6 (V-), IC7.9 (V-), IC8.5 (GND), IC35.2 (GND), L17.2, L18.2, R9.1, R10.2, R13.1, R21.2, R24.2, R25.2, T2.3 (GND), T2.4 (GND), X1.G@1 (2), X1.G@2 (2), X1.G@3 (2), X1.G@4 (2); also elsewhere on the board
unnamed: C34.2, R9.2, R10.1, R12.2
unnamed: R12.1, R13.2, R21.1, R22.2, R23.2
unnamed: C33.2, R22.1, T2.2 (PIN2)
unnamed: R23.1, R24.1, T2.1 (PIN1)
unnamed: C33.1, X1.1
unnamed: C35.2, IC5.2 (IN+)
unnamed: C36.2, IC5.3 (IN-)
unnamed: C36.1, C37.1, T2.5 (PIN5)
unnamed: C35.1, C37.2, T2.6 (PIN6)
unnamed: C38.1, IC5.14 (LO-)
unnamed: C39.2, IC5.15 (LO+)
unnamed: C42.1, IC5.11 (OUT+), L6.2
unnamed: C55.1, IC5.10 (OUT-), L12.2
unnamed: IC5.8 (IADJ), R25.1
unnamed: C45.2, IC6.1 (LO-)
unnamed: C46.1, IC6.6 (OUT+), R27.2
unnamed: C47.1, IC6.5 (OUT-), R28.2
unnamed: C51.1, IC7.4 (+OUT), R30.1, R31.2
unnamed: C50.2, IC7.5 (-OUT), R29.2, R32.2
unnamed: C42.2, C56.1, L13.1
unnamed: C55.2, C56.2, L14.1
unnamed: C57.2, L14.2, L16.1
unnamed: C57.1, L13.2, L15.1
unnamed: IC6.3 (IN+), L17.1, R38.1, R40.1
unnamed: C59.2, IC6.8 (LO+)
unnamed: C60.1, C61.2, IC8.3 (AIN+), L19.2
unnamed: C60.2, C62.1, IC8.4 (AIN-), L20.2
unnamed: C58.1, L15.2, R37.2, R38.2
unnamed: C58.2, L16.2, R37.1, R39.2
unnamed: IC6.4 (IN-), L18.1, R39.1, R40.2
unnamed: C47.2, C51.2, IC7.1 (-IN), R30.2
unnamed: C46.2, C50.1, IC7.8 (+IN), R29.1
unnamed: C63.1, IC8.2 (AVDD), IC35.5 (VOUT), TP4.TP
OUT+1: C53.1, L19.1, R32.1
OUT-1: C53.2, L20.1, R31.1
OUT_CM1: C52.1, IC7.2 (VOCM)
PORT2LO1: C39.1; also elsewhere on the board
PORT2LO2: C59.1; also elsewhere on the board
PORT2MIX_EN: IC5.5 (EN), IC6.2 (EN), IC7.7 (SHDN); also elsewhere on the board
PORT2SRC: C34.1; also elsewhere on the board
PORT2_CONVSTART: IC8.6 (CONVST); also elsewhere on the board
PORT2_SCLK: IC8.8 (SCLK); also elsewhere on the board
PORT2_SDO: IC8.7 (SDO); also elsewhere on the board

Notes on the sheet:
max +10dbm
max 7dbm out
P1db: 0dbm
-3db pad
Return loss bridge
Downconverter to 1.IF (ca. 60MHz)
60MHz lowpass and conversion from 250 Ohm to 28 Ohm impedance
-10db pad
(28 Ohm impedance)
Downconverter to 1.IF (ca. 250kHz)
Final IF amplifier and ADC driver
300kHz lowpass
1MS/s ADC
Port 2

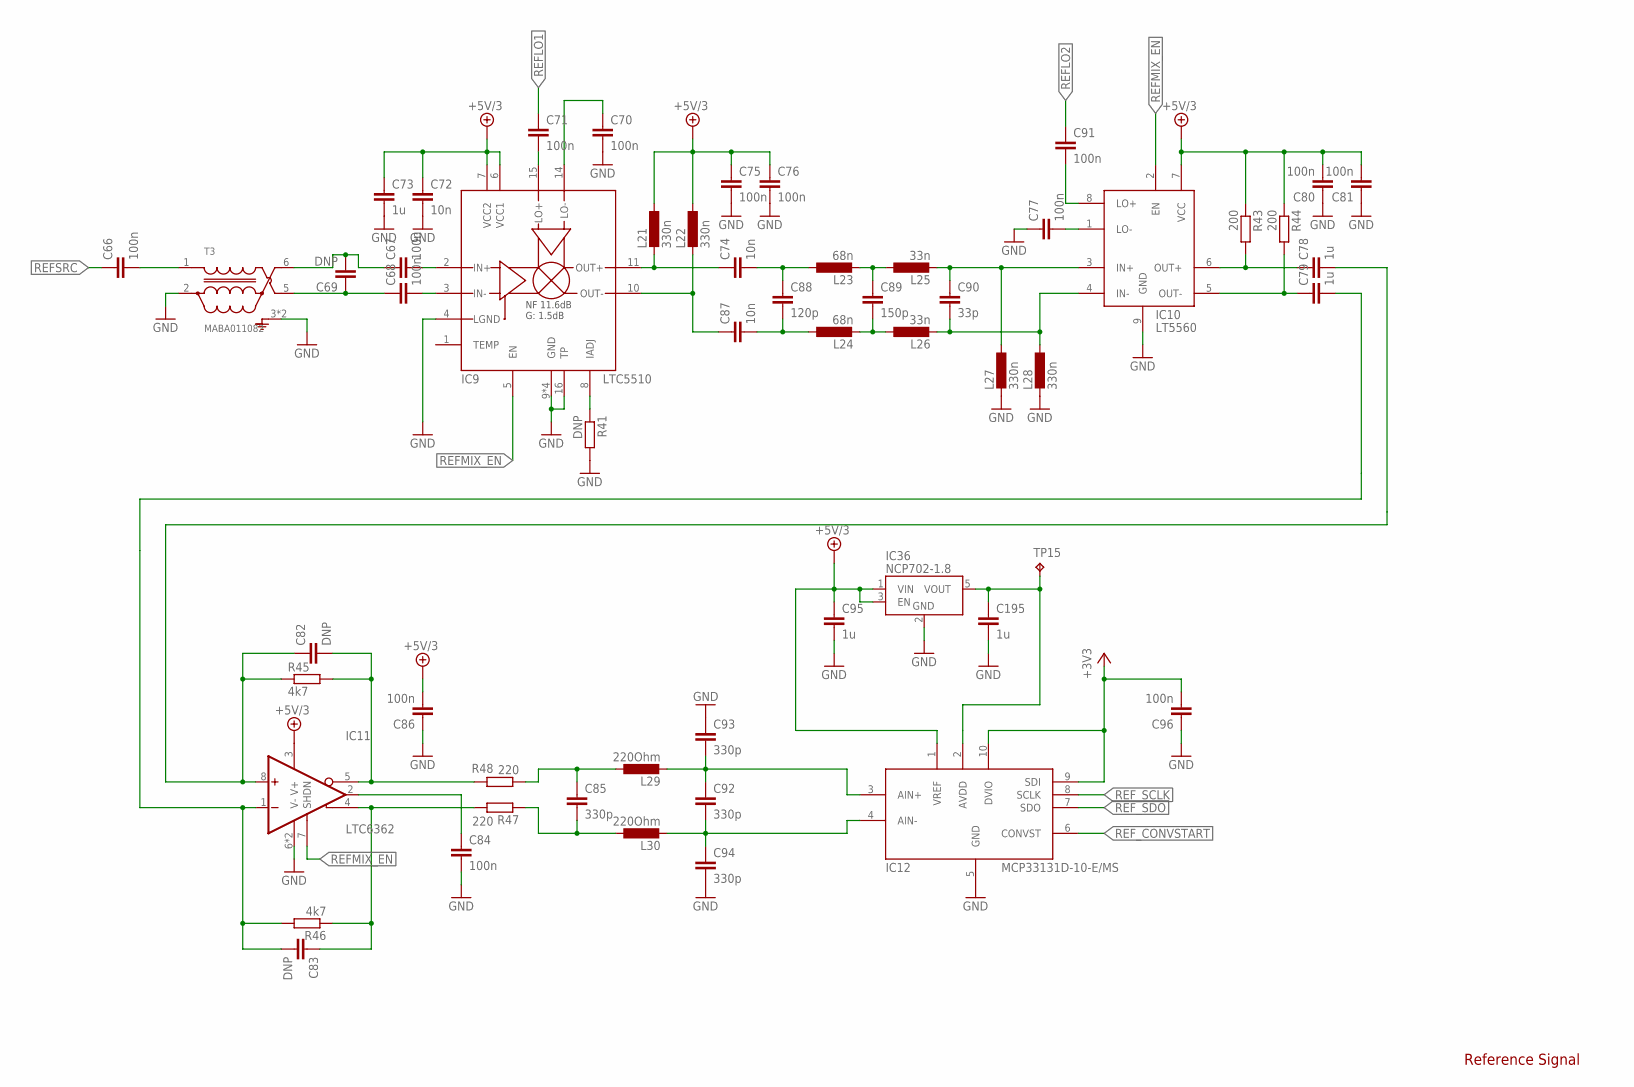
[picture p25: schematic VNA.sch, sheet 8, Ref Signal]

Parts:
C66, C67, C68, C70, C71, C75, C76, C77, C80, C81, C84, C86, C91, C96: 100n; C0603
C69, C82, C83: DNP; C0603
C72, C74, C87: 10n; C0603
C73, C78, C79, C95, C195: 1u; C0603
C85, C92, C93, C94: 330p; C0603
C88: 120p; C0603
C89: 150p; C0603
C90: 33p; C0603
IC9: LTC5510; QFN65P400X400X75-17T215N
IC10: LT5560; SON50P300X300X80-9T165X238
IC11: LTC6362; SON50P300X300X80-9T165X238
IC12: MCP33131D-10-E/MS; SOP50P490X110-10N
IC36: NCP702-1.8; SOT95P240X110-5
L21, L22, L27, L28: 330n; R0603
L23, L24: 68n; R0603
L25, L26: 33n; R0603
L29, L30: 220Ohm; R0603
R41: DNP; R0603
R43, R44: 200; R0603
R45, R46: 4k7; R0603
R47, R48: 220; R0603
T3: MABA011082; MACOM_BALUN
TP15: TPB1,27; B1,27

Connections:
+3V3: C96.2, IC12.9 (SDI), IC12.10 (DVIO); also elsewhere on the board
+5V/3: C72.1, C73.1, C75.1, C76.1, C80.2, C81.2, C86.2, C95.1, IC9.6 (VCC1), IC9.7 (VCC2), IC10.7 (VCC), IC11.3 (V+), IC12.1 (VREF), IC36.1 (VIN), IC36.3 (EN), L21.1, L22.1, R43.1, R44.1; also elsewhere on the board
GND: C70.2, C72.2, C73.2, C75.2, C76.2, C77.1, C80.1, C81.1, C84.2, C86.1, C93.1, C94.2, C95.2, C96.1, C195.2, IC9.4 (LGND), IC9.9 (GND), IC9.12 (GND), IC9.13 (GND), IC9.16 (TP), IC9.17 (GND), IC10.9 (GND), IC11.6 (V-), IC11.9 (V-), IC12.5 (GND), IC36.2 (GND), L27.2, L28.2, R41.2, T3.2 (PIN2), T3.3 (GND), T3.4 (GND); also elsewhere on the board
unnamed: C66.2, T3.1 (PIN1)
unnamed: C67.2, IC9.2 (IN+)
unnamed: C68.2, IC9.3 (IN-)
unnamed: C68.1, C69.1, T3.5 (PIN5)
unnamed: C67.1, C69.2, T3.6 (PIN6)
unnamed: C70.1, IC9.14 (LO-)
unnamed: C71.2, IC9.15 (LO+)
unnamed: C74.1, IC9.11 (OUT+), L21.2
unnamed: C87.1, IC9.10 (OUT-), L22.2
unnamed: IC9.8 (IADJ), R41.1
unnamed: C77.2, IC10.1 (LO-)
unnamed: C78.1, IC10.6 (OUT+), R43.2
unnamed: C79.1, IC10.5 (OUT-), R44.2
unnamed: C78.2, C82.1, IC11.8 (+IN), R45.1
unnamed: C79.2, C83.2, IC11.1 (-IN), R46.2
unnamed: C83.1, IC11.4 (+OUT), R46.1, R47.2
unnamed: C82.2, IC11.5 (-OUT), R45.2, R48.2
unnamed: C74.2, C88.1, L23.1
unnamed: C87.2, C88.2, L24.1
unnamed: C89.2, L24.2, L26.1
unnamed: C89.1, L23.2, L25.1
unnamed: C90.1, IC10.3 (IN+), L25.2, L27.1
unnamed: C90.2, IC10.4 (IN-), L26.2, L28.1
unnamed: C91.2, IC10.8 (LO+)
unnamed: C92.1, C93.2, IC12.3 (AIN+), L29.2
unnamed: C92.2, C94.1, IC12.4 (AIN-), L30.2
unnamed: C195.1, IC12.2 (AVDD), IC36.5 (VOUT), TP15.TP
OUT+2: C85.1, L29.1, R48.1
OUT-2: C85.2, L30.1, R47.1
OUT_CM2: C84.1, IC11.2 (VOCM)
REFLO1: C71.1; also elsewhere on the board
REFLO2: C91.1; also elsewhere on the board
REFMIX_EN: IC9.5 (EN), IC10.2 (EN), IC11.7 (SHDN); also elsewhere on the board
REFSRC: C66.1; also elsewhere on the board
REF_CONVSTART: IC12.6 (CONVST); also elsewhere on the board
REF_SCLK: IC12.8 (SCLK); also elsewhere on the board
REF_SDO: IC12.7 (SDO); also elsewhere on the board

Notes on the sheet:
Reference Signal

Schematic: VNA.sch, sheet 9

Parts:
C191, C192, C203, C204, C205, C206, C207, C208, C209, C210, C211: 100n; C0603
IC33: STM32L432KC; QFN50P500X500X100-33T345N
JP1: PINHD-1X6; 1X06
JTAG: ML10
R76, R88, R91: 22; R0603
R89: 1k5; R0603
R90, R92, R93, R94, R95, R111: 10k; R0603
U2: 6SLX9TQG144; TQ144
U4: W25Q16BVSN; SO08
X4: MINI-USB-SCHIELD-32005-301; 32005-301

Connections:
+3V3: C191.1, C192.1, C203.1, C204.1, C205.1, C206.1, C207.1, IC33.1 (VDD1), IC33.5 (VDDA/VREF+), IC33.17 (VDD2), JP1.1, JTAG.4, R90.2, R92.2, R93.2, R94.2, R95.2, U2.P20 (VCCAUX), U2.P36 (VCCAUX), U2.P42 (VCCO_2), U2.P53 (VCCAUX), U2.P63 (VCCO_2), U2.P69 (IO_L1N_M0_CMPMISO_2), U2.P90 (VCCAUX), U2.P129 (VCCAUX), U4.3 (!WP!), U4.7 (!HOLD!), U4.8 (VCC); also elsewhere on the board
FLACH_MOSI: U2.P64 (IO_L3N_MOSI_CSI_B_MISO0_2), U4.5 (DI)
FLASH_CLK: U2.P70 (IO_L1P_CCLK_2), U4.6 (CLK)
FLASH_CS: U2.P38 (IO_L65N_CSO_B_2), U4.1 (!CS!)
FLASH_MISO: R91.1, U4.2 (DO)
FPGA_RESET: IC33.7 (PA1/TIM2_CH2/SPI1_SCK), U2.P48 (IO_L48P_D7_2)
GND: C191.2, C192.2, C203.2, C204.2, C205.2, C206.2, C207.2, C208.2, C209.2, C210.2, C211.2, IC33.16 (VSS1), IC33.31 (BOOT0), IC33.32 (VSS2), IC33.33 (EP), JP1.3, JTAG.2, JTAG.10, R111.1, U2.P3 (GND), U2.P13 (GND), U2.P25 (GND), U2.P49 (GND), U2.P54 (GND), U2.P60 (IO_L13P_M1_2), U2.P68 (GND), U2.P73 (SUSPEND), U2.P77 (GND), U2.P91 (GND), U2.P96 (GND), U2.P108 (GND), U2.P113 (GND), U2.P130 (GND), U2.P136 (GND), U4.4 (GND), X4.5, X4.M1 (S1), X4.M2 (S2), X4.M3 (S3), X4.M4 (S4); also elsewhere on the board
MCU_AUX1: IC33.2 (PC14-OSC32_IN), U2.P55 (IO_L30N_GCLK0_USERCCLK_2)
MCU_AUX2: IC33.3 (PC15-OSC32_OUT), U2.P51 (IO_L31P_GCLK31_D14_2)
MCU_AUX3: IC33.6 (PA0/CK_IN/TIM2_CH1), U2.P50 (IO_L31N_GCLK30_D15_2)
MCU_INTR: IC33.30 (PB7/I2C1_SDA/USART1_RX), U2.P57 (IO_L14N_D12_2)
MCU_MISO: IC33.27 (PB4/I2C3_SDA/SPI1_MISO/SPI3_MISO), U2.P61 (IO_L12N_D2_MISO3_2)
MCU_MOSI: IC33.28 (PB5/SPI1_MOSI/SPI3_MOSI), U2.P59 (IO_L13N_D10_2)
MCU_NSS: IC33.29 (PB6/I2C1_SCL/USART1_TX), U2.P58 (IO_L14P_D11_2)
MCU_SCK: IC33.26 (PB3/TIM2_CH2/SPI1_SCK/SPI3_SCK), U2.P56 (IO_L30P_GCLK1_D13_2)
unnamed: JTAG.3, U2.P106 (TDO)
unnamed: JTAG.5, U2.P107 (TMS)
unnamed: JTAG.9, U2.P110 (TDI)
unnamed: JTAG.1, U2.P109 (TCK)
unnamed: R88.1, X4.2
unnamed: R76.2, R89.2, X4.3
unnamed: IC33.21 (PA11/TIM1_CH4/SPI1_MISO/CAN1_RX/USB_DM), R88.2
unnamed: IC33.22 (PA12/SPI1_MOSI/CAN1_TX/USB_DP), R76.1
unnamed: IC33.25 (PA15/TIM2_CH1/USART2_RX/SPI1_NSS/SPI3_N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), R89.1
unnamed: IC33.24 (PA14/SWCLK), JP1.2
unnamed: IC33.23 (PA13/SWDIO), JP1.4
unnamed: IC33.4 (NRST), JP1.5
unnamed: IC33.8 (PA2/TIM2_CH3/USART2_TX), JP1.6
unnamed: R92.1, U2.P71 (DONE_2)
unnamed: R93.1, U2.P39 (IO_L65P_INIT_B_2)
unnamed: R94.1, U2.P37 (PROGRAM_B_2)
unnamed: R91.2, U2.P65 (IO_L3P_D0_DIN_MISO_MISO1_2)
PORT2MIX_EN: R111.2, U2.P44 (IO_L62P_D5_2); also elsewhere on the board
PORT2_CONVSTART: U2.P47 (IO_L48N_RDWR_B_VREF_2); also elsewhere on the board
PORT2_SCLK: U2.P45 (IO_L49N_D4_2); also elsewhere on the board
PORT2_SDO: U2.P46 (IO_L49P_D3_2); also elsewhere on the board
REF_CONVSTART: U2.P43 (IO_L62N_D6_2); also elsewhere on the board
REF_SCLK: U2.P40 (IO_L64N_D9_2); also elsewhere on the board
REF_SDO: U2.P41 (IO_L64P_D8_2); also elsewhere on the board
SCL: IC33.19 (PA9/TIM1_CH2/I2C1_SCL/USART1_TX), R90.1; also elsewhere on the board
SDA: IC33.20 (PA10/TIM1_CH3/I2C1_SDA/USART1_RX), R95.1; also elsewhere on the board
SWITCHING_SYNC: U2.P62 (IO_L12P_D1_MISO2_2); also elsewhere on the board
VCCINT: C208.1, C209.1, C210.1, C211.1, U2.P19 (VCCINT), U2.P28 (VCCINT), U2.P52 (VCCINT), U2.P89 (VCCINT), U2.P128 (VCCINT); also elsewhere on the board

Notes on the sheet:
FPGA + MCU Connections
FPGA sets all pins as pullups while indirectly programming the flash. This disables the power supply through the switching_sync pin. As this behaviour is caused by the xc6slx9_spi.cor (and not changable with HSWAPEN), the only work-around is to cut the switching_sync connection while programming th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

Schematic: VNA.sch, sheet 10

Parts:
LED1, LED2, LED3, LED4, LED5, LED6, LED7, LED8, LED9: LEDCHIPLED_0603; CHIPLED_0603
R14, R26, R42, R105, R106, R107, R108, R109, R110: 330; R0603
R96: 22; R0603
R112, R113: 10k; R0603
U2: 6SLX9TQG144; TQ144

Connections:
+3V3: LED1.A, LED2.A, LED3.A, LED4.A, LED5.A, LED6.A, LED7.A, LED8.A, LED9.A, U2.P4 (VCCO_3), U2.P18 (VCCO_3), U2.P31 (VCCO_3), U2.P76 (VCCO_1), U2.P86 (VCCO_1), U2.P103 (VCCO_1), U2.P122 (VCCO_0), U2.P125 (VCCO_0), U2.P135 (VCCO_0); also elsewhere on the board
AMP_PWDN: U2.P24 (IO_L41P_GCLK27_3); also elsewhere on the board
ATT_D0: U2.P34 (IO_L1N_VREF_3); also elsewhere on the board
ATT_D1: U2.P33 (IO_L2P_3); also elsewhere on the board
ATT_D2: U2.P32 (IO_L2N_3); also elsewhere on the board
ATT_D3: U2.P30 (IO_L36P_3); also elsewhere on the board
ATT_D4: U2.P29 (IO_L36N_3); also elsewhere on the board
ATT_D5: U2.P27 (IO_L37P_3); also elsewhere on the board
ATT_D6: U2.P26 (IO_L37N_3); also elsewhere on the board
BAND_SELECT: U2.P22 (IO_L42P_GCLK25_TRDY2_3); also elsewhere on the board
FILT_IN_C1: U2.P15 (IO_L44P_GCLK21_3); also elsewhere on the board
FILT_IN_C2: U2.P16 (IO_L43N_GCLK22_IRDY2_3); also elsewhere on the board
FILT_OUT_C1: U2.P21 (IO_L42N_GCLK24_3); also elsewhere on the board
FILT_OUT_C2: U2.P17 (IO_L43P_GCLK23_3); also elsewhere on the board
FPGA_CLK: R96.1; also elsewhere on the board
GND: R110.2, R112.1, R113.1; also elsewhere on the board
LO1_CE: U2.P138 (IO_L4P_0); also elsewhere on the board
LO1_CLK: U2.P141 (IO_L2N_0); also elsewhere on the board
LO1_LD: U2.P142 (IO_L2P_0); also elsewhere on the board
LO1_LE: U2.P139 (IO_L3N_0); also elsewhere on the board
LO1_MOSI: U2.P140 (IO_L3P_0); also elsewhere on the board
LO1_MUX: U2.P144 (IO_L1P_HSWAPEN_0); also elsewhere on the board
LO1_RF_EN: U2.P143 (IO_L1N_VREF_0); also elsewhere on the board
unnamed: R96.2, U2.P14 (IO_L44N_GCLK20_3)
unnamed: LED9.C, R14.1
unnamed: LED8.C, R26.1
unnamed: LED7.C, R42.1
unnamed: LED6.C, R105.1
unnamed: LED5.C, R106.1
unnamed: LED4.C, R107.1
unnamed: LED3.C, R108.1
unnamed: LED2.C, R109.1
unnamed: LED1.C, R110.1
unnamed: R14.2, U2.P105 (IO_L1P_1)
unnamed: R26.2, U2.P104 (IO_L1N_VREF_1)
unnamed: R42.2, U2.P99 (IO_L33N_1)
unnamed: R105.2, U2.P94 (IO_L40N_GCLK10_1)
unnamed: R106.2, U2.P85 (IO_L43P_GCLK5_1)
unnamed: R107.2, U2.P82 (IO_L45N_1)
unnamed: R108.2, U2.P75 (IO_L74P_AWAKE_1)
unnamed: R109.2, U2.P118 (IO_L63N_SCP6_0)
PORT1MIX_EN: R112.2, U2.P137 (IO_L4N_0); also elsewhere on the board
PORT1_CONVSTART: U2.P134 (IO_L34P_GCLK19_0); also elsewhere on the board
PORT1_SCLK: U2.P132 (IO_L35P_GCLK17_0); also elsewhere on the board
PORT1_SDO: U2.P133 (IO_L34N_GCLK18_0); also elsewhere on the board
PORT_SELECT: U2.P23 (IO_L41N_GCLK26_3); also elsewhere on the board
REFMIX_EN: R113.2, U2.P35 (IO_L1P_3); also elsewhere on the board
SCL: U2.P6 (IO_L52P_3); also elsewhere on the board
SDA: U2.P9 (IO_L50N_3); also elsewhere on the board
SOURCE_CE: U2.P1 (IO_L83N_VREF_3); also elsewhere on the board
SOURCE_CLK: U2.P7 (IO_L51N_3); also elsewhere on the board
SOURCE_LD: U2.P10 (IO_L50P_3); also elsewhere on the board
SOURCE_LE: U2.P2 (IO_L83P_3); also elsewhere on the board
SOURCE_MOSI: U2.P5 (IO_L52N_3); also elsewhere on the board
SOURCE_MUX: U2.P8 (IO_L51P_3); also elsewhere on the board
SOURCE_RF_EN: U2.P11 (IO_L49N_3); also elsewhere on the board

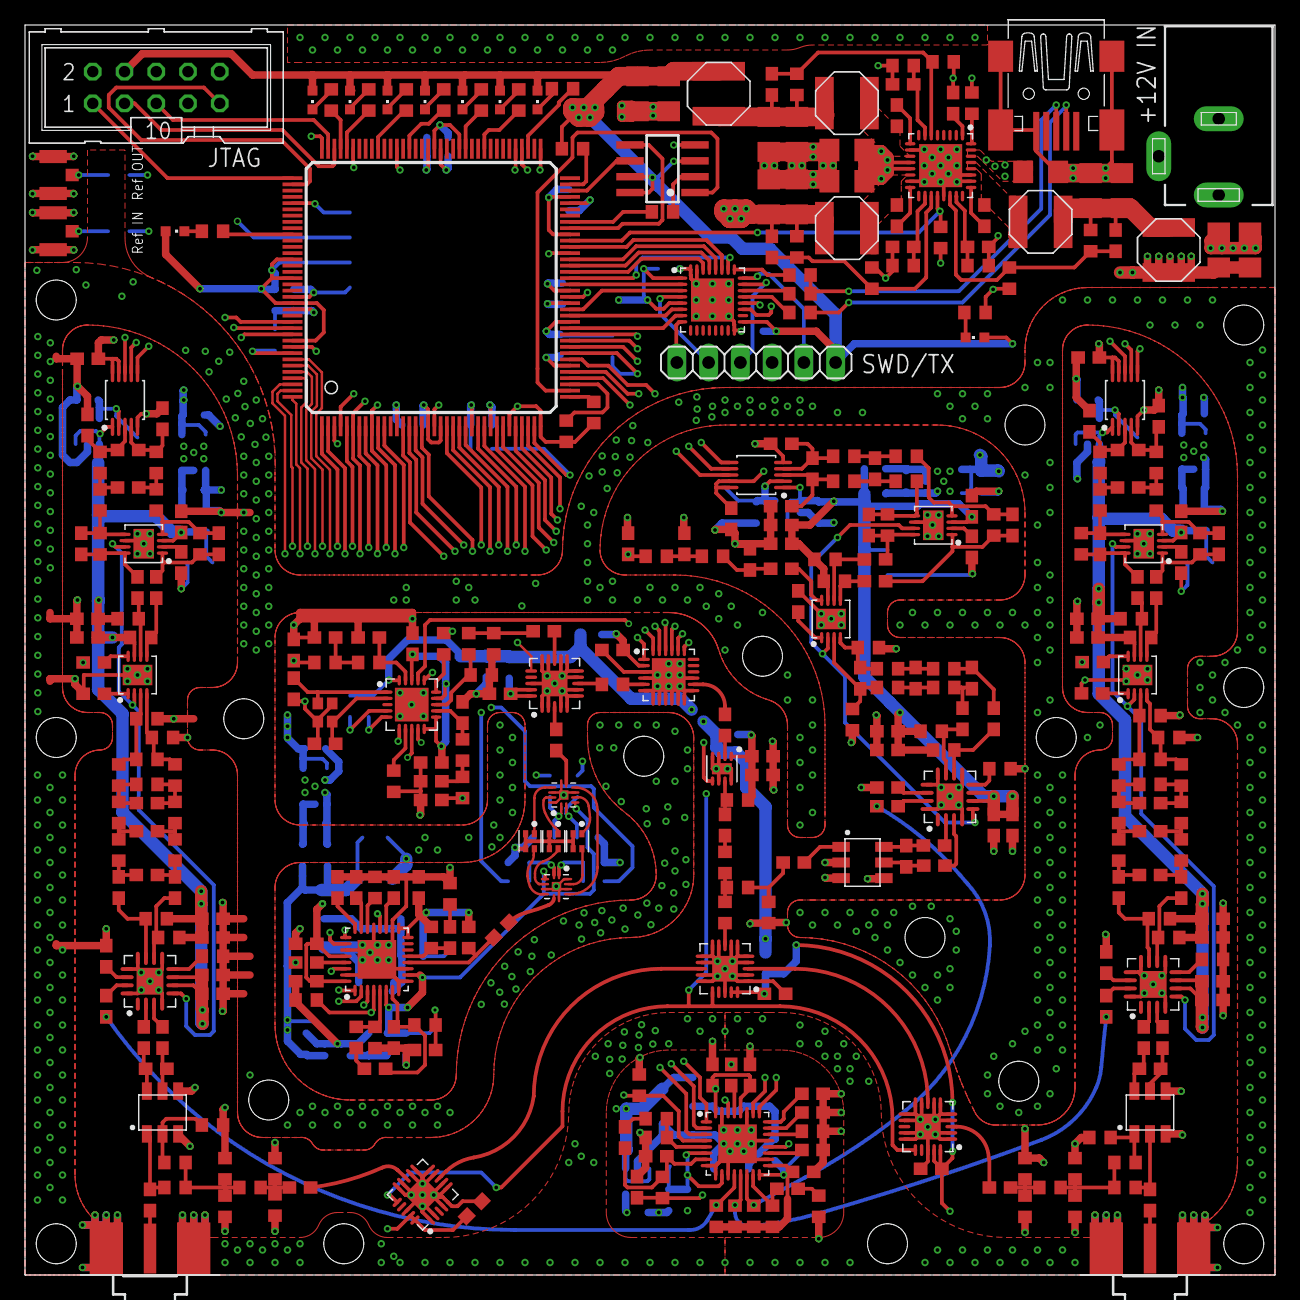
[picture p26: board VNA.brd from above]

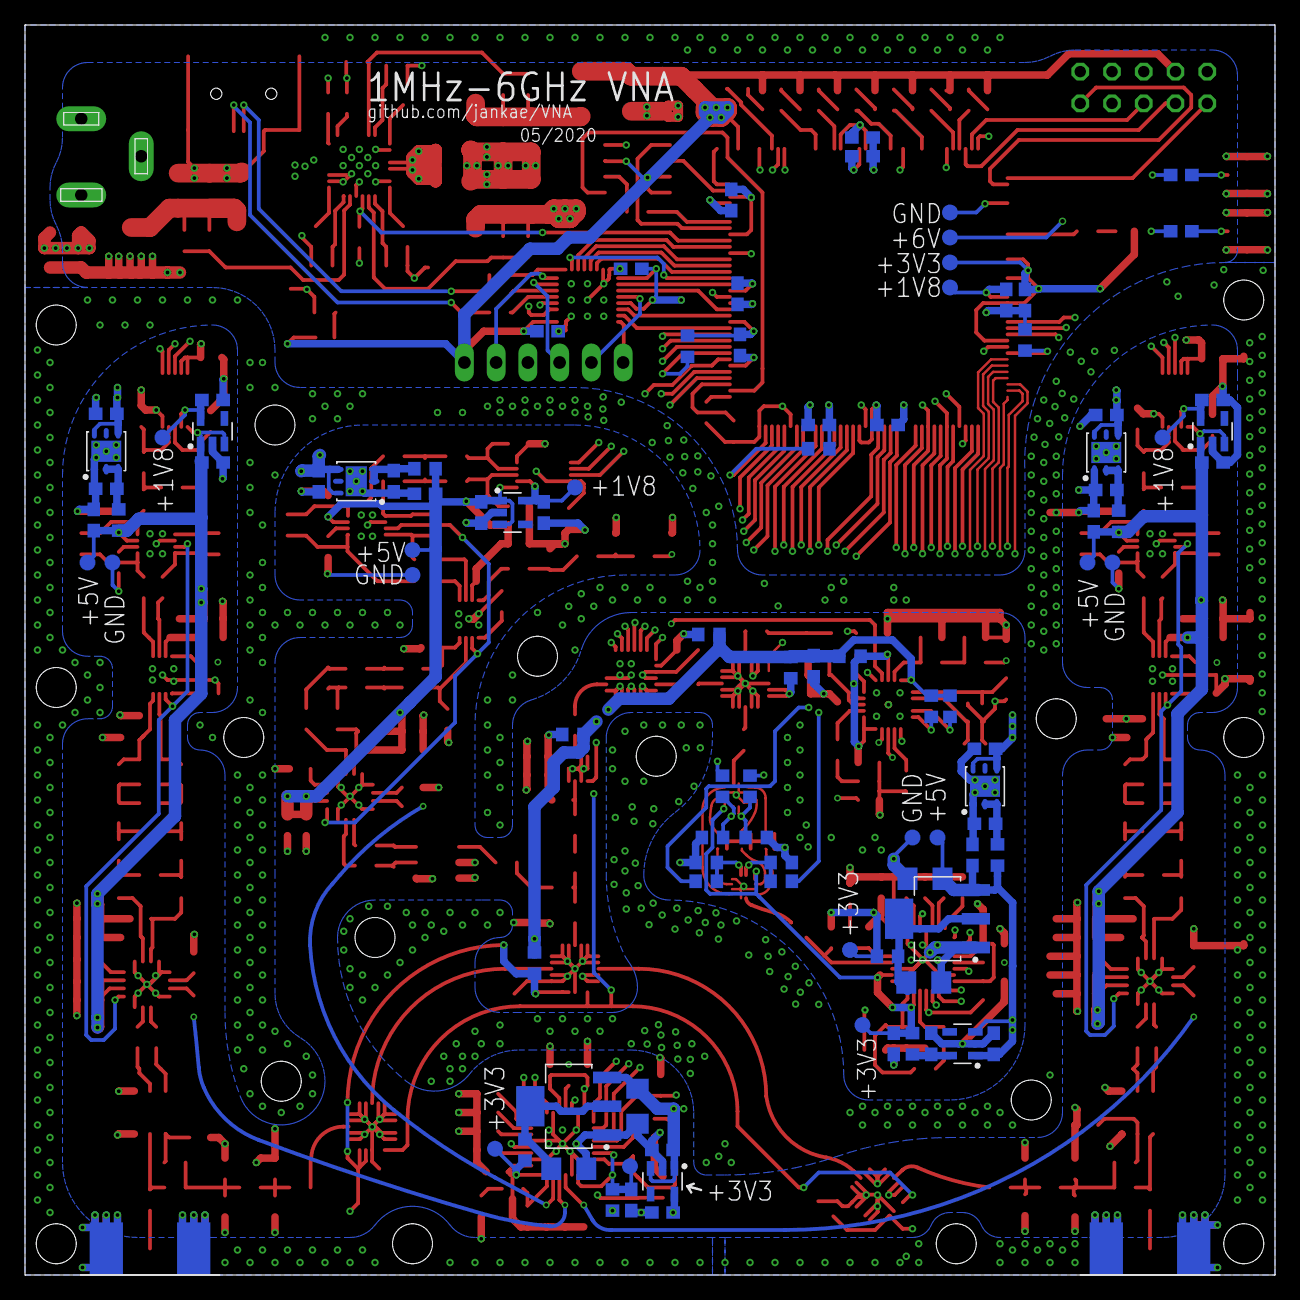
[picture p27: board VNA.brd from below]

Board: 4 copper layers, 100.0 x 100.0 mm, 453 parts (98 on the bottom side), 310 nets.

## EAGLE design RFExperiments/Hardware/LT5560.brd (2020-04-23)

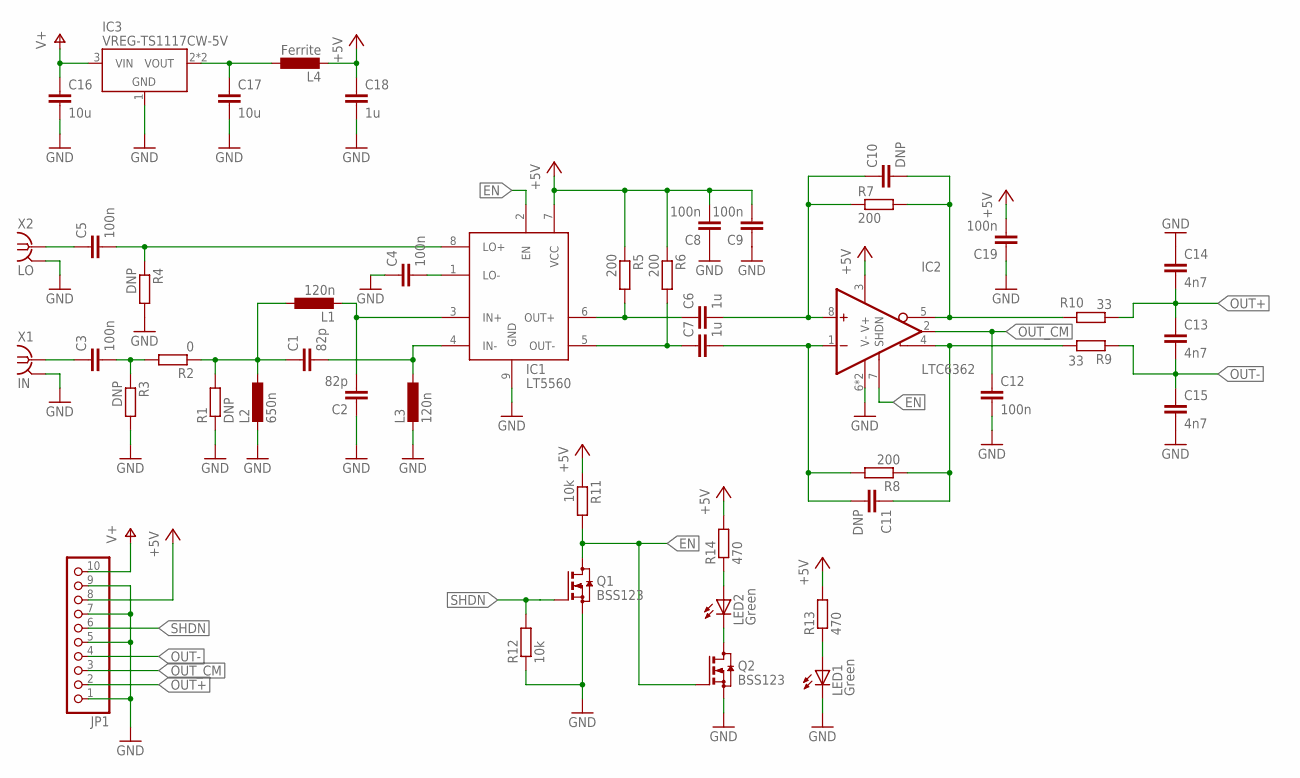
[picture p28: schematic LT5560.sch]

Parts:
C1, C2: 82p; C0603
C3, C4, C5, C8, C9, C12, C19: 100n; C0603
C6, C7, C18: 1u; C0603
C10, C11: DNP; C0603
C13, C14, C15: 4n7; C0603
C16, C17: 10u; C1206
IC1: LT5560; SON50P300X300X80-9T165X238
IC2: LTC6362; SON50P300X300X80-9T165X238
IC3: VREG-TS1117CW-5V; SOT223
JP1: PINHD-1X10/90; 1X10/90
L1, L3: 120n; R0603
L2: 650n; R0603
L4: Ferrite; R0603
LED1, LED2: Green; LED_SML0603
Q1, Q2: BSS123; SOT23
R1, R3, R4: DNP; R0603
R2: 0; R0603
R5, R6, R7, R8: 200; R0603
R9, R10: 33; R0603
R11, R12: 10k; R0603
R13, R14: 470; R0603
X1: IN; J502-ND-142-0711-821/826
X2: LO; J502-ND-142-0711-821/826

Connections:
+5V: C8.2, C9.2, C18.1, C19.2, IC1.7 (VCC), IC2.3 (V+), JP1.8, L4.2, R5.1, R6.1, R11.1, R13.2, R14.2
EN: IC1.2 (EN), IC2.7 (SHDN), Q1.3 (D), Q2.1 (G), R11.2
GND: C2.1, C4.1, C8.1, C9.1, C12.2, C14.1, C15.2, C16.2, C17.2, C18.2, C19.1, IC1.9 (GND), IC2.6 (V-), IC2.9 (V-), IC3.1 (GND), JP1.1, JP1.5, JP1.7, JP1.9, L2.2, L3.2, LED1.C, Q1.2 (S), Q2.2 (S), R1.1, R3.2, R4.2, R12.1, X1.G@1 (2), X1.G@2 (2), X1.G@3 (2), X1.G@4 (2), X2.G@1 (2), X2.G@2 (2), X2.G@3 (2), X2.G@4 (2)
GND1: LED2.C, Q2.3 (D)
unnamed: C1.2, IC1.4 (IN-), L3.1
unnamed: C2.2, IC1.3 (IN+), L1.2
unnamed: C1.1, L1.1, L2.1, R1.2, R2.1
unnamed: C3.1, X1.1
unnamed: C3.2, R2.2, R3.1
unnamed: C4.2, IC1.1 (LO-)
unnamed: C5.2, IC1.8 (LO+), R4.1
unnamed: C5.1, X2.1
unnamed: C11.1, IC2.4 (+OUT), R8.1, R9.2
unnamed: C6.1, IC1.6 (OUT+), R5.2
unnamed: C7.1, IC1.5 (OUT-), R6.2
unnamed: C6.2, C10.1, IC2.8 (+IN), R7.1
unnamed: C7.2, C11.2, IC2.1 (-IN), R8.2
unnamed: C10.2, IC2.5 (-OUT), R7.2, R10.2
unnamed: C17.1, IC3.2 (VOUT), IC3.4 (VOUT), L4.1
unnamed: LED2.A, R14.1
unnamed: LED1.A, R13.1
OUT+: C13.1, C14.2, JP1.2, R10.1
OUT-: C13.2, C15.1, JP1.4, R9.1
OUT_CM: C12.1, IC2.2 (VOCM), JP1.3
SHDN: JP1.6, Q1.1 (G), R12.2
V+: C16.1, IC3.3 (VIN), JP1.10

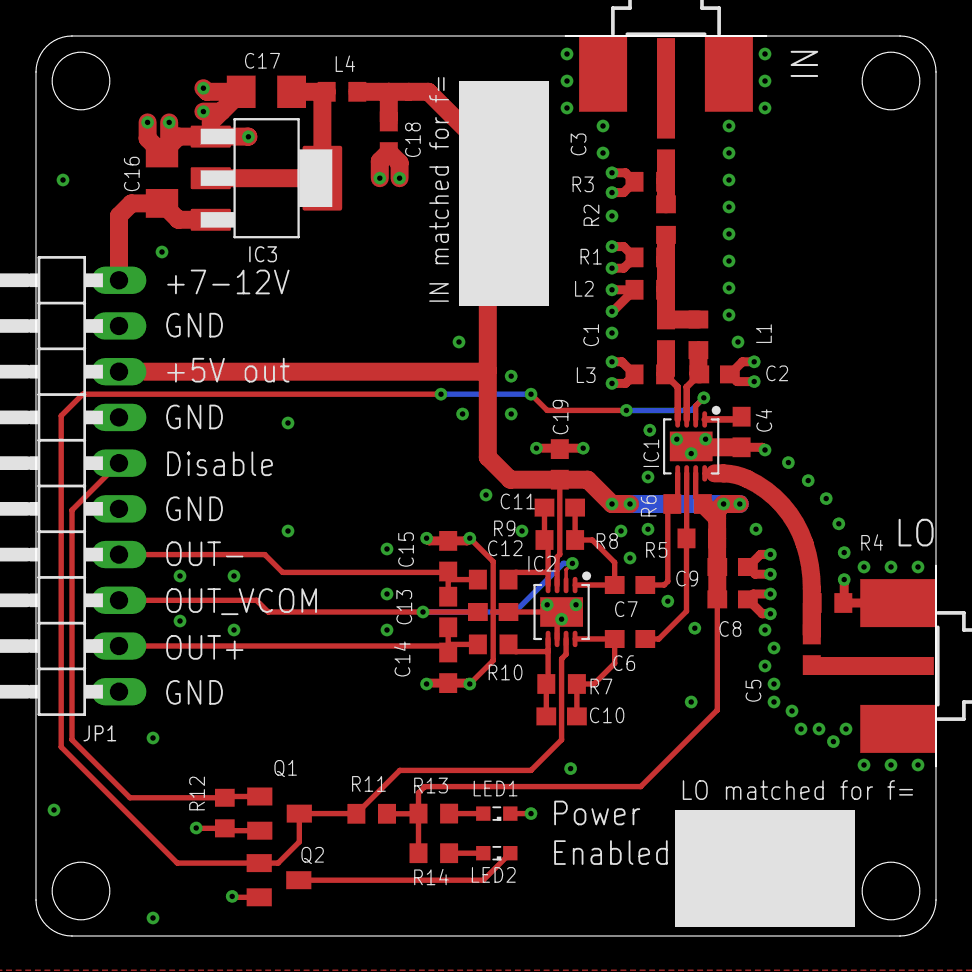
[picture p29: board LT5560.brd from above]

Board: 2 copper layers, 50.0 x 50.0 mm, 47 parts (0 on the bottom side), 26 nets.

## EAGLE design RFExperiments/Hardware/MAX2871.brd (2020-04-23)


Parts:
C1, C2, C3, C8, C9, C10, C11: 1u; C0603
C4: 180p; C0603
C5: 18p; C0603
C6: 3n3; C0603
C7, C14, C15, C18, C19: 100n; C0603
C12, C13: 10u; C1206
C17, C20, C21, C22: 10n; C0603
IC1: AP2114H; SOT230P700X180-4
IC2: MAX2871; QFN50P500X500X80-33T310
IC4, IC5: NCP702-3.3; SOT95P240X110-5
JP1: PINHD-1X10/90; 1X10/90
L1, L2: Ferrite; R0603
LED1, LED3: Green; LED_SML0603
LED2: Red; LED_SML0603
R1: 1k8; R0603
R2: 82; R0603
R3: 330; R0603
R4: 5k1; R0603
R5, R6, R7, R8, R12: 49R9; R0603
R9, R10: 220; R0603
R11: 470; R0603
R16: 10k; R0603
X1, X2, X3, X4, X5: SMA_CONNECTOR; J502-ND-142-0711-821/826

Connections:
10MHZ_REF: C19.1, X5.1
+3V3: C7.1, C8.1, C14.1, IC2.28 (VCC_DIG), IC2.32 (VDD_SD), IC5.5 (VOUT), R10.2
+5V: C9.1, C10.1, C12.1, IC1.3 (VIN), IC4.1 (VIN), IC4.3 (EN), IC5.1 (VIN), IC5.3 (EN), JP1.10, R11.2
GND: C1.2, C2.2, C3.2, C4.2, C5.1, C7.2, C8.2, C9.2, C10.2, C11.2, C12.2, C13.2, C14.2, C15.2, C18.2, IC1.1 (GND), IC2.8 (GND_CP), IC2.9 (GND_PLL), IC2.11 (GND_RF), IC2.18 (GND_VCO), IC2.21 (GND_TUNE), IC2.27 (GND_DIG), IC2.31 (GND_SD), IC2.33 (EP), IC4.2 (GND), IC5.2 (GND), JP1.1, JP1.2, LED3.C, R3.2, R4.1, R9.1, R12.1, R16.1, X1.G@1 (2), X1.G@2 (2), X1.G@3 (2), X1.G@4 (2), X2.G@1 (2), X2.G@2 (2), X2.G@3 (2), X2.G@4 (2), X3.G@1 (2), X3.G@2 (2), X3.G@3 (2), X3.G@4 (2), X4.G@1 (2), X4.G@2 (2), X4.G@3 (2), X4.G@4 (2), X5.G@1 (2), X5.G@2 (2), X5.G@3 (2), X5.G@4 (2)
unnamed: C5.2, IC2.20 (TUNE), R1.2
unnamed: C4.1, C6.1, IC2.7 (CP_OUT), R1.1
unnamed: C1.1, IC2.24 (REG)
unnamed: C2.1, IC2.19 (NOISE_FILT)
unnamed: C3.1, IC2.23 (BIAS_FILT)
unnamed: C6.2, R2.1
unnamed: IC2.5 (SW), R2.2, R3.1
unnamed: IC2.22 (RSET), R4.2
unnamed: C19.2, IC2.29 (REF_IN), R12.2
unnamed: C18.1, IC2.16 (VCC_RF), IC2.17 (VCC_VCO), L1.2, R5.2, R6.2, R7.2, R8.2
unnamed: C15.1, IC2.6 (VCC_CP), IC2.10 (VCC_PLL), L2.2
unnamed: C22.2, IC2.15 (RFOUTB_N), R6.1
unnamed: LED3.A, R11.1
unnamed: C21.1, IC2.12 (RFOUTA_P), R8.1
unnamed: C20.2, IC2.13 (RFOUTA_N), R7.1
unnamed: C17.1, IC2.14 (RFOUTB_P), R5.1
unnamed: C21.2, X1.1
unnamed: C20.1, X2.1
unnamed: C17.2, X3.1
unnamed: C22.1, X4.1
unnamed: LED1.C, R9.2
unnamed: LED2.A, R10.1
unnamed: C13.1, IC1.2 (VOUT), IC1.4 (VOUT), L1.1
unnamed: C11.1, IC4.5 (VOUT), L2.1
SPI_CLK: IC2.1 (CLK), JP1.4
SPI_MOSI: IC2.2 (DATA), JP1.5
SYNTH_CE: IC2.4 (CE), JP1.3, R16.2
SYNTH_LE: IC2.3 (LE), JP1.6
SYNTH_LOCK_DETECT: IC2.25 (LD), JP1.8, LED1.A, LED2.C
SYNTH_MUX: IC2.30 (MUX), JP1.9
SYNTH_RF_EN: IC2.26 (RFOUT_EN), JP1.7

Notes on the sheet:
up to 200mA current consumption
All I/O using 3V3 levels
3x 3V3
Approx. 450kHz loop bandwidth


Board: 4 copper layers, 50.0 x 50.0 mm, 49 parts (0 on the bottom side), 35 nets.

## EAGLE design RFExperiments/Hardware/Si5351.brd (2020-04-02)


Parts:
C1, C2, C3, C4, C5, C6, C7, C8, C13: C-EUC0603; C0603
C9, C10, C11, C12: 100n; C0603
C14, C15: 4p; C0603
C16, C17, C18: 1u; C0603
IC1: SI5351C; QFN50P400X400X90-21T270N
IC4: NCP702-3.3; SOT95P240X110-5
JP1: PINHD-1X6/90; 1X06/90
L1: Ferrite; R0603
Q1: FA-128 26MHz; FA-128
R1, R2, R3, R4: 10k; R0603
X1: CLK0; J502-ND-142-0711-821/826
X2: CLK1; J502-ND-142-0711-821/826
X3: CLK2; J502-ND-142-0711-821/826
X4: CLK3; J502-ND-142-0711-821/826
X5: CLK4; J502-ND-142-0711-821/826
X6: CLK5; J502-ND-142-0711-821/826
X7: CLK6; J502-ND-142-0711-821/826
X8: CLK7; J502-ND-142-0711-821/826
X9: REF IN; J502-ND-142-0711-821/826

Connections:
+3V3: C9.2, C10.2, C11.2, C12.2, C18.1, IC1.10 (VDDOB), IC1.11 (VDDOA), IC1.14 (VDDOD), IC1.18 (VDDOC), IC1.20 (VDD), L1.2, R2.2, R3.2, R4.2
+5V: C16.1, IC4.1 (VIN), IC4.3 (EN), JP1.6
GND: C9.1, C10.1, C11.1, C12.1, C14.1, C15.1, C16.2, C17.2, C18.2, IC1.21 (GND), IC4.2 (GND), JP1.1, Q1.2, Q1.4, R1.1, X1.G@1 (2), X1.G@2 (2), X1.G@3 (2), X1.G@4 (2), X2.G@1 (2), X2.G@2 (2), X2.G@3 (2), X2.G@4 (2), X3.G@1 (2), X3.G@2 (2), X3.G@3 (2), X3.G@4 (2), X4.G@1 (2), X4.G@2 (2), X4.G@3 (2), X4.G@4 (2), X5.G@1 (2), X5.G@2 (2), X5.G@3 (2), X5.G@4 (2), X6.G@1 (2), X6.G@2 (2), X6.G@3 (2), X6.G@4 (2), X7.G@1 (2), X7.G@2 (2), X7.G@3 (2), X7.G@4 (2), X8.G@1 (2), X8.G@2 (2), X8.G@3 (2), X8.G@4 (2), X9.G@1 (2), X9.G@2 (2), X9.G@3 (2), X9.G@4 (2)
unnamed: C1.2, X1.1
unnamed: C2.2, X2.1
unnamed: C3.2, X3.1
unnamed: C4.2, X4.1
unnamed: C5.2, X5.1
unnamed: C6.2, X6.1
unnamed: C7.2, X7.1
unnamed: C8.2, X8.1
unnamed: C1.1, IC1.13 (CLK0)
unnamed: C2.1, IC1.12 (CLK1)
unnamed: C3.1, IC1.9 (CLK2)
unnamed: C8.1, IC1.15 (CLK7)
unnamed: C7.1, IC1.16 (CLK6)
unnamed: C6.1, IC1.17 (CLK5)
unnamed: C5.1, IC1.19 (CLK4)
unnamed: C4.1, IC1.8 (CLK3)
unnamed: IC1.4 (SCL), JP1.5, R3.1
unnamed: C13.1, X9.1
unnamed: C13.2, IC1.6 (CLKIN)
unnamed: IC1.5 (SDA), JP1.4, R4.1
unnamed: IC1.3 (INTR), JP1.3, R2.1
unnamed: IC1.7 (OEB), JP1.2, R1.2
unnamed: C15.2, IC1.1 (XA), Q1.3
unnamed: C14.2, IC1.2 (XB), Q1.1
unnamed: C17.1, IC4.5 (VOUT), L1.1


Board: 2 copper layers, 50.0 x 50.0 mm, 36 parts (0 on the bottom side), 28 nets.

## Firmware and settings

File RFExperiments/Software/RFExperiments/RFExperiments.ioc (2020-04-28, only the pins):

Mcu.UserName=STM32F746ZGTx
PA0/WKUP.Signal=ADCx_IN0
PA1.GPIO_Label=RMII_REF_CLK [LAN8742A-CZ-TR_REFCLK0]
PA1.Signal=ETH_REF_CLK
PA10.GPIO_Label=USB_ID
PA10.Signal=USB_OTG_FS_ID
PA11.GPIO_Label=USB_DM
PA11.Signal=USB_OTG_FS_DM
PA12.GPIO_Label=USB_DP
PA12.Signal=USB_OTG_FS_DP
PA13.GPIO_Label=TMS
PA13.Signal=SYS_JTMS-SWDIO
PA14.GPIO_Label=TCK
PA14.Signal=SYS_JTCK-SWCLK
PA15.GPIO_Label=TRACE
PA15.Signal=GPIO_Output
PA2.GPIO_Label=RMII_MDIO [LAN8742A-CZ-TR_MDIO]
PA2.Signal=ETH_MDIO
PA3.Signal=ADCx_IN3
PA7.GPIO_Label=RMII_CRS_DV [LAN8742A-CZ-TR_CRS_DV]
PA7.Signal=ETH_CRS_DV
PA8.GPIO_Label=USB_SOF [TP1]
PA8.Signal=USB_OTG_FS_SOF
PA9.GPIO_Label=USB_VBUS
PA9.Signal=USB_OTG_FS_VBUS
PB0.GPIO_Label=LD1 [Green]
PB0.Signal=GPIO_Output
PB13.GPIO_Label=RMII_TXD1 [LAN8742A-CZ-TR_TXD1]
PB13.Signal=ETH_TXD1
PB14.GPIO_Label=LD3 [Red]
PB14.Signal=GPIO_Output
PB3.Signal=SPI1_SCK
PB4.Signal=SPI1_MISO
PB5.Signal=SPI1_MOSI
PB7.GPIO_Label=LD2 [Blue]
PB7.Signal=GPIO_Output
PB8.Signal=I2C1_SCL
PB9.Signal=I2C1_SDA
PC1.GPIO_Label=RMII_MDC [LAN8742A-CZ-TR_MDC]
PC1.Signal=ETH_MDC
PC10.Signal=SPI3_SCK
PC11.Signal=SPI3_MISO
PC12.Signal=SPI3_MOSI
PC13.GPIO_Label=USER_Btn [B1]
PC13.Signal=GPXTI13
PC14/OSC32_IN.Signal=RCC_OSC32_IN
PC15/OSC32_OUT.Signal=RCC_OSC32_OUT
PC3.Signal=ADCx_IN13
PC4.GPIO_Label=RMII_RXD0 [LAN8742A-CZ-TR_RXD0]
PC4.Signal=ETH_RXD0
PC5.GPIO_Label=RMII_RXD1 [LAN8742A-CZ-TR_RXD1]
PC5.Signal=ETH_RXD1
PD2.GPIO_Label=TX_SWITCH
PD2.Signal=GPIO_Output
PD8.GPIO_Label=STLK_RX [STM32F103CBT6_PA3]
PD8.Signal=USART3_TX
PD9.GPIO_Label=STLK_TX [STM32F103CBT6_PA2]
PD9.Signal=USART3_RX
PE0.Signal=S_TIM4_ETR
PE10.GPIO_Label=PLL2_CE
PE10.Signal=GPIO_Output
PE11.GPIO_Label=PLL2_LE
PE11.Signal=GPIO_Output
PE12.GPIO_Label=PLL2_RF
PE12.Signal=GPIO_Output
PE13.GPIO_Label=PLL1_LD
PE13.Signal=GPIO_Input
PE14.GPIO_Label=PLL2_LD
PE14.Signal=GPIO_Input
PE7.GPIO_Label=PLL1_CE
PE7.Signal=GPIO_Output
PE8.GPIO_Label=PLL1_LE
PE8.Signal=GPIO_Output
PE9.GPIO_Label=PLL1_RF
PE9.Signal=GPIO_Output
PF7.GPIO_Label=TRACE2
PF7.Signal=GPIO_Output
PG11.GPIO_Label=RMII_TX_EN [LAN8742A-CZ-TR_TXEN]
PG11.Signal=ETH_TX_EN
PG13.GPIO_Label=RMII_TXD0 [LAN8742A-CZ-TR_TXD0]
PG13.Signal=ETH_TXD0
PG6.GPIO_Label=USB_PowerSwitchOn [STMPS2151STR_EN]
PG6.Signal=GPIO_Output
PG7.GPIO_Label=USB_OverCurrent [STMPS2151STR_FAULT]
PG7.Signal=GPIO_Input
PH0/OSC_IN.GPIO_Label=MCO [STM32F103CBT6_PA8]
PH0/OSC_IN.Signal=RCC_OSC_IN
PH1/OSC_OUT.Signal=RCC_OSC_OUT

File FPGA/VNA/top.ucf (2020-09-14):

CONFIG VCCAUX  = 3.3;
NET "CLK" PERIOD = 62.5 ns;


NET "ATTENUATION[6]" IOSTANDARD = LVCMOS33;
NET "ATTENUATION[5]" IOSTANDARD = LVCMOS33;
NET "ATTENUATION[4]" IOSTANDARD = LVCMOS33;
NET "ATTENUATION[3]" IOSTANDARD = LVCMOS33;
NET "ATTENUATION[2]" IOSTANDARD = LVCMOS33;
NET "ATTENUATION[1]" IOSTANDARD = LVCMOS33;
NET "ATTENUATION[0]" IOSTANDARD = LVCMOS33;


NET "ATTENUATION[6]" LOC = P26;
NET "ATTENUATION[5]" LOC = P27;
NET "ATTENUATION[4]" LOC = P29;
NET "ATTENUATION[3]" LOC = P30;
NET "ATTENUATION[2]" LOC = P32;
NET "ATTENUATION[1]" LOC = P33;
NET "ATTENUATION[0]" LOC = P34;


NET "LEDS[7]" IOSTANDARD = LVCMOS33;
NET "LEDS[6]" IOSTANDARD = LVCMOS33;
NET "LEDS[5]" IOSTANDARD = LVCMOS33;
NET "LEDS[4]" IOSTANDARD = LVCMOS33;
NET "LEDS[3]" IOSTANDARD = LVCMOS33;
NET "LEDS[2]" IOSTANDARD = LVCMOS33;
NET "LEDS[1]" IOSTANDARD = LVCMOS33;
NET "LEDS[0]" IOSTANDARD = LVCMOS33;


NET "LEDS[7]" LOC = P105;
NET "LEDS[6]" LOC = P104;
NET "LEDS[5]" LOC = P99;
NET "LEDS[4]" LOC = P94;
NET "LEDS[3]" LOC = P85;
NET "LEDS[2]" LOC = P82;
NET "LEDS[1]" LOC = P75;
NET "LEDS[0]" LOC = P118;


NET "AMP_PWDN" IOSTANDARD = LVCMOS33;
NET "BAND_SELECT" IOSTANDARD = LVCMOS33;
NET "CLK" IOSTANDARD = LVCMOS33;
NET "FILT_IN_C2" IOSTANDARD = LVCMOS33;
NET "FILT_IN_C1" IOSTANDARD = LVCMOS33;
NET "FILT_OUT_C2" IOSTANDARD = LVCMOS33;
NET "FILT_OUT_C1" IOSTANDARD = LVCMOS33;
NET "LO1_CE" IOSTANDARD = LVCMOS33;
NET "LO1_LD" IOSTANDARD = LVCMOS33;
NET "LO1_LE" IOSTANDARD = LVCMOS33;
NET "LO1_CLK" IOSTANDARD = LVCMOS33;
NET "LO1_MOSI" IOSTANDARD = LVCMOS33;
NET "LO1_MUX" IOSTANDARD = LVCMOS33;
NET "MCU_AUX1" IOSTANDARD = LVCMOS33;
NET "LO1_RF_EN" IOSTANDARD = LVCMOS33;
NET "SOURCE_RF_EN" IOSTANDARD = LVCMOS33;
NET "SOURCE_MUX" IOSTANDARD = LVCMOS33;
NET "SOURCE_LE" IOSTANDARD = LVCMOS33;
NET "SOURCE_MOSI" IOSTANDARD = LVCMOS33;
NET "SOURCE_LD" IOSTANDARD = LVCMOS33;
NET "SOURCE_CLK" IOSTANDARD = LVCMOS33;
NET "SOURCE_CE" IOSTANDARD = LVCMOS33;
NET "SDA" IOSTANDARD = LVCMOS33;
NET "SCL" IOSTANDARD = LVCMOS33;
NET "RESET" IOSTANDARD = LVCMOS33;
NET "REF_SDO" IOSTANDARD = LVCMOS33;
NET "REF_SCLK" IOSTANDARD = LVCMOS33;
NET "REF_MIX_EN" IOSTANDARD = LVCMOS33;
NET "PORT_SELECT" IOSTANDARD = LVCMOS33;
NET "REF_CONVSTART" IOSTANDARD = LVCMOS33;
NET "PORT2_SDO" IOSTANDARD = LVCMOS33;
NET "PORT2_SCLK" IOSTANDARD = LVCMOS33;
NET "PORT2_CONVSTART" IOSTANDARD = LVCMOS33;
NET "PORT2_MIX_EN" IOSTANDARD = LVCMOS33;
NET "PORT1_SDO" IOSTANDARD = LVCMOS33;
NET "PORT1_SCLK" IOSTANDARD = LVCMOS33;
NET "PORT1_MIX_EN" IOSTANDARD = LVCMOS33;
NET "PORT1_CONVSTART" IOSTANDARD = LVCMOS33;
NET "MCU_SCK" IOSTANDARD = LVCMOS33;
NET "MCU_NSS" IOSTANDARD = LVCMOS33;
NET "MCU_MISO" IOSTANDARD = LVCMOS33;
NET "MCU_MOSI" IOSTANDARD = LVCMOS33;
NET "MCU_INTR" IOSTANDARD = LVCMOS33;
NET "MCU_AUX2" IOSTANDARD = LVCMOS33;
NET "MCU_AUX3" IOSTANDARD = LVCMOS33;


NET "AMP_PWDN" LOC = P24;
NET "BAND_SELECT" LOC = P22;
NET "CLK" LOC = P14;
NET "FILT_IN_C1" LOC = P15;
NET "FILT_IN_C2" LOC = P16;
NET "FILT_OUT_C1" LOC = P21;
NET "FILT_OUT_C2" LOC = P17;
NET "LO1_CE" LOC = P138;
NET "LO1_CLK" LOC = P141;
NET "LO1_LD" LOC = P142;
NET "LO1_LE" LOC = P139;
NET "LO1_MOSI" LOC = P140;
NET "LO1_MUX" LOC = P144;
NET "LO1_RF_EN" LOC = P143;
NET "MCU_AUX1" LOC = P55;
NET "MCU_AUX2" LOC = P51;
NET "MCU_AUX3" LOC = P50;
NET "MCU_INTR" LOC = P57;
NET "MCU_MISO" LOC = P61;
NET "MCU_MOSI" LOC = P59;
NET "MCU_NSS" LOC = P58;
NET "MCU_SCK" LOC = P56;
NET "PORT1_CONVSTART" LOC = P134;
NET "PORT1_MIX_EN" LOC = P137;
NET "PORT1_SCLK" LOC = P132;
NET "PORT1_SDO" LOC = P133;
NET "PORT_SELECT" LOC = P23;
NET "PORT2_CONVSTART" LOC = P47;
NET "PORT2_MIX_EN" LOC = P44;
NET "PORT2_SCLK" LOC = P45;
NET "PORT2_SDO" LOC = P46;
NET "REF_CONVSTART" LOC = P43;
NET "REF_SCLK" LOC = P40;
NET "REF_SDO" LOC = P41;
NET "REF_MIX_EN" LOC = P35;
NET "RESET" LOC = P48;
NET "SCL" LOC = P6;
NET "SDA" LOC = P9;
NET "SOURCE_CE" LOC = P1;
NET "SOURCE_CLK" LOC = P7;
NET "SOURCE_LD" LOC = P10;
NET "SOURCE_LE" LOC = P2;
NET "SOURCE_MOSI" LOC = P5;
NET "SOURCE_MUX" LOC = P8;
NET "SOURCE_RF_EN" LOC = P11;

# PlanAhead Generated IO constraints 

NET "PORT1_SCLK" SLEW = FAST;
NET "PORT2_SCLK" SLEW = FAST;
NET "REF_SCLK" SLEW = FAST;

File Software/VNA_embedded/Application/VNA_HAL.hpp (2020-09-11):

#pragma once

#include "stm.hpp"
#include "Si5351C.hpp"
#include "max2871.hpp"
#include "main.h"

extern I2C_HandleTypeDef hi2c1;
extern SPI_HandleTypeDef hspi3;

namespace VNAHAL {

static Si5351C Si5351 = Si5351C(&hi2c1, 26000000);
static MAX2871 Source = MAX2871(&hspi3, FPGA_CS_GPIO_Port, FPGA_CS_Pin, nullptr, 0, nullptr, 0, nullptr, 0, GPIOB, GPIO_PIN_4);
static MAX2871 LO1 = MAX2871(&hspi3, FPGA_CS_GPIO_Port, FPGA_CS_Pin, nullptr, 0, nullptr, 0, nullptr, 0, GPIOB, GPIO_PIN_4);

// Mapping of the Si5351 channels to PLLs/Mixers
namespace SiChannel {
	enum {
		Source = 3,
		LO1 = 2,
		Port2LO2 = 1,
		RefLO2 = 5,
		Port1LO2 = 4,
		LowbandSource = 0,
		ReferenceOut = 6,
		FPGA = 7,
	};
}

}

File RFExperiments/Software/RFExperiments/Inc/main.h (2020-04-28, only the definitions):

#define USER_Btn_Pin GPIO_PIN_13
#define USER_Btn_GPIO_Port GPIOC
#define TRACE2_Pin GPIO_PIN_7
#define TRACE2_GPIO_Port GPIOF
#define MCO_Pin GPIO_PIN_0
#define MCO_GPIO_Port GPIOH
#define RMII_MDC_Pin GPIO_PIN_1
#define RMII_MDC_GPIO_Port GPIOC
#define RMII_REF_CLK_Pin GPIO_PIN_1
#define RMII_REF_CLK_GPIO_Port GPIOA
#define RMII_MDIO_Pin GPIO_PIN_2
#define RMII_MDIO_GPIO_Port GPIOA
#define RMII_CRS_DV_Pin GPIO_PIN_7
#define RMII_CRS_DV_GPIO_Port GPIOA
#define RMII_RXD0_Pin GPIO_PIN_4
#define RMII_RXD0_GPIO_Port GPIOC
#define RMII_RXD1_Pin GPIO_PIN_5
#define RMII_RXD1_GPIO_Port GPIOC
#define LD1_Pin GPIO_PIN_0
#define LD1_GPIO_Port GPIOB
#define PLL1_CE_Pin GPIO_PIN_7
#define PLL1_CE_GPIO_Port GPIOE
#define PLL1_LE_Pin GPIO_PIN_8
#define PLL1_LE_GPIO_Port GPIOE
#define PLL1_RF_Pin GPIO_PIN_9
#define PLL1_RF_GPIO_Port GPIOE
#define PLL2_CE_Pin GPIO_PIN_10
#define PLL2_CE_GPIO_Port GPIOE
#define PLL2_LE_Pin GPIO_PIN_11
#define PLL2_LE_GPIO_Port GPIOE
#define PLL2_RF_Pin GPIO_PIN_12
#define PLL2_RF_GPIO_Port GPIOE
#define PLL1_LD_Pin GPIO_PIN_13
#define PLL1_LD_GPIO_Port GPIOE
#define PLL2_LD_Pin GPIO_PIN_14
#define PLL2_LD_GPIO_Port GPIOE
#define RMII_TXD1_Pin GPIO_PIN_13
#define RMII_TXD1_GPIO_Port GPIOB
#define LD3_Pin GPIO_PIN_14
#define LD3_GPIO_Port GPIOB
#define STLK_RX_Pin GPIO_PIN_8
#define STLK_RX_GPIO_Port GPIOD
#define STLK_TX_Pin GPIO_PIN_9
#define STLK_TX_GPIO_Port GPIOD
#define USB_PowerSwitchOn_Pin GPIO_PIN_6
#define USB_PowerSwitchOn_GPIO_Port GPIOG
#define USB_OverCurrent_Pin GPIO_PIN_7
#define USB_OverCurrent_GPIO_Port GPIOG
#define USB_SOF_Pin GPIO_PIN_8
#define USB_SOF_GPIO_Port GPIOA
#define USB_VBUS_Pin GPIO_PIN_9
#define USB_VBUS_GPIO_Port GPIOA
#define USB_ID_Pin GPIO_PIN_10
#define USB_ID_GPIO_Port GPIOA
#define USB_DM_Pin GPIO_PIN_11
#define USB_DM_GPIO_Port GPIOA
#define USB_DP_Pin GPIO_PIN_12
#define USB_DP_GPIO_Port GPIOA
#define TMS_Pin GPIO_PIN_13
#define TMS_GPIO_Port GPIOA
#define TCK_Pin GPIO_PIN_14
#define TCK_GPIO_Port GPIOA
#define TRACE_Pin GPIO_PIN_15
#define TRACE_GPIO_Port GPIOA
#define TX_SWITCH_Pin GPIO_PIN_2
#define TX_SWITCH_GPIO_Port GPIOD
#define RMII_TX_EN_Pin GPIO_PIN_11
#define RMII_TX_EN_GPIO_Port GPIOG
#define RMII_TXD0_Pin GPIO_PIN_13
#define RMII_TXD0_GPIO_Port GPIOG
#define LD2_Pin GPIO_PIN_7
#define LD2_GPIO_Port GPIOB

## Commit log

2020-04-02 Synthesizer and first mixer board
    [MAX2871.brd, MAX2871.sch, RLB_LTC5510.brd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]
2020-04-02 Si5351C clock distributor board
    [Si5351.brd, Si5351.sch]
2020-04-02 Second mixer/ADC driver board
    [LT5560.brd, LT5560.sch]
2020-04-10 Gerber and BOM
    [LT5560.brd, LT5560.csv, MAX2871.csv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]
2020-04-10 CubeMX Project with SI5351 driver
2020-04-11 Minimum VNA signal flow implemented
2020-04-12 USB CDC + ADC timer trigger bugfix
    [New_configuration.cfg]
2020-04-12 Device driver on PC side
2020-04-15 Central data model, selectable traces for plots, fullscreen plot, buttons for frequency/span changes
2020-04-17 OSLT calibration mathe
2020-04-23 Bugfixes and tests
    [LT5560.brd, LT5560.sch, MAX2871.brd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]
2020-04-24 Working S11 measurement and simple calibration menu
2020-04-25 ADCs sampling continuouly (gets rid of frequent phase jumps due to timer divider, still some phase creapage
2020-04-26 More ADC samples per signal period, full two-port operation
2020-04-27 1.IF moved (fixed random error on PLL relock, probably due to leakage)
    [RFExperiments.ioc, VNA.cpp]
2020-04-28 Queued connection for datapoint transfer, calibration with progress dialog
2020-04-28 Functioning menu entries for full calibration, sweep speed improved
2020-04-30 Partial schematic + Layout
    [VNA.brd, VNA.sch]
2020-05-01 Partial routing
    [VNA.brd, VNA.sch]
2020-05-03 Shield outline and small layout fixes
    [VNA.brd, VNA.sch, VNA_bottom.dxf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]
2020-05-03 Mixers disabled by default, GND plane cutouts under high-speed component pads
    [VNA.brd, VNA.sch]
2020-05-03 Testpoints + Gerber
    [VNA.brd, VNA.sch]
2020-05-05 BOM + AUX4->RESET
    [VNA.brd, VNA.csv, VNA.ods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]
2020-05-05 MCP33131/SPI command driver
2020-05-07 BOM adjustments
    [VNA.ods]
2020-05-07 Bugfixes SPI commands
2020-05-09 Save/load calibration to file
2020-05-10 Sync signal for switching regulator implemented
2020-05-10 Piecewise curve plotting, timestamp on calibration data
2020-05-11 Fix phase align issue for 2.LO
    [Si5351C.cpp, Si5351C.hpp, VNA.cpp]
2020-05-12 Various minor improvements and bugfixes/workarounds for HW mistakes
    [New_configuration.cfg, VNA.sch]
2020-05-14 ADC SPI frequency reduced + further bugfixes
    [App.cpp, FPGA.cpp, VNA.cpp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]
2020-05-14 Workaround for spurious freezing sampling module (needs proper fix)
    [App.cpp, VNA.cpp]
2020-05-15 SPI CS high reload bug fixed, MCP33131 rewritten as statemachine
    [App.cpp, FPGA.cpp, VNA.cpp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]
2020-05-16 Added temperature measurement for PLLs
2020-05-26 ADC min/max, support for sweep halt/resume before sampling each point
2020-05-26 Part values of final IF filter adjusted
    [VNA.brd, VNA.sch]
2020-05-28 Lowband source implemented, faster algorithm for PLL divider selection
    [VNA.brd, VNA.sch]
2020-05-29 Calibration kit configuration dialog and its coefficients taken into account during calibration
2020-05-30 Fixed calculation mistakes in calibration kit routines
    [VNA.cpp]
2020-05-31 touchstone and calibration kit measurement support
2020-06-04 Bugfixes in calibration + preparations for different traces
    [VNA.cpp]
2020-06-08 Trace dialog/widget completed
2020-06-09 Smithchart for traces
2020-06-13 Bodeplot implemented with trace model
2020-06-14 Import touchstone to traces
2020-06-15 Bugfixes trace import/edit
2020-06-17 Touchstone/Trace export
2020-06-23 Impedance matching schematic images + two Cs/Ls bugfixes
2020-06-24 Fixed averaging for trace model
    [main.cpp]
2020-06-25 PCB markings
2020-06-25 Shielding milling picture
2020-06-25 Bugfix calkit dialog/screenshot antenna
2020-07-06 Add calibration coefficients as traces, update plots if marker changed while data constant
2020-08-06 Support for calibration kit measurements (untested)
2020-08-06 Improved device handling, preparations for differentiating between multiple connected devices
2020-08-08 Hide markers on bodeplot if trace is invisible
2020-08-08 Device info in statusbar
2020-08-09 Calibration toolbar/menu/dialog + general bugfixes
2020-08-12 Preparations for loading/saving calibration trace data
2020-08-12 Measurements + top cover layout
    [Isolation.ods]
2020-08-13 CubeMX CDC driver adjusted to custom class
2020-08-13 Device log accessable via additional USB endpoint
2020-08-14 device code cleanup
2020-08-14 Fix deadlock on device disconnect on windows/minGW
2020-08-14 Calibration trace data save/open
2020-08-16 Calibration kit stored with calibration traces
2020-08-16 Device specific default calibration + minor bugfixes
2020-08-16 dedicated trace import dialog, touchstone import moved to traceWidget
2020-08-24 CAD files for aluminium cover
    [BottomCover.step, TopCover.step]
2020-09-14 SweepConfig format changed to allow different settling times and samples for every point

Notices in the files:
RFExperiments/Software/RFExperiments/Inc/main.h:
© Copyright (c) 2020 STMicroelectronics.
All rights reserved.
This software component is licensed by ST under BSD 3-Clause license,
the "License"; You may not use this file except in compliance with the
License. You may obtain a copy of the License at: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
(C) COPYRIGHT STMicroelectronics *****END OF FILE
